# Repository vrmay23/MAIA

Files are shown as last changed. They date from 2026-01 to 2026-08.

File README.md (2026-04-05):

# MAIA
ADAS for blind dogs!

## Third-Party Dependencies

This project uses the VL53L5CX Ultra Lite Driver (ULD) from
STMicroelectronics, licensed under BSD-3-Clause.

The ULD is NOT included in this repository. It is downloaded
automatically at build time via the ESP-IDF Component Manager
using the manifest at `components/drivers/vl53l5cx/idf_component.yml`.

- Source: https://github.com/STMicroelectronics/stm32-vl53l5cx
- License: BSD-3-Clause, (c) STMicroelectronics

### Integration approach

The ST ULD provides the sensor core logic (`vl53l5cx_api.c`)
and expects the user to implement a platform layer (`platform.h`)
with I2C and delay callbacks.

MAIA provides its own `platform.h` and `vl53l5cx_platform.c`
using the ESP-IDF v6.0 new I2C master API. The ST `porting/`
directory is intentionally excluded from the build — only
`modules/vl53l5cx_api.c` is compiled from the ULD.

This keeps the repository 100% Apache 2.0 while the ST ULD
is consumed as an external dependency at build time.

## Building
idf.py build

The Component Manager downloads the ST ULD automatically.
No manual steps required.

## ⚠️ DISCLAIMER

THIS IS AN EXPERIMENTAL OPEN-SOURCE PROJECT FOR EDUCATIONAL
AND RESEARCH PURPOSES ONLY.

No Warranty of Operation: This ADAS system for blind dogs is
provided on an "AS IS" BASIS, without warranties or conditions
of any kind, either express or implied. ToF sensors are subject
to environmental interference, signal noise, blind spots, and
false negatives/positives.

Assumption of Risk: The use of this hardware and firmware on
animals is at the sole discretion and risk of the user/builder.
The author(s) shall not be held liable for any collisions,
injuries, property damage, or any other incidents resulting
from the use or failure of this device.

Not a Medical or Safety Device: This project is NOT a certified
medical or assistive device. It is not a substitute for human
supervision, professional veterinary advice, or proper
orientation training for visually impaired animals.

Hardware Safety: The builder is responsible for ensuring
electrical safety (battery insulation, thermal management) and
mechanical integrity (secure attachment to the animal) to
prevent risks of shock, fire, or physical harm.



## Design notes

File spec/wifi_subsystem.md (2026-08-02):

# MAIA WiFi Subsystem — Design Specification

    Version:   v2.0 (reflects implemented code)
    Date:      2026-08-02
    Author:    Vinicius May
    Target:    ESP32-S3-WROOM-1U-N16R8, ESP-IDF v6.0.0
    Branch:    feat/driver_radio_wifi
    Status:    Phases 1-4 implemented and hardware-verified. Phases 5
               (partial), 6-9 not implemented — see section 15.

    v2.0  Rewritten to describe what actually shipped, not just what was
          designed. Two structural changes from v1.2:

          1. Driver-purity correction. components/drivers/wifi/ no
             longer contains reconnect policy or boot-decision logic
             (v1.2's "RECONNECT POLICY" and MAIA_WIFI_MODE_AUTO
             sections). Both moved to main/tests/test_wifi.c, which
             plays the role of the app/service layer until one exists.
             The driver now does exactly one thing: radio mechanism,
             translated events, nothing else. See section 4.1.

          2. components/services/wifi_prov_service/ implements only
             the ESP-IDF wifi_provisioning manager path (protocomm over
             SoftAP). The custom captive portal designed in v1.1/v1.2
             section 8 (browser path, captive DNS, shared httpd) was
             NOT built — the service directory is also renamed from
             the originally planned wifi_provisioning to
             wifi_prov_service, because that name collides with
             ESP-IDF's own built-in component of the same name.

          Basic LED feedback exists (main/tests/test_wifi.c,
          led_feedback_task()), but as test-code UI glue, not a real
          board service — OLED and buttons are still untouched.

    v1.2  Captive portal designed to coexist with the manager on one
          HTTP server. (Portal never implemented — see v2.0 note.)
    v1.1  Provisioning moved to the IDF wifi_provisioning manager over
          SoftAP.
    v1.0  Initial draft: custom captive portal + WPS.

---

## 1. Purpose and Scope

MAIA needs network connectivity for one reason: **periodically syncing logged
sensor data to a server** (`MAIA_WIFI_SYNC_INTERVAL_MIN`, default 10 min). It
is not a connected product in the always-online sense — it is a
battery-powered harness on a dog that phones home when near a known network.

This document specifies what is actually built:

- the WiFi driver (`components/drivers/wifi/`) — radio mechanism only,
- the provisioning service (`components/services/wifi_prov_service/`) — gets
  the device from "no credentials" to "connected" via the ESP-IDF
  provisioning manager,
- the test harness (`main/tests/test_wifi.c`) — which currently also carries
  the reconnect policy, boot orchestration, and LED feedback that a real
  app/service layer will eventually own,
- the Kconfig surface tying it together.

**Out of scope, not yet started:** the data sync client, OTA, BLE, the
camera, the custom captive portal, OLED/button integration, WPS, MaiaProvApp's
custom endpoints. See section 15 for what each of those needs.

---

## 2. The Core Problem

MAIA must join the tutor's home WiFi. That network's SSID and password are
unknown at build time and differ per user. The device has:

- an SSD1306 128x32 OLED — 4 lines of 25 characters at 5x8 font (not wired to
  WiFi state yet — see section 12),
- one wired button (`BTN_01`, GPIO9) plus one unused (`BTN_02`, GPIO43),
- no keyboard, no touchscreen, no serial access for the end user in the field
  (serial is how *we* debug it on the bench; a tutor will never see it).

### 2.1 On-device text entry is rejected outright

A WPA2 password is up to 63 characters from a 95-character alphabet. With two
buttons the only workable scheme is "next character / confirm" — up to 95
presses per character. **This is not implemented in any form**, and is not
planned. All credential entry happens on the tutor's phone.

### 2.2 The reframing

The device does not need an input UI. **MAIA raises an Access Point, and the
tutor's phone supplies the screen and the keyboard.**

### 2.3 The fact that constrains every option

**A phone cannot read the password of the WiFi network it is currently joined
to.** Android masked `WifiConfiguration.preSharedKey` from the start and closed
the API entirely in Android 10; iOS never exposed it. Consequently **no
transport eliminates typing** — the tutor types the home WiFi password once,
on their own phone, regardless of which client app does the pairing.

### 2.4 Alternatives evaluated

| Approach | Verdict |
|---|---|
| **SoftAP + IDF `wifi_provisioning` manager** | **Implemented.** Proven protocol, crypto and PoP built in. Client today: Espressif's free "ESP SoftAP Prov" app |
| Custom captive portal (HTML + captive DNS) | **Designed (v1.1/v1.2), not implemented.** Its advantage — zero install — didn't get built this pass; the manager path covers the actual need today |
| BLE transport | Not started. One-line scheme swap in the manager config when needed; deferred until MaiaProvApp exists |
| WPS push-button (PBC) | Not started. Optional shortcut, never a dependency, when it lands |
| SmartConfig / ESP-Touch, Web Bluetooth, camera+QR, OLED QR, on-device text entry | Rejected — see v1.x history for the reasoning per option; unchanged in v2.0 |

---

## 3. Solution Overview (as built)

```
Boot (MAIA_TEST_WIFI_MODE_CONNECT, MAIA_WIFI_MODE_PROVISIONING)
 └─> wifi_prov_service_run()
      └─> maia_wifi_is_provisioned()?
           ├─ yes ─> connect directly with stored creds (bounded retry,
           │         no AP raised) — verified on hardware: WPA3-SAE home
           │         network, IP obtained in ~4s
           └─ no  ─> SoftAP "PROV_MAIA_A4F3" + wifi_provisioning manager
                      OLED/LED do not show the PoP yet — it prints to the
                      serial log only (see section 12)
```

| Client | Path | Must install | Status |
|---|---|---|---|
| ESP SoftAP Prov (Espressif) | Standard protocomm endpoints | Their free app | **Implemented, hardware-verified** |
| Phone browser | Captive portal | nothing | Designed (v1.2 §8.4), not built |
| MaiaProvApp (future) | Protocomm + custom endpoints | Our own app | Designed (§9), not built |

The three-client idea from v1.2 — one AP, one shared HTTP server — is
unaffected as a *design*; it simply hasn't been built yet, because only the
protocomm path was in scope for this pass.

---

## 4. Component Architecture

```
components/drivers/wifi/                  ← radio mechanism only
├── include/maia_wifi.h                     public API + SCOPE doc (§4.1)
├── src/maia_wifi.c                         L1 init/deinit, state, is_provisioned()
├── src/maia_wifi_sta.c                     L2 station: start/connect/stop, raw events
├── src/maia_wifi_ap.c                      L3 diagnostic AP
├── src/maia_wifi_scan.c                    L4 scan
├── src/maia_wifi_priv.h                    internal cross-file interface
├── Kconfig                                 empty — see repo convention note below
└── CMakeLists.txt                          vestigial, matches sibling drivers (§4.2)

components/services/wifi_prov_service/    ← provisioning policy
├── include/wifi_prov_service.h             single entry point: wifi_prov_service_run()
├── src/wifi_prov_service.c                 manager lifecycle, PoP, event handling
├── Kconfig                                 empty stub
└── CMakeLists.txt                          real component (§4.3)

main/tests/test_wifi.c                    ← today's stand-in for app/service policy
                                             reconnect policy, boot orchestration,
                                             LED feedback (§4.4)
```

Compared to the file list v1.2 planned (`wifi_prov_portal.c`, `wifi_prov_dns.c`,
`wifi_prov_custom_ep.c`, `wifi_prov_ui.c`, `www/portal.html`), none of those
exist. Only the manager-lifecycle file was built.

### 4.1 The driver-purity correction

Early in this branch, `components/drivers/wifi/` briefly contained a
"reconnect policy" (retry counting, exponential backoff, a give-up decision)
and a `maia_wifi_auto_start()` boot-decision function. On review, both were
recognized as **product policy wearing a driver's clothes** — a NuttX-style
driver exposes primitives and reports raw events; it does not decide how many
times to retry or what the device should do when unconfigured. Both were
removed from the driver:

- The retry/backoff/give-up state machine moved to
  `connect_with_retry_policy()` in `test_wifi.c`, built entirely on the
  driver's public API (`maia_wifi_sta_connect()`, the raw
  `MAIA_WIFI_EVENT_STA_DISCONNECTED` reason code).
- `maia_wifi_auto_start()` was deleted outright; the boot decision
  (`is_provisioned() → connect, else Kconfig seed → connect, else raise the
  diagnostic AP`) is now inlined in `test_wifi_connect()`'s
  `MAIA_WIFI_MODE_AUTO` branch.

This forced two API changes: `maia_wifi_sta_start()` now only brings the
interface up (mode, config, power-save) and no longer calls
`esp_wifi_connect()` itself; a new `maia_wifi_sta_connect()` is the separate,
repeatable primitive a retry loop calls. The state enum lost
`STA_OFFLINE`/`ERROR` (policy conclusions) and the event enum lost
`STA_AUTH_FAILED`/`NO_AP_FOUND` (policy interpretations) — `STA_DISCONNECTED`
now just carries the raw `WIFI_REASON_*` code and lets the caller decide what
it means.

**`maia_wifi_is_provisioned()` stayed in the driver.** It is a read-only query
against `esp_wifi`'s own persisted config — it doesn't decide anything, only
reports a fact — which is different in kind from the boot orchestration that
moved out.

### 4.2 Why `components/drivers/wifi/CMakeLists.txt` is unused

ESP-IDF's component discovery is non-recursive: it only looks at immediate
children of `components/`. Since `components/drivers` itself has a
`CMakeLists.txt` (the real aggregator, hand-listing every driver's sources),
IDF never looks inside `components/drivers/wifi/` for a nested component —
its `CMakeLists.txt` is display-only, matching the same (also-unused) pattern
already present in `mpu6050/`, `ssd1306/`, `lsm6dsox/`. The actual build
wiring is in `components/drivers/CMakeLists.txt`'s `DRV_SRCS` list, gated on
`CONFIG_MAIA_WIFI_ENABLE`.

### 4.3 Why `wifi_prov_service` needed a name change and `EXTRA_COMPONENT_DIRS`

Two build-system issues surfaced while wiring this component in, both fixed
and worth recording so they aren't rediscovered the hard way:

1. **Name collision.** The service was originally going to live at
   `components/services/wifi_provisioning/` — but ESP-IDF ships its own
   built-in component named exactly `wifi_provisioning`
   (`$IDF_PATH/components/wifi_provisioning`, the manager itself). Two
   same-named components in the build graph is ambiguous. Renamed the
   directory (and the header/source files) to `wifi_prov_service`.

2. **`components/services/` is one level too deep to auto-discover.** IDF's
   default component search is `components/` plus anything in
   `EXTRA_COMPONENT_DIRS`, and for each of those it only looks at *immediate*
   subdirectories. `components/services/wifi_prov_service/` is two levels
   under `components/`, so without help it is invisible — confirmed by
   checking `project_description.json`'s `all_component_info`: the five
   pre-existing `services/*` stubs (`obstacle_detection`, `haptic_feedback`,
   `power_manager`, `data_logger`, `status_monitor`) were *never* being
   discovered at all before this change, despite having real
   `idf_component_register()` calls in their `CMakeLists.txt` — dormant
   scaffolding, not dead code. Fixed by adding
   `set(EXTRA_COMPONENT_DIRS "${CMAKE_CURRENT_LIST_DIR}/components/services")`
   to the root `CMakeLists.txt`, which incidentally makes those five
   pre-existing stubs discoverable too (still not wired into `main`'s
   `REQUIRES`, so they remain inert).

3. **A `REQUIRES` gotcha, distinct from the two above.** Once discoverable,
   `wifi_prov_service` still needed to not be compiled when
   `MAIA_WIFI_ENABLE=n` (its code uses Kconfig symbols that live inside
   `depends on MAIA_WIFI_ENABLE` menus and vanish from `sdkconfig.h`
   entirely when it's off). The obvious fix —
   `if(CONFIG_MAIA_WIFI_ENABLE) list(APPEND ... wifi_prov_service) endif()`
   around the `REQUIRES` argument — **does not work**: ESP-IDF resolves each
   component's `REQUIRES`/`PRIV_REQUIRES` in an early pass, before Kconfig
   values from the actual `sdkconfig` are reliably available, so the
   conditional silently evaluates against a stale/default context rather
   than the real configuration (confirmed by hitting it directly: the
   component vanished from `main`'s resolved `reqs` even with
   `MAIA_WIFI_ENABLE=y` set on disk). `SRCS` conditionals do not have this
   problem — they're evaluated later, with the real `sdkconfig` in hand,
   which is why `test_wifi.c`'s inclusion is still safely gated that way.
   The fix: `wifi_prov_service` is `REQUIRES`'d **unconditionally**, and
   `wifi_prov_service.c`'s entire body (past the includes) is wrapped in
   `#if CONFIG_MAIA_WIFI_ENABLE ... #endif`, so the component always builds
   but compiles to an empty, harmless translation unit when WiFi is off.

### 4.4 Why policy still lives in test code

`components/app/src/app.c`'s `app_init()` is still a TODO stub — nothing in
the real application calls into WiFi at all yet. Until that changes,
`main/tests/test_wifi.c` (`MAIA_TEST_WIFI_MODE_CONNECT`) is the only caller,
so it necessarily carries what an app/service layer will eventually own:
`connect_with_retry_policy()`, the `MAIA_WIFI_MODE` boot-decision branches, and
`led_feedback_task()`. None of this is exercised by production code today —
moving it there is future work, not a rename.

---

## 5. Kconfig Design (as implemented)

Replaces the original `menu "WiFi Configuration"` in
`components/maia_board/Kconfig`. Per this repo's convention (confirmed by
inspecting every existing driver), **all Kconfig content lives in
`components/maia_board/Kconfig`** — the per-component `Kconfig` files
(`components/drivers/wifi/Kconfig`, `components/services/wifi_prov_service/Kconfig`)
are empty stubs matching the rest of the tree, not the per-component split the
v1.x drafts of this document assumed.

### 5.1 Mode selection

```kconfig
choice MAIA_WIFI_MODE
    prompt "WiFi operating mode"
    depends on MAIA_WIFI_ENABLE
    default MAIA_WIFI_MODE_AUTO
    help
        Selects what the device should do at boot. Not read by the
        driver — this is consulted by whatever code orchestrates the
        driver's primitives (currently MAIA_TEST_WIFI_MODE_CONNECT in
        test_wifi.c).

    config MAIA_WIFI_MODE_AUTO
        bool "Auto (stored credentials -> STA, else diagnostic AP)"

    config MAIA_WIFI_MODE_STA
        bool "Station only (credentials from Kconfig)"

    config MAIA_WIFI_MODE_AP
        bool "Access Point only (diagnostic)"

    config MAIA_WIFI_MODE_PROVISIONING
        bool "Interactive provisioning (SoftAP + phone app)"
        help
            If already provisioned, connect directly. Otherwise raise
            a SoftAP and run the ESP-IDF wifi_provisioning manager
            (protocomm, security 1) so a phone can supply credentials
            at runtime. Client today: "ESP SoftAP Prov" (Espressif).
endchoice
```

**Important correction from an early version of this Kconfig:** the
"Station" and "Access Point (diagnostic)" submenus originally had
`depends on !MAIA_WIFI_MODE_AP` / `!MAIA_WIFI_MODE_STA` respectively — hiding
each other's config when one mode was selected, as a menuconfig UX nicety.
**This broke the build** the moment any mode other than the "obviously
relevant" one was selected: `components/drivers/CMakeLists.txt` compiles
`maia_wifi_ap.c` and the Station code paths *unconditionally* whenever
`MAIA_WIFI_ENABLE=y` (any mode might call `maia_wifi_ap_start()` at runtime —
e.g. Auto's fallback), and `wifi_prov_service.c` unconditionally reads
`MAIA_WIFI_STA_MAX_RETRY` for its already-provisioned connect path — so
hiding those Kconfig symbols under a mode condition made them vanish from
`sdkconfig.h` while still-compiled code referenced them. Both `depends on`
clauses were changed to depend only on `MAIA_WIFI_ENABLE`.

### 5.2 Station and diagnostic AP

Unchanged in shape from v1.2's design (`MAIA_WIFI_STA_SSID/PASSWORD`,
`MAIA_WIFI_STA_MAX_RETRY`, `MAIA_WIFI_STA_RETRY_BACKOFF_MS`,
`MAIA_WIFI_STA_POWER_SAVE`, `MAIA_WIFI_SYNC_INTERVAL_MIN`;
`MAIA_WIFI_AP_SSID_PREFIX/_APPEND_MAC/_PASSWORD/_CHANNEL/_MAX_CONN`) — see
section 5.1's correction for the `depends on` fix. `MAIA_WIFI_STA_MAX_RETRY`'s
help text now documents **two** consumers instead of one:
`test_wifi.c`'s reconnect-policy demo, and `wifi_prov_service`'s
`wifi_conn_attempts` (passed straight through to the manager).

### 5.3 Interactive Provisioning (implemented; replaces v1.2's broader design)

```kconfig
menu "Interactive Provisioning"
    depends on MAIA_WIFI_ENABLE

    config MAIA_WIFI_PROV_SSID_PREFIX
        string "Provisioning AP SSID prefix"
        default "PROV_MAIA"
        help
            The stock "ESP SoftAP Prov" app filters its scan results
            by prefix, defaulting to "PROV_". Keep it while that app
            is the client.

    config MAIA_WIFI_PROV_SSID_APPEND_MAC
        bool "Append MAC suffix to the provisioning AP SSID"
        default y

    choice MAIA_WIFI_PROV_AP_SECURITY
        prompt "Provisioning AP link security"
        default MAIA_WIFI_PROV_AP_WPA2_MAC

        config MAIA_WIFI_PROV_AP_WPA2_MAC
            bool "WPA2, password derived from device MAC"
        config MAIA_WIFI_PROV_AP_WPA2_STATIC
            bool "WPA2, static password from Kconfig"
        config MAIA_WIFI_PROV_AP_OPEN
            bool "Open network (protocomm encryption only)"
    endchoice

    config MAIA_WIFI_PROV_AP_PASSWORD
        string "Static provisioning AP password (min 8 chars)"
        default "maiamute2026"
        depends on MAIA_WIFI_PROV_AP_WPA2_STATIC

    choice MAIA_WIFI_PROV_SECURITY
        prompt "Provisioning session security"
        default MAIA_WIFI_PROV_SEC1

        config MAIA_WIFI_PROV_SEC1
            bool "Security 1 (X25519 + AES-CTR, PoP)"
            select ESP_PROTOCOMM_SUPPORT_SECURITY_VERSION_1
        config MAIA_WIFI_PROV_SEC0
            bool "Security 0 (none)"
            select ESP_PROTOCOMM_SUPPORT_SECURITY_VERSION_0
    endchoice

    config MAIA_WIFI_PROV_POP_DIGITS
        int "Proof-of-possession code length (digits)"
        default 6
        range 4 8
        depends on MAIA_WIFI_PROV_SEC1

    config MAIA_WIFI_PROV_POP_STATIC
        string "Static PoP code (empty = random per session)"
        default ""
        depends on MAIA_WIFI_PROV_SEC1
        help
            Set to script provisioning with tools/esp_prov/esp_prov.py
            without reading a fresh code off the serial log every run.
            Leave empty for real use.

    config MAIA_WIFI_PROV_TIMEOUT_MIN
        int "Provisioning timeout (minutes, 0 = never)"
        default 10
        range 0 60
endmenu
```

**Differences from the v1.2 design:**

- **No `MAIA_WIFI_PROV_SECURITY_SEC2` (SRP6a).** The current `sdkconfig`
  ships with `ESP_PROTOCOMM_SUPPORT_SECURITY_VERSION_2=y` by default and
  `_0`/`_1` both disabled — meaning `WIFI_PROV_SECURITY_0`/`_1` don't even
  exist as enum values until something `select`s them in. Each of our two
  security choices does exactly that (`select
  ESP_PROTOCOMM_SUPPORT_SECURITY_VERSION_{0,1}`), so the build works
  regardless of prior `sdkconfig` state. SEC2 needs build-time salt/verifier
  generation from a username/password pair that isn't implemented — same
  reasoning v1.2 gave for deferring it, unchanged.
- **`MAIA_WIFI_PROV_POP_STATIC` is new** — not in any v1.x draft. Added for
  bench/scripting convenience (`esp_prov.py` automation without reading a
  fresh random code off the serial log every session).
- **No `MAIA_WIFI_PROV_IFACE_PROTOCOMM` / `_IFACE_PORTAL` / `_CUSTOM_EP` /
  `MAIA_WIFI_PROV_CLIENT`.** These v1.2 symbols existed to let the (never
  built) portal and the manager coexist, and to gate the (never built)
  custom endpoints for MaiaProvApp. None of that code exists, so — per this
  project's working rule of never shipping a Kconfig option with no
  implementation behind it — none of those symbols exist either. When the
  portal or the custom endpoints get built, their Kconfig lands with them.

### 5.4 Status indication

```kconfig
menu "Status indication"
    depends on MAIA_WIFI_ENABLE

    config MAIA_LED_BLINK_FREQ_AP_HZ
        int "LED blink frequency in AP mode (Hz)"
        default 5
        range 1 100

    config MAIA_LED_BLINK_FREQ_STA_HZ
        int "LED blink frequency while connecting (Hz)"
        default 1
        range 1 100
endmenu
```

These two symbols predate this branch (originally both defaulted to 10 Hz,
which conveys no information since a single indistinguishable rate can't tell
two states apart — fixed to 5/1 Hz here). They are now actually consumed, by
`test_wifi.c`'s `led_feedback_task()` (section 8.4) — previously they were
declared but nothing read them.

### 5.5 Test Kconfig

`MAIA_TEST_WIFI_MODE` has **three** options, not five:

```kconfig
choice MAIA_TEST_WIFI_MODE
    prompt "WiFi test mode"
    depends on MAIA_TEST_WIFI
    default MAIA_TEST_WIFI_MODE_SUITE

    config MAIA_TEST_WIFI_MODE_SUITE
        bool "Basic test suite"
    config MAIA_TEST_WIFI_MODE_SCAN
        bool "Network scan"
    config MAIA_TEST_WIFI_MODE_CONNECT
        bool "Exercise connectivity (per WiFi operating mode)"
        help
            Runs whatever MAIA_WIFI_MODE selects — Auto / Station / AP
            / Provisioning — entirely from code outside the driver.
endchoice

config MAIA_TEST_WIFI_LED_FEEDBACK
    bool "Blink status LED to reflect WiFi state"
    default y
    depends on MAIA_TEST_WIFI_MODE_CONNECT
    help
        Runs led_feedback_task() (section 8.5) alongside the
        connectivity test. Disable to isolate an LED-related symptom
        from the blink task itself, or if the status LED isn't wired
        the way MAIA_LED_STATUS_GPIO expects on a given board revision.
```

**`CONFIG_MAIA_TEST_WIFI` depends on `MAIA_WIFI_ENABLE`, same as every other
device test in this codebase depends on its device being enabled** (compare
`MAIA_TEST_TEMPERATURE_SENSOR` → `MAIA_DS18B20_ENABLE`, `MAIA_TEST_IMU` →
`MAIA_IMU_MPU6050`). This is not a special case introduced by this feature —
it's the established pattern. It surfaced as confusing in practice once:
with `MAIA_WIFI_ENABLE` toggled off (no comment line for it appears in
`sdkconfig` at all when off — Kconfig emits nothing, not even
`# CONFIG_MAIA_TEST_WIFI is not set`, for a symbol whose `depends on` isn't
satisfied), the entire WiFi test vanishes from `menuconfig` with no visible
trace of why. The test was never missing; the device it depends on was off.

An earlier iteration had five options (`SUITE`/`SCAN`/`STA`/`AP`/`AUTO`),
duplicating the concept `MAIA_WIFI_MODE` already existed to express.
Collapsed into `CONNECT`, whose behavior branches on the (kept, unchanged)
`MAIA_WIFI_MODE` choice — one boot-mode concept, not two.

---

## 6. State Machine (as implemented)

The driver's own state machine is now deliberately small — see section 4.1:

```mermaid
stateDiagram-v2
    [*] --> IDLE
    IDLE --> STA_CONNECTING: maia_wifi_sta_connect()
    STA_CONNECTING --> STA_CONNECTED: IP_EVENT_STA_GOT_IP
    STA_CONNECTING --> IDLE: WIFI_EVENT_STA_DISCONNECTED
    STA_CONNECTED --> IDLE: WIFI_EVENT_STA_DISCONNECTED
    IDLE --> AP_RUNNING: maia_wifi_ap_start()
    AP_RUNNING --> IDLE: maia_wifi_ap_stop()
```

No "give up", "offline", or "error" state exists in the driver — a disconnect
always lands back in `IDLE` with the raw reason code handed to the caller.
Everything downstream of that (section 4.4 / 8) is the caller's problem:

```mermaid
stateDiagram-v2
    [*] --> Idle
    Idle --> Connecting: sta_start() + sta_connect()
    Connecting --> Connected: STA_GOT_IP
    Connecting --> Connecting: STA_DISCONNECTED (auth/transient, retries left)\nbackoff, sta_connect() again
    Connecting --> GaveUp: STA_DISCONNECTED (auth, retries exhausted)
    Connecting --> GaveUp: STA_DISCONNECTED (out of range) — no retry at all
    Connecting --> GaveUp: STA_DISCONNECTED (transient, retries exhausted)
    Connected --> [*]
    GaveUp --> [*]
```

This second diagram is `connect_with_retry_policy()` in `test_wifi.c` — it
does not exist as driver states, only as caller-side logic reacting to the
driver's plain events.

---

## 7. Driver API — `maia_wifi.h` (as implemented)

```c
typedef enum
{
  MAIA_WIFI_STATE_IDLE = 0,
  MAIA_WIFI_STATE_STA_CONNECTING,
  MAIA_WIFI_STATE_STA_CONNECTED,
  MAIA_WIFI_STATE_AP_RUNNING,
} maia_wifi_state_t;

typedef enum
{
  MAIA_WIFI_EVENT_STA_CONNECTED = 0,  /* L2 associated, no IP yet        */
  MAIA_WIFI_EVENT_STA_DISCONNECTED,   /* data -> stack-local uint8_t
                                       * raw WIFI_REASON_* code, valid
                                       * only for the callback's
                                       * duration                        */
  MAIA_WIFI_EVENT_STA_GOT_IP,
  MAIA_WIFI_EVENT_AP_STARTED,
  MAIA_WIFI_EVENT_AP_CLIENT_JOINED,
  MAIA_WIFI_EVENT_AP_CLIENT_LEFT,
  MAIA_WIFI_EVENT_SCAN_DONE,
} maia_wifi_event_t;

/* L1 - Core */
esp_err_t          maia_wifi_init(maia_wifi_callback_t cb);
esp_err_t          maia_wifi_deinit(void);
maia_wifi_state_t  maia_wifi_get_state(void);
esp_err_t          maia_wifi_get_mac_suffix(char *out, size_t len);
bool               maia_wifi_is_provisioned(void);

/* L2 - Station (bring-up and association are separate primitives —
 *      this is what makes a caller-side retry loop possible without
 *      redoing setup each attempt) */
esp_err_t maia_wifi_sta_start(const maia_wifi_creds_t *creds);  /* NULL = stored */
esp_err_t maia_wifi_sta_connect(void);
esp_err_t maia_wifi_sta_stop(void);
esp_err_t maia_wifi_sta_get_ip(esp_netif_ip_info_t *ip);
esp_err_t maia_wifi_sta_get_rssi(int8_t *rssi);

/* L3 - Access Point (diagnostic only) */
esp_err_t maia_wifi_ap_start(void);
esp_err_t maia_wifi_ap_stop(void);

/* L4 - Scan */
esp_err_t maia_wifi_scan(maia_wifi_ap_info_t *results, size_t max,
                         size_t *found);
```

Removed relative to earlier drafts: `maia_wifi_auto_start()` (section 4.1),
`MAIA_WIFI_STATE_STA_OFFLINE`/`_ERROR`, `MAIA_WIFI_EVENT_STA_AUTH_FAILED`/
`_NO_AP_FOUND`. No WPS (L5) — not started.

---

## 8. Provisioning Service — `wifi_prov_service` (as implemented)

### 8.1 Entry point

```c
esp_err_t wifi_prov_service_run(void);   /* blocking */
```

That is the entire public API. It:

1. Calls `maia_wifi_init(NULL)` — idempotent (no-ops if the caller already
   initialized the driver, e.g. `test_wifi_run()` does, with its own
   callback; `wifi_prov_service_run()` doesn't need a driver-level callback
   of its own since it polls state / uses the manager's dedicated callback
   instead — see 8.3).
2. Branches on `maia_wifi_is_provisioned()`:
   - **true** → `connect_stored_credentials()`: `maia_wifi_sta_start(NULL)`,
     then up to `MAIA_WIFI_STA_MAX_RETRY` rounds of `maia_wifi_sta_connect()`
     with a bounded per-attempt timeout, polling `maia_wifi_get_state()`.
     Deliberately simpler than `test_wifi.c`'s reconnect-policy demo (no
     reason-code classification, no exponential backoff) — this is the
     service's own, plainer "just try N times" policy for the boring case
     where credentials already work.
   - **false** → `run_interactive_provisioning()` (8.2).

### 8.2 Interactive provisioning

```c
wifi_prov_mgr_config_t cfg = {
    .scheme               = wifi_prov_scheme_softap,
    .scheme_event_handler = WIFI_PROV_EVENT_HANDLER_NONE,
    .app_event_handler    = { .event_cb = prov_event_cb, .user_data = &ctx },
    .wifi_prov_conn_cfg   = { .wifi_conn_attempts = CONFIG_MAIA_WIFI_STA_MAX_RETRY },
};
wifi_prov_mgr_init(cfg);
/* build_service_name() -> "PROV_MAIA_A4F3" (prefix + MAC suffix, reusing
 * maia_wifi_get_mac_suffix()) */
/* build_ap_password() -> MAC-derived / static / NULL (open), per Kconfig */
/* build_pop() -> MAIA_WIFI_PROV_POP_STATIC if set, else N random digits
 * from esp_random() */
wifi_prov_mgr_start_provisioning(WIFI_PROV_SECURITY_1, pop, ssid, service_key);
/* block on an EventGroup for CRED_SUCCESS or CRED_FAIL, with a timeout
 * derived from MAIA_WIFI_PROV_TIMEOUT_MIN (or portMAX_DELAY if 0) */
```

`prov_event_cb()` (the manager's `app_event_handler`, not a
`maia_wifi_callback_t` — a separate, dedicated callback slot with no
interaction with the driver's own callback) maps
`WIFI_PROV_START/CRED_RECV/CRED_FAIL/CRED_SUCCESS/END` to log lines and
`EventGroup` bits. **It logs the received SSID, never the password** —
confirmed by direct code review when the question came up during testing.
On `CRED_SUCCESS` the manager auto-stops itself (emits `WIFI_PROV_END` on its
own); on `CRED_FAIL` or timeout, `wifi_prov_mgr_stop_provisioning()` is called
explicitly. Either way, `wifi_prov_mgr_deinit()` follows once `WIFI_PROV_END`
is observed (or a bounded wait for it elapses).

On success, **the station is already connected** — the manager did the
`esp_wifi_connect()` internally as part of verifying the submitted
credentials. The caller does not need to call `maia_wifi_sta_start()`/
`_connect()` afterward; `maia_wifi_get_state()` already reflects
`STA_CONNECTED` because the driver's event handlers observe `WIFI_EVENT`/
`IP_EVENT` unconditionally, regardless of who initiated the connection
attempt (see the "no conflict" note in `wifi_prov_service.h`).

### 8.3 No conflict with the driver, verified

This was a design requirement, not just a hope, and it held up under actual
hardware testing:

- The driver's own STA/AP event handlers keep running the entire time the
  manager is active — they only translate events into driver state, never
  call `esp_wifi_connect()`/`disconnect()`/`set_mode()` themselves (only
  `maia_wifi_sta_start()`/`_connect()`/`_stop()` and `maia_wifi_ap_start()`/
  `_stop()` do that), and this service never calls those while the manager
  owns the radio.
- `maia_wifi_init()`'s `g_initialized` guard makes the service's own call to
  it a safe no-op when the caller (`test_wifi_run()`) already initialized the
  driver with its own callback.
- Hardware confirmation: a real device, already provisioned onto a WPA3-SAE
  home network, connected cleanly through `connect_stored_credentials()` —
  associated, negotiated WPA3-SAE, got an IP, all while the driver's ordinary
  event handlers ran throughout with no interference.

### 8.4 What is not implemented

- **Custom captive portal** (v1.2 §8.1/8.4/8.6: shared `httpd`, browser
  handlers, captive DNS, `portal.html`). Zero of that code exists. The
  `wifi_prov_scheme_softap_set_httpd_handle()` mechanism v1.2 designed around
  is unused because there is no second httpd to share it with.
- **OLED/LED/button UI** for provisioning (v1.2 §12). The PoP code, AP name,
  and password print to the **serial log only** — there is no on-device
  display of any of it. This matters operationally: a tutor in the field has
  no way to read the PoP code today. Basic LED *is* implemented, but as
  generic WiFi-state feedback in test code (section 8.5 below), not
  provisioning-specific UI.
- **Custom protocomm endpoints** for MaiaProvApp (section 9). Reserved in
  design, no code.
- **WPS.** Not started.

### 8.5 LED feedback (new in this pass, lives in test code)

`main/tests/test_wifi.c`'s `led_feedback_task()` polls
`maia_wifi_get_state()` every 50 ms and drives the board's status LED:

| State | LED |
|---|---|
| `AP_RUNNING` | blink at `MAIA_LED_BLINK_FREQ_AP_HZ` |
| `STA_CONNECTING` | blink at `MAIA_LED_BLINK_FREQ_STA_HZ` |
| `STA_CONNECTED` | solid on |
| `IDLE` | off |

Started at the top of `test_wifi_connect()` whenever
`CONFIG_MAIA_TEST_WIFI_LED_FEEDBACK` is set (default y, section 5.5), so it
reflects whichever `MAIA_WIFI_MODE` branch is active — including the
Provisioning one, where it is the *only* on-device feedback of state right
now (no OLED text). Both the task and its call site are compiled out
entirely when the option is off — not just skipped at runtime.
This is UI glue, explicitly not driver code, for the same reasoning as
section 4.1 — and explicitly not yet a real board service, since it lives in
test code with no app/service layer to move into yet.

---

## 9. Preparing for MaiaProvApp

Unchanged in intent from v1.2: the manager's wire protocol doesn't change
when a custom client replaces the stock app, and a transport swap
(`wifi_prov_scheme_softap` → `_ble`) is a one-line change if ever needed.

**Correction from v1.2:** there is no `MAIA_WIFI_PROV_CUSTOM_EP` Kconfig
symbol today (section 5.3) — it will be added together with the actual
endpoint implementations, not before. The reserved endpoint names and
payload shapes from v1.2 §9.1 (`maia-info`, `maia-record`, `maia-server`)
remain the intended design; none are implemented.

---

## 10. Credential Storage

Unchanged from v1.1/v1.2 and confirmed by the implementation: no MAIA-owned
store. `maia_wifi_is_provisioned()` and the manager's own
`wifi_prov_mgr_is_provisioned()` both read `esp_wifi_get_config(WIFI_IF_STA,
...)` — literally the same check (confirmed by reading the ESP-IDF source
directly: `manager.c`'s implementation is the identical `strlen(ssid) > 0`
test). No parallel copy exists to disagree with it.

---

## 11. Security Model (as implemented)

### 11.1 What's actually true today

Because the custom portal was never built, **the PoP is always
cryptographically bound** — there is no weaker, application-level PoP check
existing in parallel (v1.2 §11.3 spent significant space on an asymmetry
between a crypto-bound protocomm path and a rate-limited portal path; that
asymmetry does not exist in the shipped system, because only the protocomm
path exists). Under Security 1, the PoP string is mixed into the X25519
session-key derivation; a wrong code produces a key that cannot decrypt
anything the device sends — not an application-level rejection, and nothing
to rate-limit because there's no comparison to brute-force.

### 11.2 Threat model, updated

| Attack | Defence |
|---|---|
| Associate to the provisioning AP | Per-device WPA2 password (MAC-derived by default) |
| Complete a protocomm session without the PoP | Cryptographically impossible under Security 1 — wrong PoP yields a session key that can't decrypt the exchange |
| Brute-force the PoP online | Each guess costs a full handshake against a device only listening for `MAIA_WIFI_PROV_TIMEOUT_MIN` minutes |
| Sniff the submitted home-WiFi password | protocomm encrypts end to end, independent of the AP's own WPA2 |
| Force the device into setup mode | Only reachable when unprovisioned, or (once implemented) by explicit button press |

### 11.3 AP link security

`MAIA_WIFI_PROV_AP_WPA2_MAC` (default) derives the AP password from the base
MAC — implemented via `build_ap_password()`: `snprintf("MAIA%02X%02X%02X%02X",
mac[2..5])`, always ≥8 chars so it's always valid WPA2. Static and open
options exist for bench work, matching the original design.

### 11.4 No TLS — still correct, for a narrower reason now

v1.2 argued TLS would break captive-portal auto-detection. Since there is no
portal, that specific argument no longer applies — but the underlying
conclusion is unchanged: there's no third party on the path, and protocomm
already encrypts the payload end to end regardless of the WiFi link's own
security. Adding TLS on top would add certificate/clock problems for zero
security gain.

### 11.5 Where the real risk lives

Unchanged from v1.2 §11.6: the data sync client, not provisioning, once that
exists.

---

## 12. User Experience (current state — mostly not built)

### 12.1 What exists

Only the LED pattern in section 8.5. No OLED screens, no button-triggered
entry into provisioning, no PoP/AP-name/password displayed anywhere the tutor
could see — all of that only prints to the serial log (`ESP_LOGW`), which is
a bench/developer channel, not something a tutor in the field has access to.

### 12.2 What v1.2 designed and remains unbuilt

The two-screen OLED rotation (AP credentials / PoP code), the failure
screens with recovery instructions, the `BTN_01`/`BTN_02` mapping table, and
the multi-button driver prerequisite it depends on — all as originally
specified in v1.2 §12, none implemented. This is the actual gap between
"MAIA can be provisioned by an engineer with a laptop and a serial monitor"
(true today) and "MAIA can be provisioned by a tutor with just a phone" (not
yet true, since the tutor has no way to read the PoP code without serial
access).

---

## 13. Platform Constraints and Known Gotchas

Carried over from v1.2 (WROOM-1U needs an external antenna; ESP32-S3 is
2.4 GHz only; AP+STA share one radio/channel; endpoint registration
ordering — n/a now, no custom endpoints exist yet), plus what this pass
found in practice:

1. **WPA3-SAE works, confirmed on real hardware.** A home router running
   WPA3-SAE-only was initially suspected as a blocker; the device associated,
   negotiated `security: WPA3-SAE`, and obtained an IP without any code
   changes. ESP32-S3's WiFi stack supports SAE natively — this was never a
   real constraint, just an untested assumption.
2. **The manager's own fail-reason classification is narrower than expected,
   and can misreport.** `wifi_provisioning`'s `manager.c` only recognizes
   five `WIFI_REASON_*` codes as `WIFI_PROV_STA_AUTH_ERROR`
   (`AUTH_FAIL`, `HANDSHAKE_TIMEOUT`, `4WAY_HANDSHAKE_TIMEOUT`,
   `MIC_FAILURE`) or `WIFI_PROV_STA_AP_NOT_FOUND` (`NO_AP_FOUND`). Anything
   else — including the very common `WIFI_REASON_BEACON_TIMEOUT` (weak or
   unstable signal) — falls through a `default:` case that, with
   `wifi_conn_attempts != 0` (our configuration), leaves the fail reason at
   whatever it last was, which starts zero-initialized to
   `WIFI_PROV_STA_AUTH_ERROR`. **A weak-signal disconnect can be reported to
   the app as "wrong password" even when the password was correct.** This is
   an ESP-IDF library behavior, not something this project's code controls;
   the actual raw code is still visible in the log
   (`manager.c`: `ESP_LOGE(TAG, "Disconnect reason : %d", ...)`) before the
   misclassification happens, and is the reliable way to diagnose a
   "provisioning failed" report that doesn't match reality.
3. **`esp_random()` requires `#include <esp_random.h>`**, and MAC reads need
   `#include <esp_mac.h>` — both moved out of `esp_system.h`'s automatic
   includes in a recent ESP-IDF reorganization; the build gives a direct hint
   when this bites (`hint: esp_mac.h header file is not included by
   esp_system.h anymore`).
4. **`freertos/event_groups.h` is plural** (`event_group.h` doesn't exist) —
   caught immediately by the build, mentioned here only because it's an easy
   typo to repeat.
5. See section 4.3 for the three build-system gotchas (name collision,
   `EXTRA_COMPONENT_DIRS` depth, `REQUIRES`-vs-`SRCS` Kconfig-conditional
   reliability) — these cost more debugging time than any WiFi-specific
   issue in this pass.

---

## 14. Test Plan (as implemented)

`MAIA_TEST_WIFI` under `MAIA_TEST_SELECT`, with `MAIA_TEST_WIFI_MODE`
choosing one of three (section 5.5):

| Sub-test | Coverage |
|---|---|
| `SUITE` | init/deinit, MAC suffix formatting, `is_provisioned()` against `esp_wifi`'s stored config, state transitions with no radio activity |
| `SCAN` | Scan and print visible networks (SSID, RSSI, channel, auth mode) — also the fastest antenna sanity check |
| `CONNECT` | Runs whichever `MAIA_WIFI_MODE` selects (Auto/Station/AP/Provisioning), including the reconnect-policy demo and LED feedback. **Hardware-verified**: AP mode (phone joined, join/leave logged), Provisioning mode (already-provisioned direct connect to a WPA3-SAE network, IP obtained, no crash after fixing the NULL-queue bug below) |

**Bug found and fixed during hardware testing:** `connect_event_cb()` (the
callback registered for the whole `CONNECT` sub-test, regardless of which
`MAIA_WIFI_MODE` branch runs) unconditionally forwarded `GOT_IP`/
`DISCONNECTED` events into a queue (`s_sta_evt_q`) that is only created inside
`connect_with_retry_policy()` — used by the Auto/Station branches. The
Provisioning branch connects via `wifi_prov_service_run()` instead, never
creating that queue, yet the same globally-registered callback still fired on
its events. Result: a real device, the moment it successfully obtained an IP
through Provisioning mode, hit `xQueueGenericSend` on a NULL queue handle and
asserted/rebooted — a crash exactly *at* the moment of success. Fixed with a
NULL check at the top of the callback. Caught by a user running the actual
hardware, not by any build-time check — this class of bug (a shared callback
assuming state that only some of its callers set up) is exactly what
hardware-in-the-loop testing catches and static analysis doesn't.

Not yet exercised on hardware: `AUTO` and `STA` branches with real credentials
(only `PROVISIONING` and diagnostic `AP` have been). `esp_prov.py`-scripted
testing (mentioned in v1.2) has not been tried.

---

## 15. Implementation Phases — status

| Phase | v1.2 plan | Status |
|---|---|---|
| **1** | Kconfig + driver L1-L2 + STA test | **Done**, then corrected (section 4.1) |
| **2** | Auto boot logic + reconnect policy | **Done, relocated** to `test_wifi.c` (section 4.1) — not in the driver as originally planned |
| **3** | L3-L4 diagnostic AP + scan | **Done**, hardware-verified |
| **4** | Provisioning service: httpd owner, manager as tenant, PoP, events | **Done, narrower than planned** — manager only, no shared httpd (nothing to share it with), no custom portal |
| **5** | UI glue: OLED, LED, button entry | **Partial.** LED done (test code, generic WiFi-state feedback, not provisioning-specific). OLED, button entry: not started |
| **6** | Browser portal | **Not started** |
| **7** | WPS | **Not started** |
| **8** | Multi-button + factory reset | **Not started** |
| **9** | Custom endpoints for MaiaProvApp | **Not started** |

**The practical gap today:** an engineer with a laptop and a serial monitor
can provision a MAIA unit right now, end to end, on real hardware. A tutor in
the field cannot — they have no way to read the PoP code or the AP
credentials without serial access. Closing that gap is phase 5 (OLED +
button entry), not a new phase.

---

## 16. Open Questions

1. ~~Per-device AP password~~ — **Resolved, implemented**: MAC-derived by
   default (section 11.3).
2. ~~Custom portal or IDF manager?~~ — **Resolved differently than v1.2
   planned**: manager only, this pass. Portal remains a future option, not
   coexisting with anything today since it doesn't exist.
3. **Reboot after provisioning, or live transition to STA?** Still open.
   Current behavior: neither explicitly — the manager's own internal
   `esp_wifi_connect()` during credential verification *is* the transition;
   nothing reboots the device afterward. Whether that's the right long-term
   behavior (vs. explicitly rebooting for a clean state) is unresolved.
4. **Should `maia-record` supersede or mirror the Kconfig animal/tutor
   fields?** Unchanged from v1.2 — still open, still blocked on phase 9.
5. **Sync client transport** — still out of scope, still undecided.
6. **BLE as a second transport** — still deferred to when MaiaProvApp exists.
7. **New: who reads the PoP code in the field?** Not a v1.2 question, because
   v1.2 assumed the OLED would show it by the time this mattered. It does
   not yet. This is the practical blocker on "provisioning by a tutor" vs.
   "provisioning by an engineer," and should be resolved by actually building
   phase 5, not by further design discussion — the design (section 12,
   carried from v1.2) is already adequate.

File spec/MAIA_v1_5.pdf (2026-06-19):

Copyright 2026 Vinicius May - Apache License 2.0 Page 1 of -

# MAIA

## Motion Assistance for Impaired Animals Wearable ADAS System for Blind Dogs

Parameter | Value
Prototype Platform | XIAO ESP32S3 Plus
Production Target | ESP32-S3-WROOM-1U-N16R8
Framework | ESP-IDF v6.0 + FreeRTOS
Battery | 26650 Li-Ion (5000mAh) - Removable
Target Runtime | 24+ hours (camera off)
Main Unit Size | 70 x 30 x 30 mm
Motor Sleeve | Adjustable, fits any collar
Version | 1.5
Date | April 2026

Copyright 2026 Vinicius May - Apache License 2.0 Page 2 of -

# Table of Contents

1. Changelog from v1.4
2. Project Overview
3. System Architecture
4. Hardware Design
5. Motor Driver Circuit
6. Pinout Configuration
7. Camera Subsystem
8. IMU: LSM6DSOX
9. Power Management
10. USB Subsystem
11. Mechanical Design
12. Motor Sleeve System
13. Haptic Feedback System
14. Display Interface
15. Firmware Architecture
16. VL53L5CX Driver API (MAIA)
17. Bill of Materials

Copyright 2026 Vinicius May - Apache License 2.0 Page 3 of -

# 1. Changelog from v1.4

This revision consolidates hardware changes made during design review and production planning. The main areas affected are MCU target, IMU selection, and the addition of an object-recognition camera subsystem.

## 1.1 MCU Target

Production target is now the bare module ESP32-S3-WROOM-1U-N16R8 (16MB flash, 8MB PSRAM, U.FL antenna). The XIAO ESP32S3 Plus remains the prototype board. GPIO assignments are identical on both platforms, so firmware does not change on migration.

## 1.2 IMU Replacement

The MPU6050 (obsoleted by TDK InvenSense) has been replaced by the ST LSM6DSOX. The new IMU adds a Machine Learning Core (MLC) and 16 Finite State Machines, enabling on-chip activity classification (walking, running, stationary, etc.) without CPU load on the ESP32. Power consumption drops from ~3.9 mA (MPU6050) to 0.55 mA (LSM6DSOX, combo high-perf).

## 1.3 Pinout Changes

Signal | Old GPIO | New GPIO | Reason
VL53L5CX #1 INT | 40 | 42 | GPIO40 reassigned to SCCB_SDA (camera)
Button extra | - | 43 | Console via USB CDC frees GPIO43/44
LED flash | - | 44 | Illumination for camera capture
CAM_PWDN | - | 45 | Software power control for camera
Camera DVP | - | 10,11,12,13,14,15,16,17,18,38,47,48 OV3660 parallel interface
Camera SCCB | - | 39 (SCL) / 40 (SDA) | Separate I2C bus (avoids 0x3C collision with SSD1306)

## 1.4 Camera Subsystem Added

OV3660 3MP FPC camera module added for on-demand object recognition (feeding bowl, dog house, landmarks). Camera powers on only when ToF detects stable nearby object. 24-pin 0.5mm FPC connector (Bossie BX-FPC05-1.5H24PX, LCSC C18078354).

## 1.5 Power Rail Cleanup

TVS diode on VLDO (downstream of TPS2116) removed - redundant with existing upstream TVS on VUSB. Redundant 1uF capacitor on 3v3_esp rail removed. Decoupling standardized to 4.7uF + 100nF per rail.

Copyright 2026 Vinicius May - Apache License 2.0 Page 4 of -

# 2. Project Overview

MAIA (Motion Assistance for Impaired Animals) is a wearable assistance device designed for blind dogs. The system uses Time-of-Flight (ToF) sensors to detect obstacles in three directions (left, center, right) and provides haptic feedback through vibration motors on the dog's collar. An on-demand camera subsystem identifies household landmarks (feeding station, bed, doorways) to deliver contextual haptic patterns.
The system consists of two main components: the Main Unit (electronics, battery, sensors, display, camera) and the Motor Sleeve (fabric wrap with embedded vibration motors fitting any collar).

## 2.1 Key Features

Feature | Description
3-Zone ToF Detection | Left, Center, Right up to 4m
Object Recognition | OV3660 camera, on-demand activation
Haptic Feedback | 1x DRV2605L (center) + 2x MOSFET ERM
Auto Sleep/Wake | Motion-triggered via LSM6DSOX MLC
Activity Classification | On-chip ML (walking/stationary/etc)
Temperature Monitor | Ambient monitoring with alerts
OLED Display | 128x32 blue pixels for status
WiFi Sync | Cloud upload every 10 min
24h+ Battery | Removable 26650 for nightly charging
Universal Mount | Sleeve fits any collar via velcro

Copyright 2026 Vinicius May - Apache License 2.0 Page 5 of -

# 3. System Architecture

## 3.1 Block Diagram

Block | Interface | Function
ESP32-S3-WROOM-1U-N16R8 | - | Main controller, WiFi, BLE
VL53L5CX #1 | I2C (0x54) | Left/Center ToF sensor
VL53L5CX #2 | I2C (0x52) | Right/Center ToF sensor
LSM6DSOX | I2C (0x6A) | Motion/activity, MLC-based sleep/wake
SSD1306 | I2C (0x3C) | OLED display 128x32
DS18B20 | 1-Wire | Temperature sensor
DRV2605L | I2C (0x5A) | Haptic driver center motor
OV3660 | DVP + SCCB (0x3C) | 3MP camera via FPC
Motor Left | PWM + MOSFET | ERM via 2N7000 - GPIO7
Motor Right | PWM + MOSFET | ERM via 2N7000 - GPIO8
LED Flash | PWM + MOSFET | Camera illumination - GPIO44
Button Main | GPIO9 | User interface input
Button Extra | GPIO43 | Secondary input
26650 Battery | BAT+/BAT- | 5000mAh removable

## 3.2 I2C Bus Addresses

MAIA uses two separate I2C buses to avoid the 0x3C address collision between SSD1306 and OV3660:
Bus | Device | Address | Notes
Main (GPIO5/6) | SSD1306 | 0x3C | OLED Display
Main | VL53L5CX #2 | 0x52 | ToF Right (default boot)
Main | VL53L5CX #1 | 0x54 | ToF Left (reassigned at init)
Main | DRV2605L | 0x5A | Haptic driver
Main | LSM6DSOX | 0x6A | IMU
SCCB (GPIO39/40) | OV3660 | 0x3C | Isolated, camera-only

Copyright 2026 Vinicius May - Apache License 2.0 Page 6 of -

# 4. Hardware Design

## 4.1 Haptic Motor Configuration

Motor | Position | Driver | Interface
Center | Front (chin) | DRV2605L | I2C 0x5A
Left | Left side (ear) | 2N7000 MOSFET | PWM GPIO7
Right | Right side (ear) | 2N7000 MOSFET | PWM GPIO8

## 4.2 Sensor Configuration

Sensor | Model | Function
ToF #1 | VL53L5CX | Left/Center obstacle, 8x8 zones
ToF #2 | VL53L5CX | Right/Center obstacle, 8x8 zones
IMU | LSM6DSOX | 6-axis + MLC activity recognition
Temperature | DS18B20 | Ambient temp, emergency alerts
Camera | OV3660 | 3MP DVP, on-demand object recognition
Display | SSD1306 | 128x32 OLED, blue pixels

Copyright 2026 Vinicius May - Apache License 2.0 Page 7 of -

# 5. Motor Driver Circuit

## 5.1 Component Description

Component | Value | Function
R1 (series) | 100R | Limits gate current. Protects GPIO. Max 33mA.
R2 (pull-down) | 10k | Ensures motor OFF during ESP32 boot (Hi-Z).
MOSFET | 2N7000 | N-Ch logic-level. Switches motor GND. Vth ~2V.
Flyback Diode | SL54F | Anti-parallel with motor. Protects spike.
Total for 2 MOSFET-driven motors: 2x 2N7000, 2x 100R, 2x 10k, 2x SL54F.
The same circuit topology is reused for the camera LED flash driver on GPIO44.

Copyright 2026 Vinicius May - Apache License 2.0 Page 8 of -

# 6. Pinout Configuration

Pinout valid for both XIAO ESP32S3 Plus (prototype) and ESP32-S3-WROOM-1U-N16R8 (production). Console via USB CDC (GPIO19/20) - UART0 pins (GPIO43/44) are available for general-purpose I/O.

## 6.1 Core Peripherals

GPIO | Function | XIAO Plus | Pull-up
1 | VL53L5CX #1 LPn | D0 | Ext 47k
2 | VL53L5CX #2 LPn | D1 | Ext 47k
3 | DS18B20 DATA | D2 | Ext 4.7k
4 | LSM6DSOX INT1 | D3 | Internal
5 | I2C SDA (main) | D4 | Ext 2.2k
6 | I2C SCL (main) | D5 | Ext 2.2k
7 | Motor Left PWM | D8 | -
8 | Motor Right PWM | D9 | -
9 | Button main | D10 | Internal
41 | VL53L5CX #2 INT | D14 | Internal
42 | VL53L5CX #1 INT | D15 | Internal
43 | Button extra | D6 | Internal
44 | LED flash PWM | D7 | -
45 | CAM_PWDN | - | Ext 10k PD

## 6.2 Camera Interface (DVP + SCCB)

GPIO | Camera Signal | Direction
10 | XCLK | Out (LEDC, 20MHz)
11 | Y8 | In
12 | Y7 | In
13 | PCLK | In
14 | Y6 | In
15 | Y2 | In
16 | Y5 | In
17 | Y3 | In
18 | Y4 | In
38 | VSYNC | In
39 | SCCB_SCL | Out (open-drain)
40 | SCCB_SDA | Bidir (open-drain)
47 | HREF | In
48 | Y9 | In

## 6.3 Reserved / Do Not Use

GPIO | Reason
0 | Boot strap (internal pull-up)
19, 20 | USB D-/D+ (native USB CDC)
35, 36, 37 | Octal PSRAM (N16R8 internal)
46 | Strapping pin (ROM msg enable)

Copyright 2026 Vinicius May - Apache License 2.0 Page 9 of -

# 7. Camera Subsystem

The OV3660 3MP camera is used for on-demand object recognition. It is powered down by default (PWDN=HIGH) to preserve battery. ToF triggers camera activation when a stable object is detected at medium range.

## 7.1 Connector

FPC 24-pin, 0.5mm pitch, bottom contact, right angle SMD, flip-lock actuator. Compatible with standard
ESP32-CAM OV3660/OV2640/OV5640 modules.
Parameter | Value
Manufacturer | Bossie
Part | BX-FPC05-1.5H24PX
LCSC | C18078354
Pitch | 0.5mm
Contacts | 24 + 2 shield pads
Current Rating | 500mA
FPC Thickness | 0.3mm

## 7.2 FPC Pinout

FPC Pin | Signal | ESP32 GPIO / Net
1 | VCC (3V3) | 3v3_esp
2 | GND | GND
3 | SCCB_SCL | GPIO39
4 | SCCB_SDA | GPIO40
5 | VSYNC | GPIO38
6 | HREF | GPIO47
7 | PCLK | GPIO13
8 | XCLK | GPIO10
9 | Y9 | GPIO48
10 | Y8 | GPIO11
11 | Y7 | GPIO12
12 | Y6 | GPIO14
13 | Y5 | GPIO16
14 | Y4 | GPIO18
15 | Y3 | GPIO17
16 | Y2 | GPIO15
17 | GND | GND
18 | RESET | Pull-up 10k to 3V3
19 | PWDN | GPIO45
20-24 | GND | GND
25, 26 | Shield (mechanical) | GND

Copyright 2026 Vinicius May - Apache License 2.0 Page 10 of -

## 7.3 External Components

Location | Component | Value | Purpose
Pin 1 (VCC) | C14 | 4.7uF MLCC | Bulk decoupling
Pin 1 (VCC) | C15 | 100nF MLCC | HF decoupling
Pin 3 (SCL) | R16 | 3.3k to 3V3 | SCCB pull-up
Pin 4 (SDA) | R17 | 3.3k to 3V3 | SCCB pull-up
Pin 18 (RESET) | R15 | 10k to 3V3 | Release
Pin 19 (PWDN) | R14 | 10k to GND | Default power-down

## 7.4 Power Budget

OV3660 active: ~150 mA @ 3.3V. Powered from 3v3_esp rail (AP7365-33 LDO, 600mA max). Peak rail demand with camera + ESP32 WiFi TX + ToF = ~500mA, within LDO limits. Camera duty cycle is low in normal operation (triggered only by ToF).

## 7.5 Rail Voltages

The OV3660 module integrates internal regulators for AVDD (2.8V analog), DOVDD (1.8V digital I/O), and DVDD (1.5V core). A single 3.3V rail on FPC pin 1 is all that is required externally.

Copyright 2026 Vinicius May - Apache License 2.0 Page 11 of -

# 8. IMU: LSM6DSOX

The LSM6DSOX replaces the obsolete MPU6050 from v1.4. It is a 6-axis IMU from STMicroelectronics with significant advantages for wearable always-on applications.

## 8.1 Specifications

Parameter | Value
Package | LGA-14L, 2.5 x 3.0 x 0.83 mm
Accelerometer range | +/- 2/4/8/16 g
Gyroscope range | +/- 125/250/500/1000/2000 dps
ODR range | 1.6 Hz to 6.7 kHz
Supply VDD | 1.71 V to 3.6 V
Current, combo HP | 0.55 mA typ
Current, sleep | ~3 uA
Interfaces | I2C, SPI, MIPI I3C
FIFO | 9 KB
I2C Address | 0x6A (SA0=0) / 0x6B (SA0=1)
Operating temp | -40 to +85 C

## 8.2 On-Chip Smart Features

The LSM6DSOX enables significant ESP32 CPU offload:
Feature | Benefit for MAIA
Machine Learning Core (MLC) | Classify dog activity (walk/run/idle/sleep) on-chip
16 Finite State Machines | Detect custom motion patterns (shaking, scratching)
Pedometer (HW) | Step counter without CPU
Wake-on-motion | ESP32 deep sleep until dog moves
Free-fall detection | Emergency event (collar dropped)
6D orientation | Head position tracking
Tap / double-tap | Owner interaction (tap device for status)

## 8.3 Development Flow for MLC

1. Collect labeled IMU data (walk, run, idle, sleep, etc.) using the LSM6DSOX eval board. 2. Train decision tree in ST Edge AI Suite (free tool). 3. Export configuration as .ucf register dump. 4. Firmware loads .ucf at boot. 5. Chip outputs activity class via register read. ESP32 CPU load for classification: effectively zero.

Copyright 2026 Vinicius May - Apache License 2.0 Page 12 of -

# 9. Power Management

## 9.1 Architecture

Power input from either USB-C (VBUS) or 26650 Li-Ion battery (VBAT). The TPS2116 power mux selects the active source automatically, with priority on VBUS when available.
Block | Part | Function
Power Mux | TPS2116DRL | VBUS/VBAT auto-select
Charger | BQ24040DSQR | Li-Ion charge, 26650 compatible
LDO #1 | AP7365-33WG-7 | 3v3_esp rail (600mA)
LDO #2 | AP7365-33WG-7 | 3v3_haptic rail (isolated)
TVS | SMAJ5.0CA (or SMF5.0CA) | VUSB surge protection
USB ESD | USBLC6-2SC6 | D+/D- ESD clamp
Battery Gauge | XB5352A | VBAT voltage monitor

## 9.2 Current Budget

Component | Active (mA) | Sleep (uA)
ESP32-S3 idle | 20 | -
ESP32-S3 WiFi TX peak | 240 | -
ESP32-S3 deep sleep | - | 14
VL53L5CX x 2 (ranging) | 80 | 6
LSM6DSOX (combo HP) | 0.55 | 3
SSD1306 active | 20 | 10
DS18B20 | 1 | 1
DRV2605L idle | 2 | 2
OV3660 active | 150 | 0
OV3660 power-down | 0 | 200
Peak with camera + WiFi | ~500 | -
Typical active (no cam, no TX) | ~50 | -
Deep sleep total | - | ~30
At ~50 mA typical active, the 5000mAh battery yields over 100 hours of continuous use. Aggressive power management with LSM6DSOX wake-on-motion pushes real runtime beyond the 24h target.

Copyright 2026 Vinicius May - Apache License 2.0 Page 13 of -

# 10. USB Subsystem

The ESP32-S3 native USB (GPIO19/20) is used for both console (CDC) and flashing. No external USB-to-UART bridge is required.
Element | Part / Value | Purpose
Connector | USB-C 16-pin 2MD | Host / charge
CC pull-downs | 5.1k x 2 | USB-C Rd (sink)
VBUS bulk cap | 4.7uF + 1uF + 100nF | Input decoupling
Ferrite bead | 600R @ 100MHz | VBUS noise filter
TVS (VBUS) | SMAJ5.0CA (or SMF5.0CA) | Surge / ESD clamp
ESD array (D+/D-) | USBLC6-2SC6 | Line ESD protection
Series termination | 22R x 2 (D+ and D-) | Source impedance match
Diff impedance | 90 ohm diff (PCB) | USB 2.0 Full-Speed
The 22 ohm series resistors are placed near the ESP32 (source termination). The USBLC6-2SC6 is placed near the USB-C connector (ESD source). Signal path: USB-C to USBLC6 to 22 ohm to ESP32.

Copyright 2026 Vinicius May - Apache License 2.0 Page 14 of -

# 11. Mechanical Design

## 11.1 Main Unit Dimensions

Dimension | Value | Notes
Length | 70mm | Along collar
Width | 30mm | Perpendicular
Height | 30mm | Vertical
Weight | ~120g | With battery
Material | ABS/PETG | IP54 rated

## 11.2 Battery Removal

1. Press the red latch button. 2. Slide battery compartment outward. 3. Remove 26650 cell for charging.

Copyright 2026 Vinicius May - Apache License 2.0 Page 15 of -

# 12. Motor Sleeve System

## 12.1 JST Cable Pinout

Pin | Signal | Color (suggested)
1 | Motor Left (+) | Yellow
2 | Motor Center (+) | Orange
3 | Motor Right (+) | Red
4 | GND (common) | Black
5 | GND (common) | Black

Copyright 2026 Vinicius May - Apache License 2.0 Page 16 of -

# 13. Haptic Feedback System

## 13.1 Vibration Patterns

Effect | Pattern | Use Case
Soft Bump | 50%, 100ms | Object 2-4m
Medium Buzz | 70%, 150ms | Object 1-2m
Strong Alert | 100%, 200ms | Object 0.5-1m
Rapid Pulse | 100%, 50ms x3 | Object <0.5m
Continuous | 80%, sustained | Imminent collision
Landmark: food bowl | Pattern A (camera) | Recognized bowl
Landmark: dog house | Pattern B (camera) | Recognized house

## 13.2 Ignore Mode

Prevents desensitization during feeding/drinking. Triggers: distance stable <20cm for >3s, velocity ~0 (LSM6DSOX idle classification). Exit: distance >50cm, movement detected, or 5 min timeout.

Copyright 2026 Vinicius May - Apache License 2.0 Page 17 of -

# 14. Display Interface

## 14.1 Main Button Multi-Function

Press | Screen Content
1st | Battery icon + percentage + voltage
2nd | Temperature: current + high/low
3rd | Pet Name
4th | Owner Name + phone (scroll)
5th | Address (scroll)
6th | WiFi: last sync + SSID
7th | Activity: last MLC class + duration
8th | System uptime + version
9th+ | Display OFF

## 14.2 Extra Button

GPIO43. Reserved for future use (panic trigger, manual WiFi sync, voice announcement).

Copyright 2026 Vinicius May - Apache License 2.0 Page 18 of -

# 15. Firmware Architecture

## 15.1 Software Layers

Layer | Modules
Application | main, tasks, state machine
Services | obstacle_detection, haptic_feedback, object_recognition, activity_tracker, power_manager, data_logger, status_monitor
Drivers | vl53l5cx, lsm6dsox, drv2605l, ssd1306, button, ds18b20, ov3660_camera
maia_board (BSP) | pinout, i2c_init, gpio_init, pwm_init, onewire_init, cam_init
ESP-IDF / FreeRTOS | Hardware abstraction layer

## 15.2 FreeRTOS Tasks

Task | Priority | Stack | Function
task_sensing | 10 | 8KB | ToF + LSM6DSOX reading
task_haptic | 15 | 2KB | Motor control
task_camera | 8 | 16KB | Object recognition (on-demand)
task_display | 3 | 4KB | OLED + button
task_monitor | 1 | 4KB | Temp + WiFi sync + activity log

Copyright 2026 Vinicius May - Apache License 2.0 Page 19 of -

# 16. VL53L5CX Driver API (MAIA)

The VL53L5CX MAIA driver exposes a clean, Kconfig-driven API for dual ToF sensor management. All public functions use the maia_tof_* prefix. Defined in components/drivers/vl53l5cx/include/vl53l5cx.h - Copyright 2026 Vinicius May, Apache 2.0.

## 16.1 Constants

Constant | Value | Description
MAIA_TOF_SENSOR_LEFT | 0 | Left sensor ID
MAIA_TOF_SENSOR_RIGHT | 1 | Right sensor ID
MAIA_TOF_SENSOR_MAX | 2 | Total sensors
MAIA_TOF_POWER_ACTIVE | 0 | Full operation
MAIA_TOF_POWER_LOW_POWER | 1 | Sleep (retains FW)
MAIA_TOF_MAX_ZONES | 64 | 8x8 resolution

## 16.2 Data Type: maia_tof_data_t

Ranging result for one sensor. Up to 64 zones (8x8). Zones filtered by Kconfig (status 5 or 6) return distance_mm = -1.

## 16.3 Public Functions

Function | Description
maia_tof_init() | Initialize both sensors. LPn-based address reassignment (#1: 0x52 to 0x54; #2 stays 0x52). Uploads firmware and applies Kconfig settings.
maia_tof_deinit() | Stop ranging, remove I2C device handles, disable sensors via LPn.
maia_tof_start_ranging() | Start ranging on all initialized sensors. Mode set by Kconfig at init.
maia_tof_stop_ranging() | Stop ranging on all initialized sensors.
maia_tof_data_ready(id, *ready) | Poll specified sensor for new data.
maia_tof_get_data(id, *data) | Read latest ranging frame. Applies status filters per Kconfig.
maia_tof_set_power_mode(id, mode) | Set power mode. LOW_POWER retains firmware in RAM (no re-upload on wake).

Copyright 2026 Vinicius May - Apache License 2.0 Page 20 of -

# 17. Bill of Materials

## 17.1 Main Unit Electronics

Item | Part Number | Qty | Notes
MCU Module | ESP32-S3-WROOM-1U-N16R8 | 1 | Espressif, 16MB flash / 8MB PSRAM
Prototype Board | XIAO ESP32S3 Plus | 1 | Seeed Studio (dev only)
ToF Sensor | VL53L5CX | 2 | ST, LCSC C3178303
IMU | LSM6DSOX | 1 | ST, 6-axis + MLC
Haptic Driver | DRV2605L | 1 | TI, center motor
OLED Display | SSD1306 128x32 | 1 | Blue, I2C 0x3C
Temp Sensor | DS18B20+ | 1 | TO-92
Camera Module | OV3660 FPC 24-pin | 1 | 3MP, on-demand
FPC Connector | Bossie BX-FPC05-1.5H24PX | 1 | LCSC C18078354
MOSFET | 2N7000 | 3 | Motor L, Motor R, LED flash
Flyback Diode | SL54F | 2 | Motor protection
Battery | 26650 Li-Ion | 1 | 5000mAh
Button | Tactile 6x6mm | 2 | Main + Extra
JST Connector | JST-PH 5-pin | 1 | Motor cable

## 17.2 Power Section

Item | Part Number | Qty
Power Mux | TPS2116DRL | 1
Charger | BQ24040DSQR | 1
LDO 3.3V | AP7365-33WG-7 | 2
Battery Monitor | XB5352A | 1
TVS VBUS | SMAJ5.0CA (or SMF5.0CA) | 1
USB ESD | USBLC6-2SC6 | 1
Ferrite Bead | 600R @ 100MHz, 0603 | 1
USB Connector | USB-C 16-pin 2MD | 1

## 17.3 Resistors

Value | Qty | Purpose
22R 1% | 2 | USB D+/D- series term
100R | 3 | MOSFET gate series
2.2k | 2 | I2C pull-up main
3.3k | 2 | SCCB pull-up camera
4.7k | 1 | 1-Wire pull-up DS18B20
5.1k | 2 | USB-C CC pull-down
10k | 5 | MOSFET PD, RESET, PWDN
47k | 2 | VL53L5CX LPn pull-up

## 17.4 Capacitors

Value | Qty | Purpose
100nF MLCC | ~10 | HF decoupling all rails
1uF MLCC | 2 | VBUS / battery monitor

Copyright 2026 Vinicius May - Apache License 2.0 Page 21 of -

Value | Qty | Purpose
4.7uF MLCC | ~5 | Bulk decoupling (cam, ESP32, LDO)
10uF MLCC | 2 | Power mux / charger

## 17.5 Motor Sleeve

Item | Description | Qty
Vibration Motor | ERM 10mm, 3V | 3
Fabric Sleeve | Neoprene 250x40mm | 1
Velcro | Hook + Loop strips | 2
Flat Cable | 5-wire, 150mm | 1
JST Plug | JST-PH 5-pin female | 1

Estimated Cost: ~$75-90 USD per unit (excluding enclosure and PCB fabrication). Camera adds ~$8-10 versus v1.4.

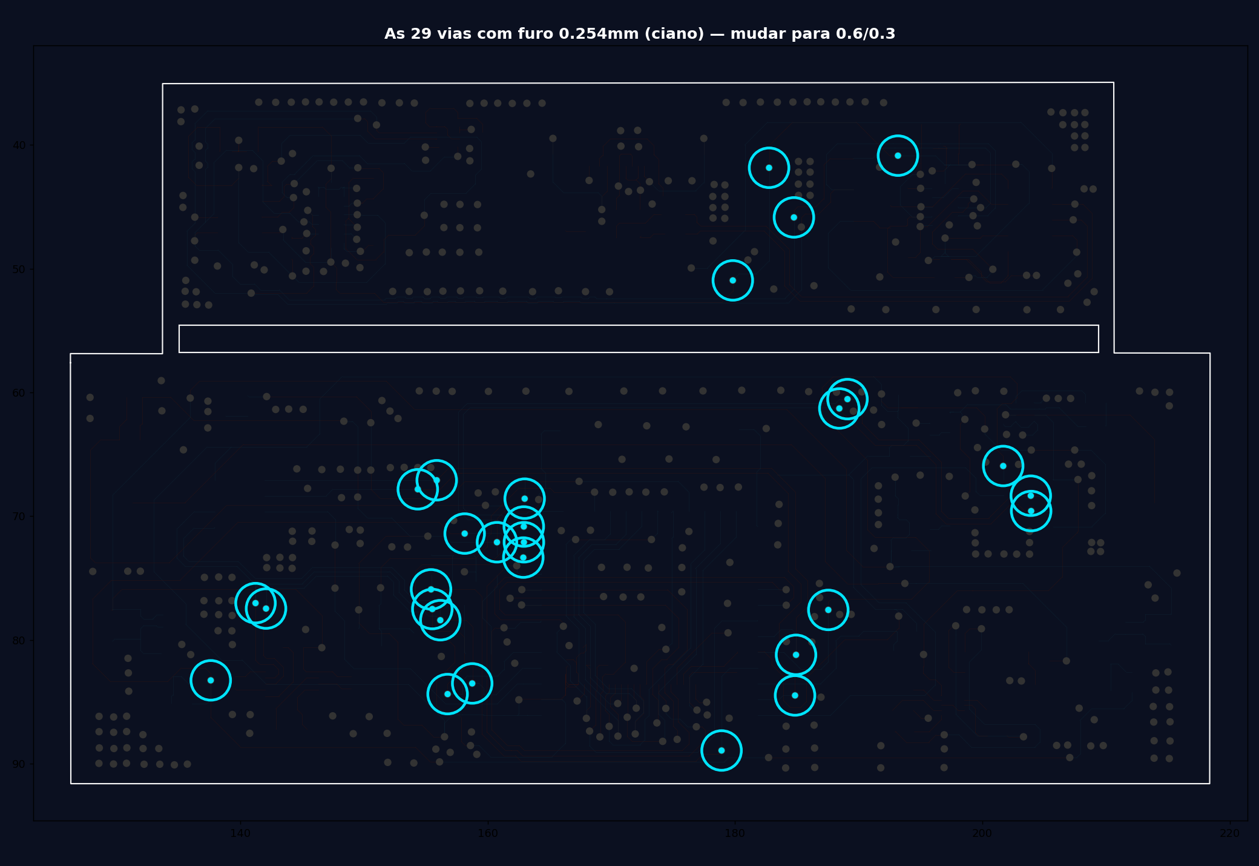
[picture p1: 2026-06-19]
pcb/maia/vias_0254_map.png

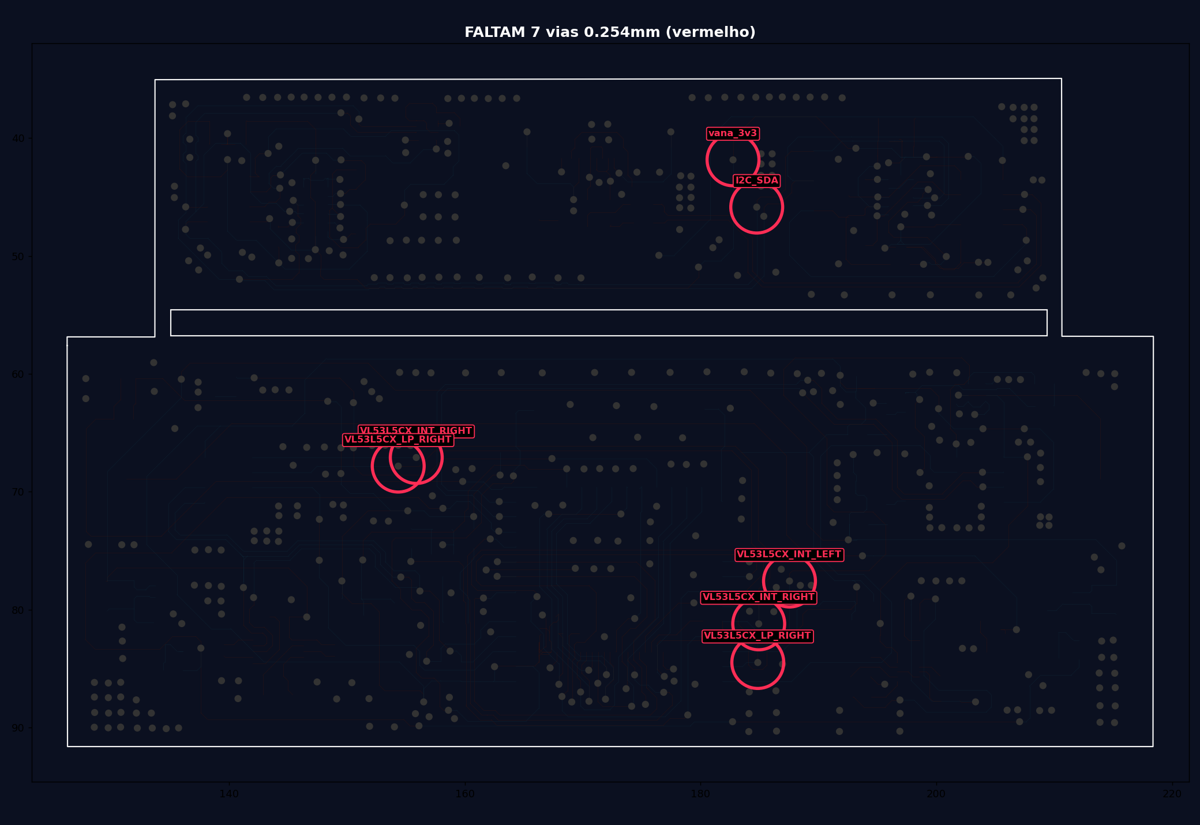
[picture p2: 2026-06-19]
pcb/maia/vias_restantes.png

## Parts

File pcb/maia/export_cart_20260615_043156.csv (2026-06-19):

Index | LCSC# | MPN | Manufacturer | Package | Customer # | Description | RoHS | Quantity | MOQ | Multiple | Unit Price($) | Extended Price($) | Product Link
1 | C2988620 | BH-18650-B1BA002 | MYOUNG | - |  | Battery Holder Cylindrical 18650 Cell SMD | yes | 3 | 1 | 1 | 1.3066 | 3.92 | https://www.lcsc.com/product-detail/C2988620.html
2 | C3975131 | PM127-2-05-S-4.3 | HCTL | SMD,P=1.27mm |  | Female Header 10 Position 1.27mm Pitch Dual Row Surface Mount -40℃~+105℃ | yes | 7 | 7 | 7 | 0.1853 | 1.30 | https://www.lcsc.com/product-detail/C3975131.html
3 | C3975188 | PZ127-2-05-S | HCTL | SMD,P=1.27mm |  | Pin Header 10 Position 1.27mm Pitch Dual Row Surface Mount -40℃~+105℃ | yes | 10 | 5 | 5 | 0.1457 | 1.46 | https://www.lcsc.com/product-detail/C3975188.html
4 | C2765186 | TYPE-C 16PIN 2MD(073) | SHOU HAN | SMD |  | USB-C (USB TYPE-C) Receptacle Connector 16 Position Surface Mount, Right Angle | yes | 20 | 20 | 20 | 0.0705 | 1.41 | https://www.lcsc.com/product-detail/C2765186.html
5 | C3235557 | TPS2116DRLR | TI | SOT-583 |  | 2 Channel 2.5A SOT-583 | yes | 5 | 1 | 1 | 0.4576 | 2.29 | https://www.lcsc.com/product-detail/C3235557.html
6 | C2827654 | USBLC6-2SC6 | TECH PUBLIC | SOT-23-6 |  | 12VC Clamp 6A Ipp ESD DIODE SOT-23-6 | yes | 10 | 10 | 10 | 0.0410 | 0.41 | https://www.lcsc.com/product-detail/C2827654.html
7 | C81080 | BQ24040DSQR | TI | WSON-10-EP(2x2) |  | 3.5V~28V Lithium Battery 1 1A WSON-10-EP(2x2) Battery Chargers ICs RoHS | yes | 5 | 5 | 5 | 0.3822 | 1.91 | https://www.lcsc.com/product-detail/C81080.html
8 | C150742 | AP7365-33WG-7 | DIODES | SOT-25 |  | 3.3V Positive Fixed SOT-25 Voltage Regulators - Linear, Low Drop Out (LDO) Regulators RoHS | yes | 10 | 5 | 5 | 0.1894 | 1.89 | https://www.lcsc.com/product-detail/C150742.html
9 | C154943 | XB5352A | XySemi | SOT-23-5 |  | Battery Protection IC Lithium-ion/Polymer SOT-23-5 | yes | 10 | 10 | 10 | 0.0735 | 0.74 | https://www.lcsc.com/product-detail/C154943.html
10 | C5451632 | DS18B20 | HXY MOSFET | TO-92 |  | -55℃~+125℃ Single bus ±0.4℃ TO-92 Analog and Digital Output RoHS | yes | 3 | 1 | 1 | 0.5035 | 1.51 | https://www.lcsc.com/product-detail/C5451632.html
11 | C527464 | DRV2605LDGSR | TI | VSSOP-10-0.5mm |  | I2C VSSOP-10-0.5mm Motor Drivers, Controllers RoHS | yes | 3 | 1 | 1 | 1.2381 | 3.71 | https://www.lcsc.com/product-detail/C527464.html
12 | C481766 | LSM6DSOXTR | ST | LGA-14(2.5x3) |  | LGA-14(2.5x3) IMUs (Inertial Measurement Units) RoHS | yes | 3 | 1 | 1 | 3.4384 | 10.32 | https://www.lcsc.com/product-detail/C481766.html
13 | C3013946 | ESP32-S3-WROOM-1U-N16R8 | ESPRESSIF | SMD,19.2x18mm |  | 2.4GHz ESP32-S3R8 -103.5dBm SMD,19.2x18mm RF Transceiver Modules and Modems RoHS | yes | 3 | 1 | 1 | 5.5711 | 16.71 | https://www.lcsc.com/product-detail/C3013946.html
14 | C3178303 | VL53L5CXV0GC/1 | ST | SMD,6.4x3mm |  | 4m I2C SMD,6.4x3mm Distance Measuring RoHS | yes | 4 | 1 | 1 | 7.4367 | 29.75 | https://www.lcsc.com/product-detail/C3178303.html
15 | C18078354 | BX-FPC05-1.5H24PX | Bossie | SMD,P=0.5mm,Surface Mount,Right Angle |  | FFC/FPC Connector 24 Position 0.5mm Pitch Bottom Contact Surface Mount, Right Angle -25℃~+85℃ | yes | 10 | 5 | 5 | 0.0933 | 0.93 | https://www.lcsc.com/product-detail/C18078354.html
16 | C5248081 | HS91L02W2C01 | HS | - |  | 0.91 128x32 SSD1306 chip I2C LCD, OLED, Graphic RoHS | yes | 3 | 1 | 1 | 2.2404 | 6.72 | https://www.lcsc.com/product-detail/C5248081.html
17 | C49234124 | HX 3x4x2-2P-1.6N TACTILE SWITCH | hanxia | SMD,4x3mm |  | Tactile Switch SPST 160gf 2mm SMD (SMT) Tab 4mm x 3mm Surface Mount | yes | 100 | 50 | 50 | 0.0179 | 1.79 | https://www.lcsc.com/product-detail/C49234124.html
18 | C2874211 | TS-KG01T-ACT50F | Hanbo Electronic | SMD,6x3.5mm |  | Tactile Switch SPST 250gf 5mm Gull Wing 6mm x 3.5mm Surface Mount | yes | 60 | 20 | 20 | 0.0278 | 1.67 | https://www.lcsc.com/product-detail/C2874211.html
19 | C20917 | AO3400A | AOS | SOT-23 |  | N-Channel 30V Surface Mount SOT-23-3L | yes | 10 | 5 | 5 | 0.0846 | 0.85 | https://www.lcsc.com/product-detail/C20917.html
20 | C116601 | SMAJ5.0CA | MDD(Microdiode Semiconductor) | DO-214AC(SMA) |  | 9.2VC Clamp 43.5A@10/1000us Ipp TVS DIODE DO-214AC(SMA) | yes | 20 | 20 | 20 | 0.0410 | 0.82 | https://www.lcsc.com/product-detail/C116601.html
21 | C916992 | B5819WS | JSMSEMI | SOD-323 |  | Diode Independent 40V 1A Surface Mount SOD-323 | yes | 50 | 50 | 50 | 0.0127 | 0.64 | https://www.lcsc.com/product-detail/C916992.html
22 | C389522 | MHT192WDT-ICE | MEIHUA | 0603 |  | Ice Blue LED Indication - Discrete 3.1V 0603 | yes | 20 | 20 | 20 | 0.0451 | 0.90 | https://www.lcsc.com/product-detail/C389522.html
23 | C51933299 | GL0603UP01 | Guiguang light | 0603 |  | 5mA 3.2V 120° Pink 1.6mm x 0.8mm square LED 0603 LED Indication - Discrete RoHS | yes | 50 | 50 | 50 | 0.0087 | 0.44 | https://www.lcsc.com/product-detail/C51933299.html
24 | C19273150 | YLED0603W | YONGYUTAI | 0603 |  | White LED Indication - Discrete 2.6V~3V 0603 | yes | 50 | 50 | 50 | 0.0107 | 0.54 | https://www.lcsc.com/product-detail/C19273150.html
25 | C2986048 | 19-21/GHC-YR1S2/4T | EVERLIGHT | 0603 |  | 25mA 3.3V 518nm 100° Green 95mW 0603 LED Indication - Discrete RoHS | yes | 20 | 2 | 2 | 0.0215 | 0.43 | https://www.lcsc.com/product-detail/C2986048.html
26 | C2843893 | XL-3030WWC-1W-3V | XINGLIGHT | SMD3030-2P |  | White LED Indication - Discrete 3.2V SMD3030 | yes | 10 | 10 | 10 | 0.0441 | 0.44 | https://www.lcsc.com/product-detail/C2843893.html
27 | C131394 | CC0402KRX7R9BB104 | YAGEO | 0402 |  | 100nF ±10% 50V Ceramic Capacitor X7R 0402 | yes | 100 | 100 | 100 | 0.0054 | 0.54 | https://www.lcsc.com/product-detail/C131394.html
28 | C6119795 | CGA0402X5R475M250GT | HRE | 0402 |  | 4.7uF ±20% 25V Ceramic Capacitor X5R 0402 | yes | 100 | 20 | 20 | 0.0195 | 1.95 | https://www.lcsc.com/product-detail/C6119795.html
29 | C1518208 | GRM155R61H105KE05D | muRata | 0402 |  | 1uF ±10% 50V Ceramic Capacitor X5R 0402 | yes | 40 | 20 | 20 | 0.0447 | 1.79 | https://www.lcsc.com/product-detail/C1518208.html
30 | C408132 | GRM155R61A106ME11D | muRata | 0402 |  | 10uF ±20% 10V Ceramic Capacitor X5R 0402 | yes | 50 | 50 | 50 | 0.0290 | 1.45 | https://www.lcsc.com/product-detail/C408132.html
31 | C357023 | HCB3216KF-601T30 | TAI-TECH | 1206 |  | 600Ω@100MHz 1 Line Ferrite Bead 1206 3A 40mΩ | yes | 40 | 20 | 20 | 0.0494 | 1.98 | https://www.lcsc.com/product-detail/C357023.html
32 | C99782 | RC0603FR-074K7L | YAGEO | 0603 |  | 100mW 4.7kΩ 75V Thick Film Resistor ±100ppm/℃ ±1% 0603 Chip Resistor - Surface Mount RoHS | yes | 100 | 100 | 100 | 0.0018 | 0.18 | https://www.lcsc.com/product-detail/C99782.html
33 | C2653986 | ESR03EZPF1001 | ROHM | 0603 |  | 250mW 1kΩ 150V Thick Film Resistor ±100ppm/℃ ±1% 0603 Chip Resistor - Surface Mount RoHS | yes | 100 | 50 | 50 | 0.0142 | 1.42 | https://www.lcsc.com/product-detail/C2653986.html
34 | C427297 | ERJP03F1000V | PANASONIC | 0603 |  | 100Ω ±1% 200mW 0603 Thick Film Resistor AEC-Q200 | yes | 60 | 20 | 20 | 0.0288 | 1.73 | https://www.lcsc.com/product-detail/C427297.html
35 | C873681 | SR0603FR-7T22RL | YAGEO | 0603 |  | 22Ω 250mW 150V Thick Film Resistor ±1% ±200ppm/℃ 0603 Chip Resistor - Surface Mount RoHS | yes | 100 | 50 | 50 | 0.0132 | 1.32 | https://www.lcsc.com/product-detail/C873681.html
36 | C2774420 | HP03W5J0512T5E | UNI-ROYAL | 0603 |  | 5.1kΩ ±5% 200mW 0603 Thick Film Resistor AEC-Q200 | yes | 100 | 100 | 100 | 0.0016 | 0.16 | https://www.lcsc.com/product-detail/C2774420.html
37 | C2074257 | ESR03EZPF4700 | ROHM | 0603 |  | 250mW 470Ω 150V Thick Film Resistor ±100ppm/℃ ±1% 0603 Chip Resistor - Surface Mount RoHS | yes | 100 | 50 | 50 | 0.0165 | 1.65 | https://www.lcsc.com/product-detail/C2074257.html
38 | C543357 | ERJPA3F1501V | PANASONIC | 0603 |  | 1.5kΩ ±1% 250mW 0603 Thick Film Resistor AEC-Q200 | yes | 100 | 20 | 20 | 0.0270 | 2.70 | https://www.lcsc.com/product-detail/C543357.html
39 | C4351468 | ERJ-UP3F3301V | PANASONIC | 0603 |  | 3.3kΩ 250mW Thick Film Resistor ±100ppm/℃ ±1% 0603 Chip Resistor - Surface Mount RoHS | yes | 60 | 20 | 20 | 0.0389 | 2.33 | https://www.lcsc.com/product-detail/C4351468.html
40 | C873683 | SR0603FR-7T2K2L | YAGEO | 0603 |  | 250mW 2.2kΩ Thick Film Resistor ±1% ±200ppm/℃ 0603 Chip Resistor - Surface Mount RoHS | yes | 100 | 50 | 50 | 0.0060 | 0.60 | https://www.lcsc.com/product-detail/C873683.html
41 | C856528 | AT0603DRE072KL | YAGEO | 0603 |  | 2kΩ ±0.5% 100mW 0603 Thin Film Resistor | yes | 40 | 20 | 20 | 0.0251 | 1.00 | https://www.lcsc.com/product-detail/C856528.html
42 | C307918 | ESR03EZPF4702 | ROHM | 0603 |  | 47kΩ 250mW 150V Thick Film Resistor ±100ppm/℃ ±1% 0603 Chip Resistor - Surface Mount RoHS | yes | 100 | 50 | 50 | 0.0137 | 1.37 | https://www.lcsc.com/product-detail/C307918.html
43 | C95204 | RT0603BRD0710KL | YAGEO | 0603 |  | 100mW 10kΩ 75V Thin Film Resistor ±25ppm/℃ ±0.1% 0603 Chip Resistor - Surface Mount RoHS | yes | 60 | 20 | 20 | 0.0232 | 1.39 | https://www.lcsc.com/product-detail/C95204.html

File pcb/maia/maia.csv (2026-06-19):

Reference | Qty | Value | DNP | Exclude from BOM | Exclude from Board | Footprint | Datasheet | #
BT2 | 1 | BH-18650-B1BA002 |  |  |  | LCSC/Battery:BATTERY-SMD_18650-1S-L77.1-W20.7-1 | https://www.lcsc.com/datasheet/C2988620.pdf | 1
C1,C4,C5,C6,C7,C8,C9,C10 | 8 | 1uF |  |  |  | PCM_SparkFun-Capacitor:C_0402_1005Metric | https://product.tdk.com/system/files/dam/doc/product/capacitor/ceramic/mlcc/catalog/mlcc_commercial_general_en.pdf | 2
C2,C12,C15,C22,C23,C25,C26,C27,C28,C29,C34,C35,C36 | 13 | 100nF |  |  |  | PCM_SparkFun-Capacitor:C_0402_1005Metric | https://product.tdk.com/system/files/dam/doc/product/capacitor/ceramic/mlcc/catalog/mlcc_commercial_general_en.pdf | 3
C3,C13,C14,C20,C21,C24,C31,C32,C33 | 9 | 4.7uF |  |  |  | PCM_SparkFun-Capacitor:C_0402_1005Metric | https://product.tdk.com/system/files/dam/doc/product/capacitor/ceramic/mlcc/catalog/mlcc_commercial_general_en.pdf | 4
C11,C16,C17,C18,C19,C30 | 6 | 10uF |  |  |  | PCM_SparkFun-Capacitor:C_0402_1005Metric | https://product.tdk.com/system/files/dam/doc/product/capacitor/ceramic/mlcc/catalog/mlcc_commercial_general_en.pdf | 5
CN1,CN3 | 2 | PM127-2-05-S-4.3 |  |  |  | LCSC/connector:HDR-SMD_10P-P1.27-V-F-R2-C5-LS4.8 | https://www.lcsc.com/datasheet/C3975131.pdf | 6
CN2,CN4 | 2 | PZ127-2-05-S |  |  |  | LCSC/connector:HDR-SMD_10P-P1.27-V-M-R2-C5-LS5.3 | https://www.lcsc.com/datasheet/C3975188.pdf | 7
D1 | 1 | SMAJ5.0CA |  |  |  | Diode_SMD:D_SMA | https://www.littelfuse.com/media?itemid=75e32973-b177-4ee3-a0ff-cedaf1abdb93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 | 8
D2,D3,D4,D5,D6,D9 | 6 | Red |  |  |  | PCM_SparkFun-LED:LED_0603_1608Metric_Red | https://www.kingbrightusa.com/images/catalog/SPEC/APT1608SURCK.pdf | 9
D7,D8 | 2 | B5819WS_C6067464 |  |  |  | LCSC/diode_schottky:SOD-323F_L1.7-W1.3-LS2.5-R-RD-1 | https://www.lcsc.com/datasheet/C6067464.pdf | 10
L1,L2,L3 | 3 | HCB3216KF-601T30 |  |  |  | LCSC/inductor:L1206 | https://lcsc.com/product-detail/Others_TAITEC-HCB3216KF-601T30_C357023.html | 11
LED1 | 1 | XL-3030WWC-1W-3V |  |  |  | LCSC/led:LED-SMD_L3.0-W3.0_WHITE | https://www.lcsc.com/datasheet/C2843893.pdf | 12
M1,M2,M3 | 3 | LCM0827A3038F |  |  |  | LCSC/hapitc:VIBRATIONMOTOR-TH_LCM0827A3038F | https://www.lcsc.com/datasheet/C2759981.pdf | 13
OLED1 | 1 | HS91L02W2C01 |  |  |  | LCSC/lcd:OLED-TH_L38.0-W12.0_HS91L02W2C01 | https://www.lcsc.com/datasheet/C5248081.pdf | 14
Q1,Q2,Q3 | 3 | AO3400A |  |  |  | Package_TO_SOT_SMD:SOT-23 | http://www.aosmd.com/pdfs/datasheet/AO3400A.pdf | 15
R1,R2 | 2 | 5.1k |  |  |  | PCM_SparkFun-Resistor:R_0603_1608Metric | https://www.vishay.com/docs/20035/dcrcwe3.pdf | 16
R3,R4,R5,R6,R7,R9,R43 | 7 | 1k |  |  |  | PCM_SparkFun-Resistor:R_0603_1608Metric | https://www.vishay.com/docs/20035/dcrcwe3.pdf | 17
R8,R41 | 2 | 470r |  |  |  | PCM_SparkFun-Resistor:R_0603_1608Metric | https://www.vishay.com/docs/20035/dcrcwe3.pdf | 18
R10,R14,R15,R21,R23,R25 | 6 | 10k |  |  |  | PCM_SparkFun-Resistor:R_0603_1608Metric | https://www.vishay.com/docs/20035/dcrcwe3.pdf | 19
R11,R13 | 2 | 1k5 |  |  |  | PCM_SparkFun-Resistor:R_0603_1608Metric | https://www.vishay.com/docs/20035/dcrcwe3.pdf | 20
R12 | 1 | 2k |  |  |  | PCM_SparkFun-Resistor:R_0603_1608Metric | https://www.vishay.com/docs/20035/dcrcwe3.pdf | 21
R16,R17 | 2 | 3k3 |  |  |  | PCM_SparkFun-Resistor:R_0603_1608Metric | https://www.vishay.com/docs/20035/dcrcwe3.pdf | 22
R18,R19,R42 | 3 | 22r |  |  |  | PCM_SparkFun-Resistor:R_0603_1608Metric | https://www.vishay.com/docs/20035/dcrcwe3.pdf | 23
R20,R22,R24 | 3 | 100r |  |  |  | PCM_SparkFun-Resistor:R_0603_1608Metric | https://www.vishay.com/docs/20035/dcrcwe3.pdf | 24
R26,R27 | 2 | 2k2 |  |  |  | PCM_SparkFun-Resistor:R_0603_1608Metric | https://www.vishay.com/docs/20035/dcrcwe3.pdf | 25
R28,R29,R31,R32,R33,R34,R35,R36 | 8 | 47k |  |  |  | PCM_SparkFun-Resistor:R_0603_1608Metric | https://www.vishay.com/docs/20035/dcrcwe3.pdf | 26
R30,R37,R38,R39,R40 | 5 | 4k7 |  |  |  | PCM_SparkFun-Resistor:R_0603_1608Metric | https://www.vishay.com/docs/20035/dcrcwe3.pdf | 27
SW1,SW2 | 2 | HX 3X4X2-2P-1.6N TACTILE SWITCH |  |  |  | LCSC/button:KEY-SMD_L4.0-W3.0-LS4.9-1 | https://www.lcsc.com/datasheet/C49234124.pdf | 28
SW4,SW5 | 2 | TS-KG01T-ACT50F |  |  |  | LCSC/button:SW-SMD_L6.0-W3.5-LS8.0-EH | https://www.lcsc.com/datasheet/C2874211.pdf | 29
U1 | 1 | TPS2116DRL |  |  |  | Package_TO_SOT_SMD:SOT-583-8 | https://www.ti.com/lit/ds/symlink/tps2116.pdf | 30
U2 | 1 | USBLC6-2SC6 |  |  |  | Package_TO_SOT_SMD:SOT-23-6 | https://www.st.com/resource/en/datasheet/usblc6-2.pdf | 31
U3 | 1 | BQ24040DSQR |  |  |  | LCSC/BMS:WSON-10_L2.0-W2.0-P0.40-BL-EP | https://lcsc.com/product-detail/PMIC-Battery-Management_TI_BQ24040DSQR_BQ24040DSQR_C81080.html | 32
U4,U5 | 2 | AP7365-33WG-7 |  |  |  | LCSC/LDO:SOT-25_L3.0-W1.6-P0.95-LS2.8-BR | https://lcsc.com/product-detail/Low-Dropout-Regulators-LDO_DIODES_AP7365-33WG-7_AP7365-33WG-7_C150742.html | 33
U6 | 1 | XB5352A |  |  |  | LCSC/bms:SOT-23-5_L3.0-W1.7-P0.95-LS2.8-BR | https://lcsc.com/product-detail/Battery-Protection-ICs_XB5352A_C154943.html | 34
U10 | 1 | DS18B20 |  |  |  | Package_TO_SOT_THT:TO-92_Inline | http://datasheets.maximintegrated.com/en/ds/DS18B20.pdf | 35
U11 | 1 | DRV2605LDGS |  |  |  | Package_SO:TSSOP-10_3x3mm_P0.5mm | http://www.ti.com/lit/ds/symlink/drv2605l.pdf | 36
U12 | 1 | LSM6DSOXTR |  |  |  | LCSC/mpu:LGA-14L_L3.0-W2.5-P0.50-TL | https://www.lcsc.com/datasheet/C481766.pdf | 37
U13 | 1 | ESP32-S3-WROOM-1U-N16R8 |  |  |  | LCSC/esp32:WIRELM-SMD_ESP32-S3-WROOM-1U | https://www.lcsc.com/datasheet/C3013946.pdf | 38
U14,U15 | 2 | VL53L5CXV0GC/1 |  |  |  | LCSC/lidar:LGA-16_L6.4-W3.0_VL53L5CXV0GC-1 | https://www.lcsc.com/datasheet/C3178303.pdf | 39
U16 | 1 | BX-FPC05-1.5H24PX |  |  |  | LCSC/connector:FPC-SMD_24P-P0.50_BX-FPC05-1.5H24PX | https://www.lcsc.com/datasheet/C18078354.pdf | 40
USB1 | 1 | TYPE-C 16PIN 2MD |  |  |  | LCSC/usbc:USB-C-SMD_TYPE-C-6PIN-2MD-073 | https://www.lcsc.com/datasheet/C2765186.pdf | 41

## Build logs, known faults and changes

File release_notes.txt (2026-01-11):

================================================================================
MAIA PROJECT - RELEASE NOTES
================================================================================

Date: 2026-01-11
Author: Vinicius May
Component: DS18B20 Temperature Sensor Driver + OneWire Protocol + LED Fix
Version: v0.2.0
Branch: 2026_01_11__driver_ds18b20_onewire

SUMMARY:
Implemented complete OneWire protocol and DS18B20 temperature sensor driver
with configurable resolution, temperature units, and both blocking/async
read modes. Fixed LED driver initialization bug affecting all test modes.

TECHNICAL DETAILS:
OneWire Protocol Implementation:
- Bit-banging GPIO with precise timing (esp_rom_delay_us)
- Reset pulse with presence detection (480µs low + 70µs sample)
- Write bit: 60µs (0) or 6µs (1) low pulse
- Read bit: 6µs low + 9µs wait + sample
- Byte operations (LSB first, 8 bits per byte)
- Dallas/Maxim CRC8 checksum (polynomial 0x8C)

DS18B20 Driver Features:
- Configurable resolution: 9-bit (0.5°C, 94ms) to 12-bit (0.0625°C, 750ms)
- Temperature unit conversion: Celsius, Fahrenheit, Kelvin
- Blocking mode: ds18b20_read_temperature() - single call, returns result
- Async mode: ds18b20_trigger_conversion() + wait + ds18b20_read_scratchpad()
- Direct scratchpad access for debugging (9 bytes with CRC validation)
- Skip ROM mode (single sensor) with Match ROM prepared for future expansion
- Automatic resolution configuration written to EEPROM on init

CONFIGURATION:
Kconfig menu "DS18B20 Temperature Sensor":
- MAIA_DS18B20_ENABLE (bool, enable/disable driver)
- MAIA_DS18B20_GPIO (int, default GPIO10)
- MAIA_DS18B20_UNIT (choice: Celsius/Fahrenheit/Kelvin)
- MAIA_DS18B20_RESOLUTION (choice: 9/10/11/12-bit)
- MAIA_DS18B20_ROM_MODE (choice: Skip ROM/Match ROM)

ARCHITECTURE:
- OneWire Protocol: components/maia_board/src/maia_onewire.c (BSP layer)
- DS18B20 Driver: components/drivers/ds18b20/ (hardware-agnostic)
- Test Suite: main/tests/test_ds18b20.c (blocking + async validation)
- BSP Integration: maia_board.h exposes OneWire API

FILES MODIFIED:
- components/maia_board/include/maia_board.h (added OneWire API + LED init)
- components/maia_board/src/maia_board.c (added maia_led_init() call)
- components/maia_board/src/maia_onewire.c (complete rewrite, ~200 lines)
- components/maia_board/src/maia_led.c (added maia_led_init() function)
- components/maia_board/Kconfig (added DS18B20 menu)
- components/drivers/CMakeLists.txt (added ds18b20.c)
- main/CMakeLists.txt (added test_ds18b20.c)
- main/main.c (added maia_board_init() to all test modes)
- main/Kconfig.projbuild (added MAIA_TEST_TEMPERATURE_SENSOR)

FILES CREATED:
- components/drivers/ds18b20/include/ds18b20.h (public API, 5 functions)
- components/drivers/ds18b20/src/ds18b20.c (~320 lines, driver logic)
- main/tests/test_ds18b20.c (~200 lines, blocking + async tests)

BUG FIXES:
LED Driver Initialization:
- Issue: LED never initialized, toggle() calls had no effect
- Root cause: maia_led_init() existed but never called
- Fix: Added maia_led_init() call in maia_board_init()
- Impact: LED now works in all test modes (button, ds18b20, blink)

Test Mode Initialization:
- Issue: I2C/GPIO/PWM not initialized in test mode
- Root cause: main.c test mode skipped maia_board_init()
- Fix: Added maia_board_init() before all test_xxx_run() calls
- Impact: Tests now have full BSP initialization

DEPENDENCIES:
- ESP-IDF driver component (GPIO)
- ESP-IDF esp_rom (esp_rom_delay_us for precise timing)
- maia_board component (OneWire protocol)
- FreeRTOS (vTaskDelay for conversion wait)

VALIDATION:
✓ OneWire protocol tested with DS18B20 sensor
✓ Blocking mode: continuous 30s temperature monitoring (2s intervals)
✓ Async mode: non-blocking conversion with LED feedback during wait
✓ CRC validation: all scratchpad reads verified (100% success rate)
✓ Resolution accuracy: 12-bit precision visible (0.0625°C steps)
✓ Real-world test: ice cooling from 22.88°C to 7.31°C tracked correctly
✓ Temperature units: Celsius validated (Fahrenheit/Kelvin configured)
✓ LED now blinks during async test (3x 200ms pulses per cycle)

TESTING NOTES:
Hardware setup:
- DS18B20 sensor on GPIO10 (D2)
- External 4.7kΩ pull-up resistor to 3.3V on data line
- VCC: 3.3V, GND: GND
- LED: GPIO21 (onboard yellow LED on XIAO ESP32S3 Plus)

Test scenarios validated:
- Blocking read: 30 seconds @ 2s intervals (15 readings)
- Async read: 30 seconds with LED feedback (750ms conversion wait)
- Scratchpad dump: 9 bytes displayed with CRC (hex format)
- Temperature range: 7°C to 23°C (ice to room temperature)
- Conversion times: 750ms @ 12-bit (matches datasheet spec)

PERFORMANCE:
- Blocking read: 750ms total (conversion + read)
- Async read: 750ms conversion (non-blocking), 10ms scratchpad read
- CRC calculation: <1ms for 8 bytes
- OneWire bit timing: ±2µs accuracy (within DS18B20 tolerance)

KNOWN LIMITATIONS:
- Skip ROM mode only (single sensor on bus)
- Match ROM mode prepared but ds18b20_search_roms() not implemented
- No alarm functionality (TH/TL registers unused)
- No parasitic power mode (requires VDD connection)
- OneWire timing not validated for ESP32 @ 240MHz (tested @ 160MHz)
- LED active-low logic not auto-detected (assumes active-high)

FUTURE ENHANCEMENTS:
- Implement ds18b20_search_roms() for multi-sensor support
- Add alarm threshold configuration (TH/TL registers)
- Parasitic power mode support (strong pull-up during conversion)
- Temperature moving average filter (noise reduction)
- NVS storage for temperature log (circular buffer)
- Integration with status_monitor service

COMMIT MESSAGE:
feat(drivers): implement DS18B20 OneWire temperature sensor driver

- Add complete OneWire protocol implementation in maia_onewire.c
  * Reset pulse detection with presence check
  * Bit-level read/write operations (LSB first)
  * Byte-level read/write operations
  * Dallas/Maxim CRC8 checksum calculation
  * Precise timing using esp_rom_delay_us()

- Implement DS18B20 driver with async and blocking modes
  * Configurable resolution (9/10/11/12-bit) via Kconfig
  * Configurable temperature unit (Celsius/Fahrenheit/Kelvin)
  * Skip ROM mode for single sensor (Match ROM prepared for future)
  * Non-blocking trigger_conversion() for concurrent operations
  * Direct scratchpad access for debugging
  * CRC validation on all reads

- Add comprehensive Kconfig configuration
  * Enable/disable DS18B20 driver
  * Temperature unit selection (°C/°F/K)
  * Resolution selection (9-12 bit)
  * ROM mode selection (Skip/Match)

- Create test suite for DS18B20
  * Blocking read test (30s continuous monitoring)
  * Async read test (non-blocking with LED feedback)
  * Scratchpad dump and CRC verification
  * Real-world validation with ice cooling (22°C → 7°C)

- Fix LED driver initialization
  * Add maia_led_init() function with GPIO configuration
  * Integrate LED init into maia_board_init()
  * Fix test mode to call maia_board_init() before tests
  * Remove duplicate board init from test_button.c

- Update build system
  * Add ds18b20.c to drivers/CMakeLists.txt
  * Add test_ds18b20.c to main/CMakeLists.txt
  * Update tests.h with new test function

All drivers follow NuttX coding style, Apache 2.0 license, and 78-column 
limit. Hardware validated on XIAO ESP32S3 Plus with external 4.7kΩ pull-up.

Closes: MAIA-002
Tested-by: Vinicius May
Hardware: XIAO ESP32S3 Plus + DS18B20 sensor

================================================================================

Date: 2026-01-11
Author: Vinicius May
Component: Button Driver
Version: v0.1.0
branch: branch: 2026_01_10__driver_button

SUMMARY:
Implemented a robust button driver with state machine, debouncing, and 
comprehensive event detection including single/double clicks, long press, and 
extra long press events for WiFi mode triggers.

TECHNICAL DETAILS:
- State machine with 5 states (IDLE, DEBOUNCING_PRESS, PRESSED, 
  DEBOUNCING_RELEASE, WAIT_DOUBLE_CLICK)
- Hardware debouncing (configurable, default 50ms)
- Three cascading ESP timers for event detection
- ISR-based GPIO interrupt handling with ANY_EDGE detection
- Active-low button configuration (GPIO9) with external pull-up

EVENT DETECTION:
- PRESSED/RELEASED: Immediate physical state changes
- SINGLE_CLICK: Short press (< 2s) with no second click within 500ms
- DOUBLE_CLICK: Two presses within configurable window (default 500ms)
- LONG_PRESS: Hold for 2s (configurable)
- EXTRA_LONG_PRESS_1: Hold for 7s (configurable, intended for WiFi Client mode)
- EXTRA_LONG_PRESS_2: Hold for 12s (configurable, intended for WiFi AP mode)

CONFIGURATION:
All timing parameters configurable via Kconfig:
- MAIA_BUTTON_DEBOUNCE_MS (10-500ms, default 50ms)
- MAIA_BUTTON_DOUBLE_CLICK_WINDOW_MS (100-1000ms, default 500ms)
- MAIA_BUTTON_LONG_PRESS_MS (500-10000ms, default 2000ms)
- MAIA_BUTTON_EXTRA_LONG_PRESS_1_MS (3000-60000ms, default 7000ms)
- MAIA_BUTTON_EXTRA_LONG_PRESS_2_MS (5000-60000ms, default 12000ms)

ARCHITECTURE:
- Driver: components/drivers/button/ (generic, hardware-agnostic)
- BSP: components/maia_board/src/maia_gpio.c (GPIO ISR service installation)
- Test: main/tests/test_button.c (comprehensive validation)
- Integration: Callback-based event notification system

FILES MODIFIED:
- components/maia_board/Kconfig (added Button Configuration menu)
- components/maia_board/src/maia_gpio.c (added gpio_install_isr_service)
- components/drivers/CMakeLists.txt (wrapper component for drivers)
- main/CMakeLists.txt (conditional test compilation)
- main/main.c (test mode selection)

FILES CREATED:
- components/drivers/button/include/button.h (public API)
- components/drivers/button/src/button.c (~450 lines, state machine)
- main/tests/test_button.c (driver validation)
- main/tests/test_blink.c (LED hardware test)
- main/tests/tests.h (test suite interface)

DEPENDENCIES:
- ESP-IDF driver component (GPIO, esp_timer)
- maia_board component (hardware abstraction)
- FreeRTOS (task delay in tests)

VALIDATION:
✓ All 7 events tested and working correctly
✓ Debouncing eliminates electrical noise
✓ Cascading timer efficiently handles multiple thresholds
✓ LED feedback on PRESSED/RELEASED events
✓ No false triggers or missed events
✓ Configurable via menuconfig without recompilation

FUTURE ENHANCEMENTS:
- WiFi manager service to consume EXTRA_LONG_PRESS events
- Visual feedback patterns for different events (LED blink patterns)
- NVS storage for dynamic timing configuration
- Multi-button support (if hardware expansion needed)

TESTING NOTES:
Hardware setup: GPIO9 (D10) connected to momentary push button with pull-up
Test scenarios validated:
- Single press/release
- Double click (< 500ms between presses)  
- Long press (2s hold)
- Extra long press 1 (7s hold)
- Extra long press 2 (12s hold)
- Button bouncing filtered correctly

KNOWN LIMITATIONS:
- Single button only (GPIO9 hardcoded in BSP)
- External pull-up required (10kΩ recommended)
- ISR service must be installed before button_init()
- Callback cannot be NULL (checked at init)

COMMIT MESSAGE:
feat(button): implement complete button driver with state machine

- Add button driver with debouncing and event detection
- Support 7 event types: PRESSED, RELEASED, SINGLE_CLICK, DOUBLE_CLICK,
  LONG_PRESS, EXTRA_LONG_PRESS_1, EXTRA_LONG_PRESS_2
- Implement cascading ESP timers for efficient threshold detection
- Add Kconfig menu for all timing parameters
- Create test framework with LED feedback
- Install GPIO ISR service in maia_gpio.c
- Use wrapper component architecture for drivers

Closes: MAIA-001
Tested-by: Vinicius May
Hardware: XIAO ESP32S3 Plus

================================================================================

==============================================================================
branch: 2026_01_10__Menuconfig_refinements
changes:

================================================================================
MAIA PROJECT - DETAILED CHANGES
================================================================================

1. Menuconfig Structure - MAIA Board Configuration
================================================================================

MAIA Board Configuration
│
├── [x] Enable blink test (disable MAIA App)
│
├── General Configuration ───────────────────────────────────────────
│   │
│   ├── [x] Log general configuration at startup
│   │
│   ├── Timeouts ───>
│   │   ├── Sync data to server timeout (minutes): [10]
│   │   ├── Display turn off timeout (seconds): [30]
│   │   └── Display screen change timeout (seconds): [5]
│   │
│   └── Miscellaneous ───>
│       │
│       ├── Software Version ───>
│       │   ├── Major version: [1]
│       │   ├── Minor version: [0]
│       │   └── Patch version: [0]
│       │
│       ├── Animal Information ───>
│       │   ├── Species: [Dog]
│       │   ├── Breed: [Unknown]
│       │   ├── Name: [MAIA]
│       │   ├── Age (years): [0]
│       │   ├── Weight (kg): [0]
│       │   ├── Blood type: [Unknown]
│       │   ├── Comorbidity: [None]
│       │   └── Allergy: [None]
│       │
│       └── Tutor Information ───>
│           ├── First name: []
│           ├── Surname: []
│           ├── Phone: []
│           ├── Email: []
│           ├── Social media: []
│           ├── Country: []
│           ├── State: []
│           ├── City: []
│           └── Street: []
│
├── Radio Configuration ─────────────────────────────────────────────
│   │
│   ├── Bluetooth Configuration ───>
│   │   └── (TODO: Add BLE configs when needed)
│   │
│   └── WiFi Configuration ───>
│       │
│       ├── Self (Access Point Mode) ───>
│       │   ├── AP SSID: [MAIA-Setup]
│       │   └── AP Password: [maiamute2026]
│       │
│       ├── Server (Station Mode) ───>
│       │   ├── Server WiFi SSID: []
│       │   ├── Server WiFi Password: []
│       │   └── Data sync interval (minutes): [10]
│       │
│       └── Button Triggers ───>
│           ├── Button hold time to enter AP mode (ms): [30000]
│           ├── LED blink frequency in AP mode (Hz): [10]
│           ├── Button hold time to enter Station mode (ms): [10000]
│           └── LED blink frequency in Station mode (Hz): [10]
│
├── GPIO Configuration ──────────────────────────────────────────────
│   │
│   ├── Haptic Motors (ERM) ───>
│   │   │
│   │   ├── Haptic Motor Right ───>
│   │   │   └── PWM frequency (Hz): [1000]
│   │   │
│   │   └── Haptic Motor Left ───>
│   │       └── PWM frequency (Hz): [1000]
│   │
│   ├── Button Configuration ───>
│   │   ├── Debounce time (ms): [50]
│   │   └── Long press threshold (ms): [2000]
│   │
│   └── LEDs Configuration ───>
│       ├── Status LED GPIO
│       │   ├── ( ) GPIO21 (Onboard RGB LED)
│       │   └── (x) GPIO39 (MTCK - External)
│       │
│       └── (21 or 39 based on selection above)
│
└── Bus Configuration ───────────────────────────────────────────────
    │
    ├── I2C bus frequency (Hz): [400000]
    │
    ├── I2C Devices ───>
    │   │
    │   ├── Motor Driver (DRV2605L) ───>
    │   │   ├── [x] Enable DRV2605L driver
    │   │   └── I2C address: [0x5A]
    │   │
    │   ├── Display (SSD1306) ───>
    │   │   ├── [x] Enable SSD1306 OLED
    │   │   ├── I2C address: [0x3C]
    │   │   └── Display contrast (%): [100]
    │   │
    │   ├── IMU (MPU6050) ───>
    │   │   ├── [x] Enable MPU6050 IMU
    │   │   └── I2C address: [0x68]
    │   │
    │   └── LiDAR (VL53L5CX) ───>
    │       ├── [x] Enable VL53L5CX ToF sensors
    │       ├── Left sensor I2C address: [0x54]
    │       ├── Right sensor I2C address: [0x52]
    │       ├── [x] Filter target status 5 (Threshold fail)
    │       └── [x] Filter target status 6 (Signal fail)
    │
    └── OneWire Devices ───>
        │
        └── Temperature Sensor (DS18B20) ───>
            └── [x] Enable DS18B20 sensor

================================================================================
2. Files Created
================================================================================

2.1. components/maia_board/Kconfig
───────────────────────────────────
Brand new complete file with all menuconfig structure above.

Main symbols created:
- CONFIG_MAIA_LOG_GENERAL_CONFIG
- CONFIG_MAIA_TIMEOUT_SYNC_DATA_MIN
- CONFIG_MAIA_TIMEOUT_DISPLAY_OFF_SEC
- CONFIG_MAIA_TIMEOUT_DISPLAY_SCREEN_SEC
- CONFIG_MAIA_SW_VERSION_MAJOR/MINOR/PATCH
- CONFIG_MAIA_ANIMAL_* (8 symbols)
- CONFIG_MAIA_TUTOR_* (9 symbols)
- CONFIG_MAIA_WIFI_AP_SSID/PASSWORD
- CONFIG_MAIA_WIFI_STA_SSID/PASSWORD
- CONFIG_MAIA_WIFI_SYNC_INTERVAL_MIN
- CONFIG_MAIA_BUTTON_AP_MODE_HOLD_MS
- CONFIG_MAIA_LED_BLINK_FREQ_AP_HZ
- CONFIG_MAIA_BUTTON_STA_MODE_HOLD_MS
- CONFIG_MAIA_LED_BLINK_FREQ_STA_HZ
- CONFIG_MAIA_PWM_FREQ_MOTOR_LEFT/RIGHT
- CONFIG_MAIA_BUTTON_DEBOUNCE_MS
- CONFIG_MAIA_BUTTON_LONG_PRESS_MS
- CONFIG_MAIA_LED_GPIO_21 or CONFIG_MAIA_LED_GPIO_39
- CONFIG_MAIA_LED_STATUS_PIN
- CONFIG_MAIA_I2C_FREQ_HZ
- CONFIG_MAIA_*_ENABLE (5 devices)
- CONFIG_MAIA_*_I2C_ADDR (6 addresses)
- CONFIG_MAIA_SSD1306_CONTRAST
- CONFIG_MAIA_VL53L5CX_FILTER_STATUS_5/6

2.2. components/maia_board/src/maia_config.c
─────────────────────────────────────────────
New file - 119 lines

Purpose: Log all general configurations at startup

Structure:
- Apache 2.0 header
- Includes: maia_board.h, esp_log.h
- TAG: "[MAIA_CONFIG]"
- Function: maia_config_log()
  └── Protected by #ifdef CONFIG_MAIA_LOG_GENERAL_CONFIG
  └── Logs:
      - Software version (v{major}.{minor}.{patch})
      - Timeouts (3 values)
      - Animal info (8 fields)
      - Tutor info (9 fields)

Dependencies:
- Called in maia_board.c
- Prototype in maia_board.h

2.3. components/maia_board/src/maia_led.c
──────────────────────────────────────────
New file - 75 lines

Purpose: Status LED control (set/toggle)

Structure:
- Apache 2.0 header
- Includes: maia_board.h, driver/gpio.h
- Functions:
  1. maia_led_set(bool state)
     └── Turn LED on/off via gpio_set_level()
  
  2. maia_led_toggle(void)
     └── Toggle LED state via gpio_get_level() + gpio_set_level()

IMPORTANT: LED GPIO initialization was moved to maia_gpio.c

================================================================================
3. Files Modified
================================================================================

3.1. main/Kconfig.projbuild
────────────────────────────
Change: Added line to include maia_board Kconfig

BEFORE:
```kconfig
menu "MAIA_BOARD"
    config MAIA_TEST_BLINK
        bool "Enable blink test (disable Maia App)"
        default n
endmenu
```

AFTER:
```kconfig
menu "MAIA_BOARD"
    config MAIA_TEST_BLINK
        bool "Enable blink test (disable Maia App)"
        default n
endmenu

rsource "../components/maia_board/Kconfig"
```

3.2. components/maia_board/include/maia_board.h
────────────────────────────────────────────────
Detailed changes:

A) Defines section - New Kconfig symbols:

I2C Bus:
```c
// BEFORE:
#define MAIA_I2C_FREQ_HZ            400000

// AFTER:
#define MAIA_I2C_FREQ_HZ            CONFIG_MAIA_I2C_FREQ_HZ
```

PWM Motors:
```c
// BEFORE:
#define MAIA_PWM_FREQ_HZ            1000
#define MAIA_PWM_TIMER              LEDC_TIMER_0

// AFTER:
#define MAIA_PWM_FREQ_MOTOR_LEFT    CONFIG_MAIA_PWM_FREQ_MOTOR_LEFT
#define MAIA_PWM_FREQ_MOTOR_RIGHT   CONFIG_MAIA_PWM_FREQ_MOTOR_RIGHT
#define MAIA_PWM_TIMER_LEFT         LEDC_TIMER_0
#define MAIA_PWM_TIMER_RIGHT        LEDC_TIMER_1
```

Status LED (NEW):
```c
/* Status LED */
#define MAIA_GPIO_LED_STATUS        CONFIG_MAIA_LED_STATUS_PIN
```

I2C Device Addresses:
```c
// BEFORE (hardcoded):
#define MAIA_I2C_ADDR_SSD1306       0x3C
#define MAIA_I2C_ADDR_TOF1          0x54
#define MAIA_I2C_ADDR_TOF2          0x52
#define MAIA_I2C_ADDR_DRV2605L      0x5A
#define MAIA_I2C_ADDR_MPU6050       0x68

// AFTER (from Kconfig):
#define MAIA_I2C_ADDR_SSD1306       CONFIG_MAIA_SSD1306_I2C_ADDR
#define MAIA_I2C_ADDR_TOF1          CONFIG_MAIA_VL53L5CX_LEFT_I2C_ADDR
#define MAIA_I2C_ADDR_TOF2          CONFIG_MAIA_VL53L5CX_RIGHT_I2C_ADDR
#define MAIA_I2C_ADDR_DRV2605L      CONFIG_MAIA_DRV2605L_I2C_ADDR
#define MAIA_I2C_ADDR_MPU6050       CONFIG_MAIA_MPU6050_I2C_ADDR
```

B) Prototypes added:

After maia_board_init():
```c
#ifdef CONFIG_MAIA_LOG_GENERAL_CONFIG
void maia_config_log(void);
#endif
```

After maia_onewire_init():
```c
esp_err_t maia_led_set(bool state);
esp_err_t maia_led_toggle(void);
```

3.3. components/maia_board/src/maia_board.c
────────────────────────────────────────────
Change: Added call to maia_config_log()

Location: Right after ESP_LOGI(TAG, "============ Initializing MAIA board ============");
```c
esp_err_t maia_board_init(void)
{
  esp_err_t ret;
  
  ESP_LOGI(TAG, "============ Initializing MAIA board ============");
  
  // NEW:
#ifdef CONFIG_MAIA_LOG_GENERAL_CONFIG
  maia_config_log();
#endif

  /* Initialize GPIO pins */
  ret = maia_gpio_init();
  
  // ... rest of the code
}
```

3.4. components/maia_board/src/maia_gpio.c
───────────────────────────────────────────
Changes:

A) VL53L5CX wrapping with ifdef:
```c
// BEFORE:
io_conf.pin_bit_mask = (1ULL << MAIA_GPIO_TOF1_LPN) | ...

// AFTER:
#ifdef CONFIG_MAIA_VL53L5CX_ENABLE
  io_conf.pin_bit_mask = (1ULL << MAIA_GPIO_TOF1_LPN) | ...
  // ... all ToF code
#endif
```

B) MPU6050 wrapping with ifdef:
```c
// BEFORE:
io_conf.pin_bit_mask = (1ULL << MAIA_GPIO_IMU_INT);

// AFTER:
#ifdef CONFIG_MAIA_MPU6050_ENABLE
  io_conf.pin_bit_mask = (1ULL << MAIA_GPIO_IMU_INT);
  // ... all IMU code
#endif
```

C) Status LED initialization (NEW):
Added at the end, before ESP_LOGI(TAG, "GPIO pins initialized successfully");
```c
  /*
   * Status LED
   * * * * * * * * * * * * * * * */
  
  /* Output pin for status indication */
  
  io_conf.pin_bit_mask = (1ULL << MAIA_GPIO_LED_STATUS);
  io_conf.intr_type = GPIO_INTR_DISABLE;
  io_conf.mode = GPIO_MODE_OUTPUT;
  io_conf.pull_down_en = GPIO_PULLDOWN_DISABLE;
  io_conf.pull_up_en = GPIO_PULLUP_DISABLE;
  
  ret = gpio_config(&io_conf);
  if (ret != ESP_OK)
    {
      ESP_LOGE(TAG, "Failed to configure status LED pin");
      return ret;
    }
  
  gpio_set_level(MAIA_GPIO_LED_STATUS, 0);         /* Start with LED off */
```

D) Function description update:
```c
// BEFORE:
 *   - Button  pin  (input, external pull-up)

// AFTER:
 *   - Button  pin  (input, external pull-up)
 *   - Status LED   (output)
```

3.5. components/maia_board/src/maia_i2c.c
──────────────────────────────────────────
Change: NONE

Reason: Already used MAIA_I2C_FREQ_HZ from header, which now points to Kconfig

3.6. components/maia_board/src/maia_onewire.c
──────────────────────────────────────────────
Change: Complete wrapping with ifdef
```c
// BEFORE:
esp_err_t maia_onewire_init(void)
{
  ESP_LOGI(TAG, "Initializing OneWire bus (GPIO%d)", MAIA_GPIO_ONEWIRE);
  // ... code
  return ESP_OK;
}

// AFTER:
#ifdef CONFIG_MAIA_DS18B20_ENABLE
esp_err_t maia_onewire_init(void)
{
  ESP_LOGI(TAG, "Initializing OneWire bus (GPIO%d)", MAIA_GPIO_ONEWIRE);
  // ... code
  return ESP_OK;
}
#endif
```

3.7. components/maia_board/src/maia_pwm.c
──────────────────────────────────────────
Main changes:

A) Removed hardcoded define:
```c
// BEFORE:
#define MAIA_PWM_FREQ_HZ CONFIG_MAIA_PWM_FREQ_HZ

// AFTER:
(removed - now comes directly from header)
```

B) Initialization log:
```c
// BEFORE:
ESP_LOGI(TAG, "Initializing PWM (freq=%dHz, res=%d-bit)",
         MAIA_PWM_FREQ_HZ, MAIA_PWM_RESOLUTION);

// AFTER:
ESP_LOGI(TAG, "Initializing PWM (freq=%dHz, res=%d-bit)",
         MAIA_PWM_FREQ_MOTOR_LEFT, MAIA_PWM_RESOLUTION);
```

C) Two separate LEDC timers:
```c
// BEFORE (1 timer):
ledc_timer_config_t timer_conf = {
    .speed_mode = MAIA_PWM_MODE,
    .duty_resolution = MAIA_PWM_RESOLUTION,
    .timer_num = MAIA_PWM_TIMER,
    .freq_hz = MAIA_PWM_FREQ_HZ,
    .clk_cfg = LEDC_AUTO_CLK,
};
ret = ledc_timer_config(&timer_conf);

// AFTER (2 timers):
/* Configure LEDC timer for Motor Left */
ledc_timer_config_t timer_left = {
    .speed_mode = MAIA_PWM_MODE,
    .duty_resolution = MAIA_PWM_RESOLUTION,
    .timer_num = MAIA_PWM_TIMER_LEFT,
    .freq_hz = MAIA_PWM_FREQ_MOTOR_LEFT,
    .clk_cfg = LEDC_AUTO_CLK,
};
ret = ledc_timer_config(&timer_left);

// ... error handling

/* Configure LEDC timer for Motor Right */
ledc_timer_config_t timer_right = {
    .speed_mode = MAIA_PWM_MODE,
    .duty_resolution = MAIA_PWM_RESOLUTION,
    .timer_num = MAIA_PWM_TIMER_RIGHT,
    .freq_hz = MAIA_PWM_FREQ_MOTOR_RIGHT,
    .clk_cfg = LEDC_AUTO_CLK,
};
ret = ledc_timer_config(&timer_right);
```

D) Channels now reference their respective timers:
```c
// BEFORE:
ledc_channel_config_t ch_left = {
    // ...
    .timer_sel = MAIA_PWM_TIMER,
    // ...
};

// AFTER:
ledc_channel_config_t ch_left = {
    // ...
    .timer_sel = MAIA_PWM_TIMER_LEFT,
    // ...
};

ledc_channel_config_t ch_right = {
    // ...
    .timer_sel = MAIA_PWM_TIMER_RIGHT,
    // ...
};
```

E) Description update:
```c
// BEFORE:
 *   - Timer: 1kHz, 8-bit resolution (0-255 duty)

// AFTER:
 *   - Timer Left:  Motor Left frequency, 8-bit resolution (0-255 duty)
 *   - Timer Right: Motor Right frequency, 8-bit resolution (0-255 duty)
```

3.8. components/maia_board/CMakeLists.txt
──────────────────────────────────────────
Change: Added new source files
```cmake
# BEFORE:
idf_component_register(
    SRCS
        "src/maia_board.c"
        "src/maia_i2c.c"
        "src/maia_gpio.c"
        "src/maia_pwm.c"
        "src/maia_onewire.c"
    INCLUDE_DIRS
        "include"
    REQUIRES
        driver
)

# AFTER:
idf_component_register(
    SRCS
        "src/maia_config.c"       # NEW
        "src/maia_board.c"
        "src/maia_i2c.c"
        "src/maia_gpio.c"
        "src/maia_pwm.c"
        "src/maia_onewire.c"
        "src/maia_led.c"          # NEW
    INCLUDE_DIRS
        "include"
    REQUIRES
        driver
)
```

================================================================================
4. Initialization Flow
================================================================================

Remains unchanged:

app_main()
└── maia_board_init()
├── [maia_config_log()]  ← NEW (if CONFIG_MAIA_LOG_GENERAL_CONFIG=y)
├── maia_gpio_init()     ← Now includes LED status
├── maia_i2c_init()
├── maia_pwm_init()      ← Now with 2 timers
└── maia_onewire_init()  ← Now conditional

================================================================================
5. Line Count Added/Modified
================================================================================

| File | Lines Before | Lines After | Delta |
|---|---|---|---|
| Kconfig | 0 (new) | 287 | +287  |
| maia_config.c | 0 (new) | 119 | +119  |
| maia_led.c | 0 (new) | 75 | +75 |
| maia_board.h | 205 | 228 | +23 |
| maia_board.c | 117 | 121 | +4 |
| maia_gpio.c | 182 | 205 | +23 |
| maia_pwm.c | 136 | 178 | +42 |
| maia_onewire.c | 60 | 62 | +2 |
| CMakeLists.txt | 11 | 13 | +2 |
| Kconfig.projbuild | 9 | 11 | +2 |
| **TOTAL** | **720** | **1299** | **+579** |

================================================================================
6. Kconfig Symbols Created (Total: 46)
================================================================================

General Configuration (24):
──────────────────────────
- CONFIG_MAIA_LOG_GENERAL_CONFIG
- CONFIG_MAIA_TIMEOUT_SYNC_DATA_MIN
- CONFIG_MAIA_TIMEOUT_DISPLAY_OFF_SEC
- CONFIG_MAIA_TIMEOUT_DISPLAY_SCREEN_SEC
- CONFIG_MAIA_SW_VERSION_MAJOR
- CONFIG_MAIA_SW_VERSION_MINOR
- CONFIG_MAIA_SW_VERSION_PATCH
- CONFIG_MAIA_ANIMAL_SPECIES
- CONFIG_MAIA_ANIMAL_BREED
- CONFIG_MAIA_ANIMAL_NAME
- CONFIG_MAIA_ANIMAL_AGE
- CONFIG_MAIA_ANIMAL_WEIGHT
- CONFIG_MAIA_ANIMAL_BLOOD_TYPE
- CONFIG_MAIA_ANIMAL_COMORBIDITY
- CONFIG_MAIA_ANIMAL_ALLERGY
- CONFIG_MAIA_TUTOR_NAME
- CONFIG_MAIA_TUTOR_SURNAME
- CONFIG_MAIA_TUTOR_PHONE
- CONFIG_MAIA_TUTOR_EMAIL
- CONFIG_MAIA_TUTOR_SOCIAL_MEDIA
- CONFIG_MAIA_TUTOR_COUNTRY
- CONFIG_MAIA_TUTOR_STATE
- CONFIG_MAIA_TUTOR_CITY
- CONFIG_MAIA_TUTOR_STREET

Radio Configuration (9):
─────────────────────────
- CONFIG_MAIA_WIFI_AP_SSID
- CONFIG_MAIA_WIFI_AP_PASSWORD
- CONFIG_MAIA_WIFI_STA_SSID
- CONFIG_MAIA_WIFI_STA_PASSWORD
- CONFIG_MAIA_WIFI_SYNC_INTERVAL_MIN
- CONFIG_MAIA_BUTTON_AP_MODE_HOLD_MS
- CONFIG_MAIA_LED_BLINK_FREQ_AP_HZ
- CONFIG_MAIA_BUTTON_STA_MODE_HOLD_MS
- CONFIG_MAIA_LED_BLINK_FREQ_STA_HZ

GPIO Configuration (6):
───────────────────────
- CONFIG_MAIA_PWM_FREQ_MOTOR_RIGHT
- CONFIG_MAIA_PWM_FREQ_MOTOR_LEFT
- CONFIG_MAIA_BUTTON_DEBOUNCE_MS
- CONFIG_MAIA_BUTTON_LONG_PRESS_MS
- CONFIG_MAIA_LED_GPIO_21 / CONFIG_MAIA_LED_GPIO_39
- CONFIG_MAIA_LED_STATUS_PIN

Bus Configuration (14):
───────────────────────
- CONFIG_MAIA_I2C_FREQ_HZ
- CONFIG_MAIA_DRV2605L_ENABLE
- CONFIG_MAIA_DRV2605L_I2C_ADDR
- CONFIG_MAIA_SSD1306_ENABLE
- CONFIG_MAIA_SSD1306_I2C_ADDR
- CONFIG_MAIA_SSD1306_CONTRAST
- CONFIG_MAIA_MPU6050_ENABLE
- CONFIG_MAIA_MPU6050_I2C_ADDR
- CONFIG_MAIA_VL53L5CX_ENABLE
- CONFIG_MAIA_VL53L5CX_LEFT_I2C_ADDR
- CONFIG_MAIA_VL53L5CX_RIGHT_I2C_ADDR
- CONFIG_MAIA_VL53L5CX_FILTER_STATUS_5
- CONFIG_MAIA_VL53L5CX_FILTER_STATUS_6
- CONFIG_MAIA_DS18B20_ENABLE

================================================================================
7. Component Dependencies
================================================================================
maia_board.h
↓
├──> maia_board.c (calls maia_config_log)
├──> maia_config.c (uses Kconfig defines)
├──> maia_gpio.c (initializes LED status)
├──> maia_led.c (controls LED)
├──> maia_i2c.c
├──> maia_pwm.c (uses 2 timers)
└──> maia_onewire.c (conditional)
Kconfig
↓
├──> maia_board.h (defines)
└──> maia_config.c (logs values)

================================================================================
8. Main Concepts Implemented
================================================================================

Complete Configurability via Menuconfig
────────────────────────────────────────
- Hardware (I2C, PWM, GPIOs)
- Peripherals (enable/disable devices)
- Application (timeouts, WiFi modes)
- Information (animal, tutor)

Modularity
──────────
- Each peripheral can be enabled/disabled
- Code wrapped in #ifdef
 
Separation of Responsibilities
───────────────────────────────
- maia_gpio.c: GPIO initialization
- maia_led.c: LED control (not initialization)
- maia_config.c: Configuration logging

Hardware Flexibility
────────────────────
- Status LED: choose between GPIO21 (onboard) or GPIO39 (external)
- PWM: independent frequencies for each motor
- I2C: configurable frequency

WiFi Dual Mode
──────────────
- AP Mode: ESP32 creates network for configuration
- STA Mode: ESP32 connects to WiFi network for data sync
- Configurable triggers via button

================================================================================

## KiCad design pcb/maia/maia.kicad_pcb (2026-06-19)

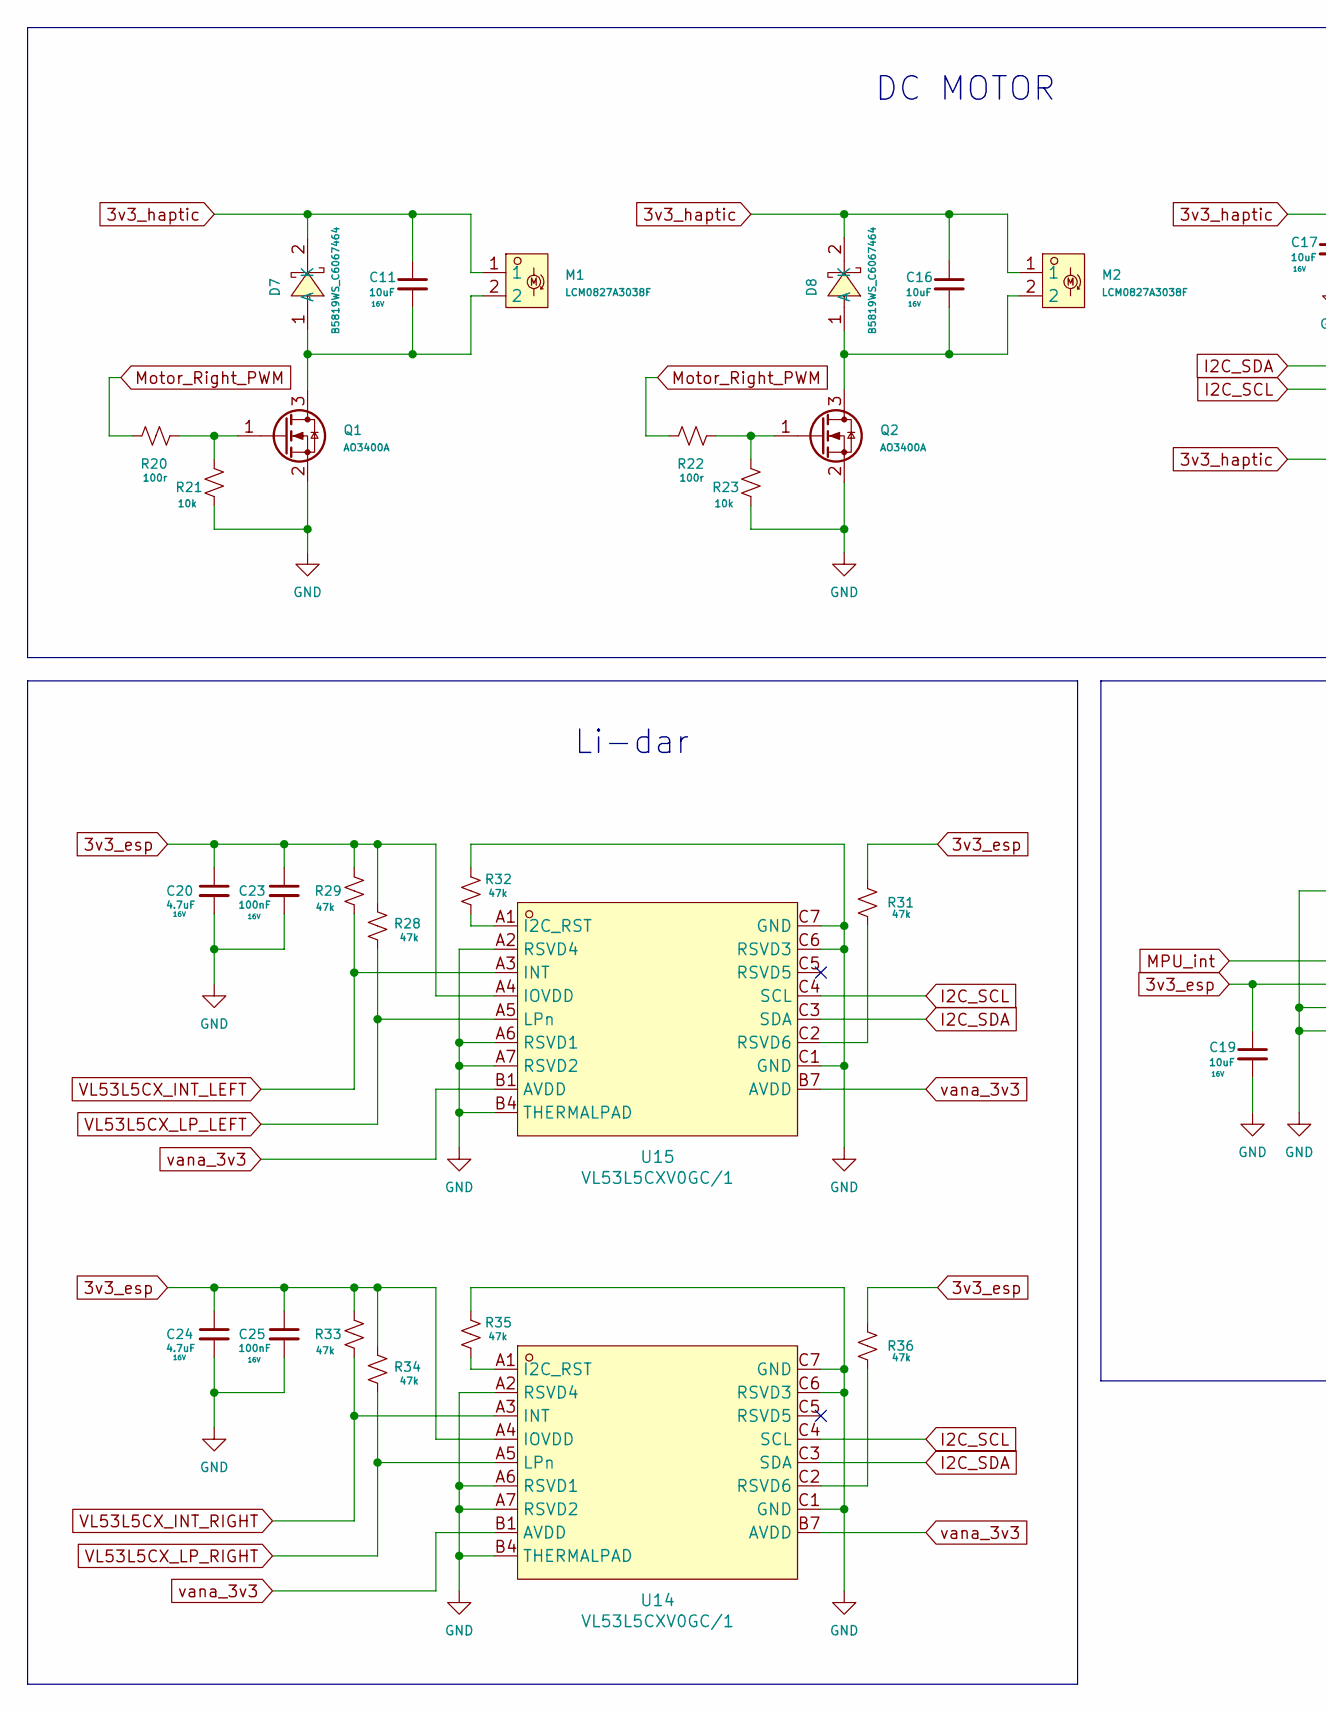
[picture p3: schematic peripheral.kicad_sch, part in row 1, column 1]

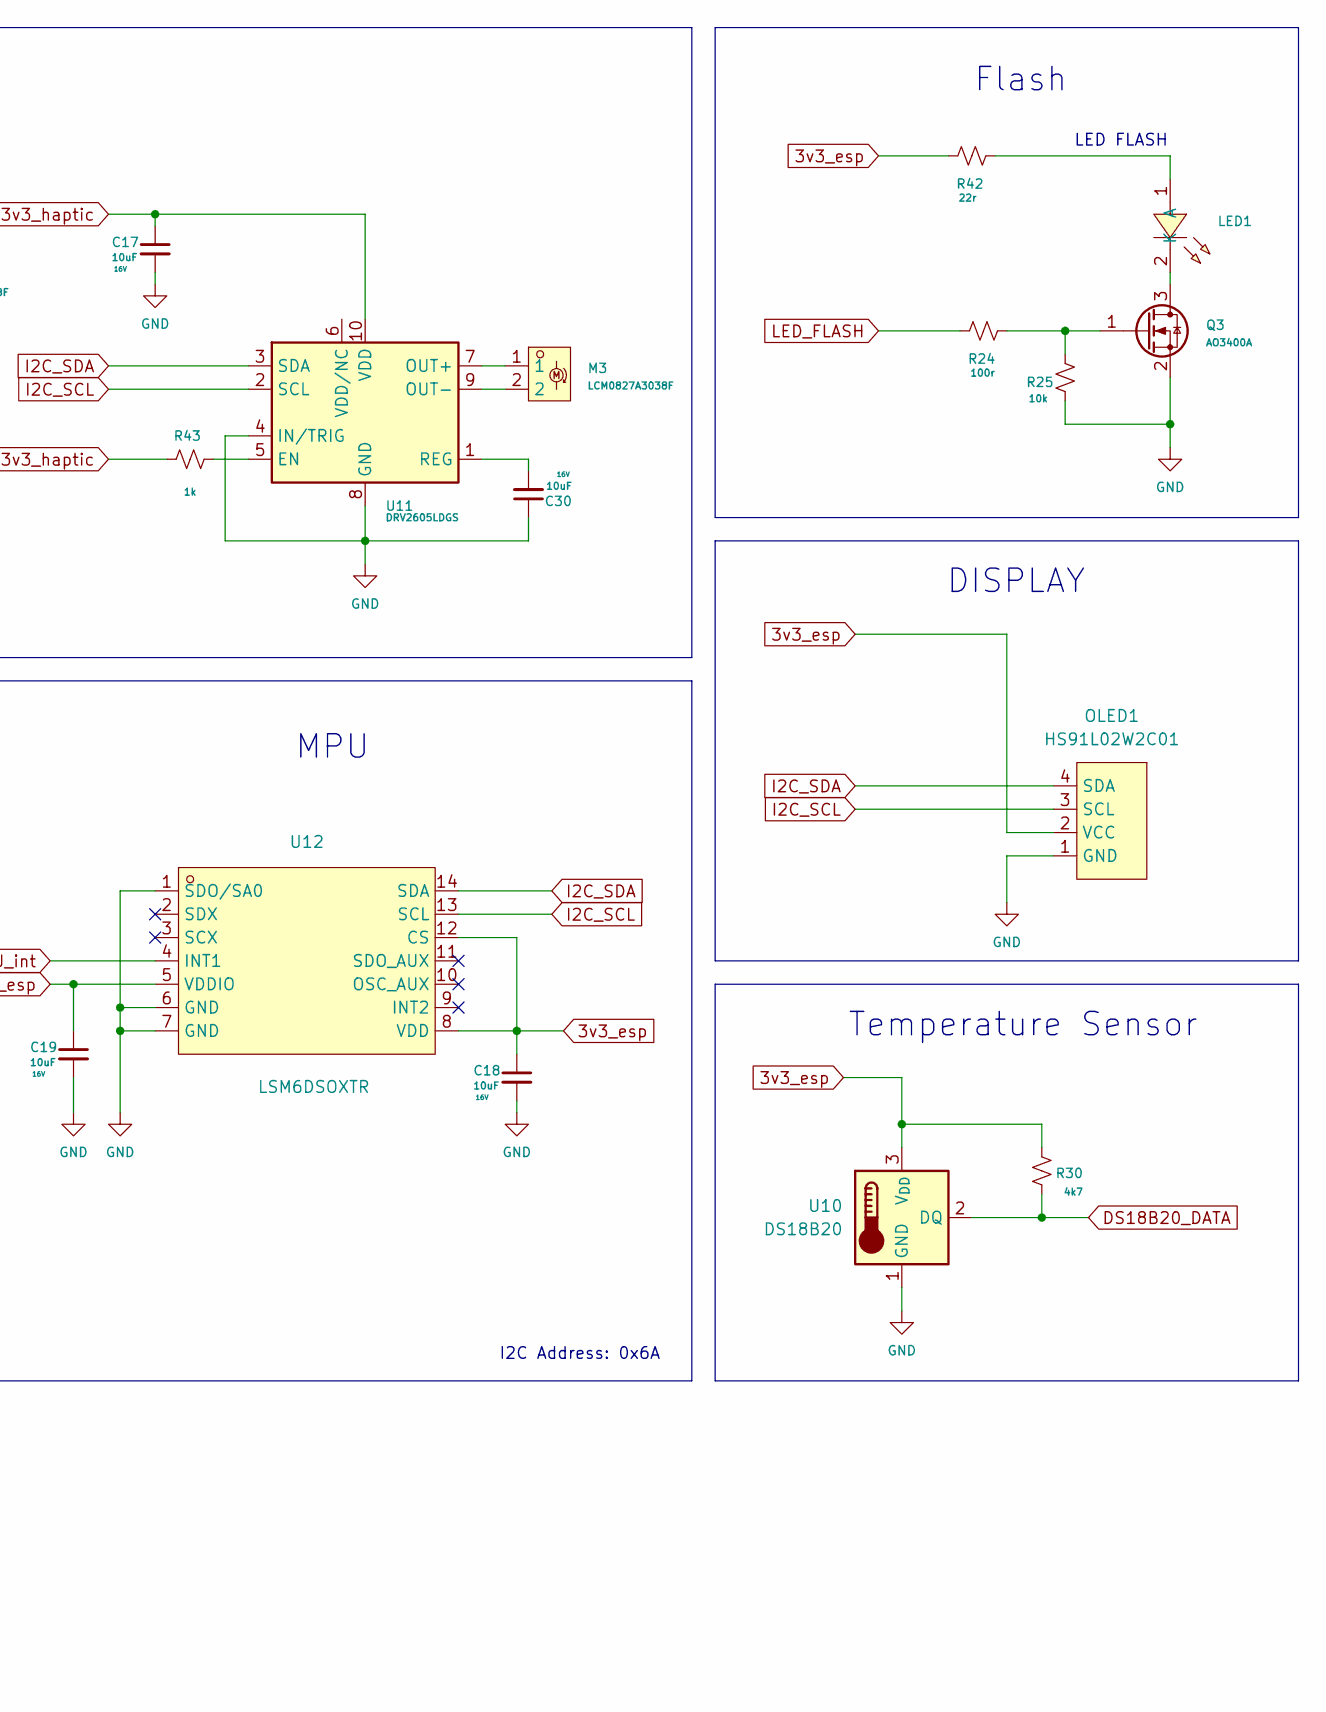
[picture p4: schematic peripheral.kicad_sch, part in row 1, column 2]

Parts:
C11, C16, C17, C18, C19, C30: 10uF; C_0402_1005Metric; Voltage 16V; Tolerance 10%
C20, C24: 4.7uF; C_0402_1005Metric; Voltage 16V; Tolerance 10%
C23, C25: 100nF; C_0402_1005Metric; Voltage 16V; Tolerance 10%
D7, D8: B5819WS_C6067464; SOD-323F_L1.7-W1.3-LS2.5-R-RD-1; MPN B5819WS; LCSC Part C6067464
LED1: XL-3030WWC-1W-3V; LED-SMD_L3.0-W3.0_WHITE; MPN XL-3030WWC-1W-3V; LCSC Part C2843893
M1, M2, M3: LCM0827A3038F; VIBRATIONMOTOR-TH_LCM0827A3038F; MPN LCM0827A3038F; LCSC Part C2759981
OLED1: HS91L02W2C01; OLED-TH_L38.0-W12.0_HS91L02W2C01; MPN HS91L02W2C01; LCSC Part C5248081
Q1, Q2, Q3: AO3400A; SOT-23
R20, R22, R24: 100r; R_0603_1608Metric
R21, R23, R25: 10k; R_0603_1608Metric
R28, R29, R31, R32, R33, R34, R35, R36: 47k; R_0603_1608Metric
R30: 4k7; R_0603_1608Metric
R42: 22r; R_0603_1608Metric
R43: 1k; R_0603_1608Metric
U10: DS18B20; TO-92_Inline
U11: DRV2605LDGS; TSSOP-10_3x3mm_P0.5mm
U12: LSM6DSOXTR; LGA-14L_L3.0-W2.5-P0.50-TL; MPN LSM6DSOXTR; LCSC Part C481766
U14, U15: VL53L5CXV0GC/1; LGA-16_L6.4-W3.0_VL53L5CXV0GC-1; MPN VL53L5CXV0GC/1; LCSC Part C3178303

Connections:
3v3_esp: C18.1, C19.1, C20.1, C23.1, C24.1, C25.1, OLED1.2 (VCC), R28.2, R29.2, R30.2, R31.1, R33.2, R34.2, R36.1, R42.1, U10.3 (V_{DD}), U12.5 (VDDIO), U12.8 (VDD), U12.12 (CS), U14.A4 (IOVDD), U15.A4 (IOVDD); also elsewhere on the board
3v3_haptic: C11.1, C16.1, C17.1, D7.2 (K), D8.2 (K), M1.1, M2.1, R43.2, U11.10 (VDD); also elsewhere on the board
DS18B20_DATA: R30.1, U10.2 (DQ); also elsewhere on the board
GND: C17.2, C18.2, C19.2, C20.2, C23.2, C24.2, C25.2, C30.1, OLED1.1 (GND), Q1.2 (S), Q2.2 (S), Q3.2 (S), R21.2, R23.2, R25.2, R32.2, R35.2, U10.1 (GND), U11.4 (IN/TRIG), U11.8 (GND), U12.1 (SDO/SA0), U12.6 (GND), U12.7 (GND), U14.A2 (RSVD4), U14.A6 (RSVD1), U14.A7 (RSVD2), U14.B4 (THERMALPAD), U14.C1 (GND), U14.C6 (RSVD3), U14.C7 (GND), U15.A2 (RSVD4), U15.A6 (RSVD1), U15.A7 (RSVD2), U15.B4 (THERMALPAD), U15.C1 (GND), U15.C6 (RSVD3), U15.C7 (GND); also elsewhere on the board
I2C_SCL: OLED1.3 (SCL), U11.2 (SCL), U12.13 (SCL), U14.C4 (SCL), U15.C4 (SCL); also elsewhere on the board
I2C_SDA: OLED1.4 (SDA), U11.3 (SDA), U12.14 (SDA), U14.C3 (SDA), U15.C3 (SDA); also elsewhere on the board
LED_FLASH: R24.1; also elsewhere on the board
MPU_int: U12.4 (INT1); also elsewhere on the board
Motor_Right_PWM: R20.1, R22.1; also elsewhere on the board
unnamed: C11.2, D7.1 (A), M1.2, Q1.3 (D)
unnamed: C16.2, D8.1 (A), M2.2, Q2.3 (D)
unnamed: LED1.1 (A), R42.2
unnamed: LED1.2 (K), Q3.3 (D)
unnamed: Q1.1 (G), R20.2, R21.1
unnamed: Q2.1 (G), R22.2, R23.1
unnamed: Q3.1 (G), R24.2, R25.1
unnamed: R43.1, U11.5 (EN)
unnamed: M3.1, U11.7 (OUT+)
unnamed: M3.2, U11.9 (OUT-)
unnamed: C30.2, U11.1 (REG)
unnamed: R35.1, U14.A1 (I2C_RST)
unnamed: R36.2, U14.C2 (RSVD6)
unnamed: R32.1, U15.A1 (I2C_RST)
unnamed: R31.2, U15.C2 (RSVD6)
VL53L5CX_INT_LEFT: R29.1, U15.A3 (INT); also elsewhere on the board
VL53L5CX_INT_RIGHT: R33.1, U14.A3 (INT); also elsewhere on the board
VL53L5CX_LP_LEFT: R28.1, U15.A5 (LPn); also elsewhere on the board
VL53L5CX_LP_RIGHT: R34.1, U14.A5 (LPn); also elsewhere on the board
vana_3v3: U14.B1 (AVDD), U14.B7 (AVDD), U15.B1 (AVDD), U15.B7 (AVDD); also elsewhere on the board

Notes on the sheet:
DC MOTOR
DISPLAY
Temperature Sensor
Li-dar
MPU
LED FLASH
Flash
I2C Address: 0x6A

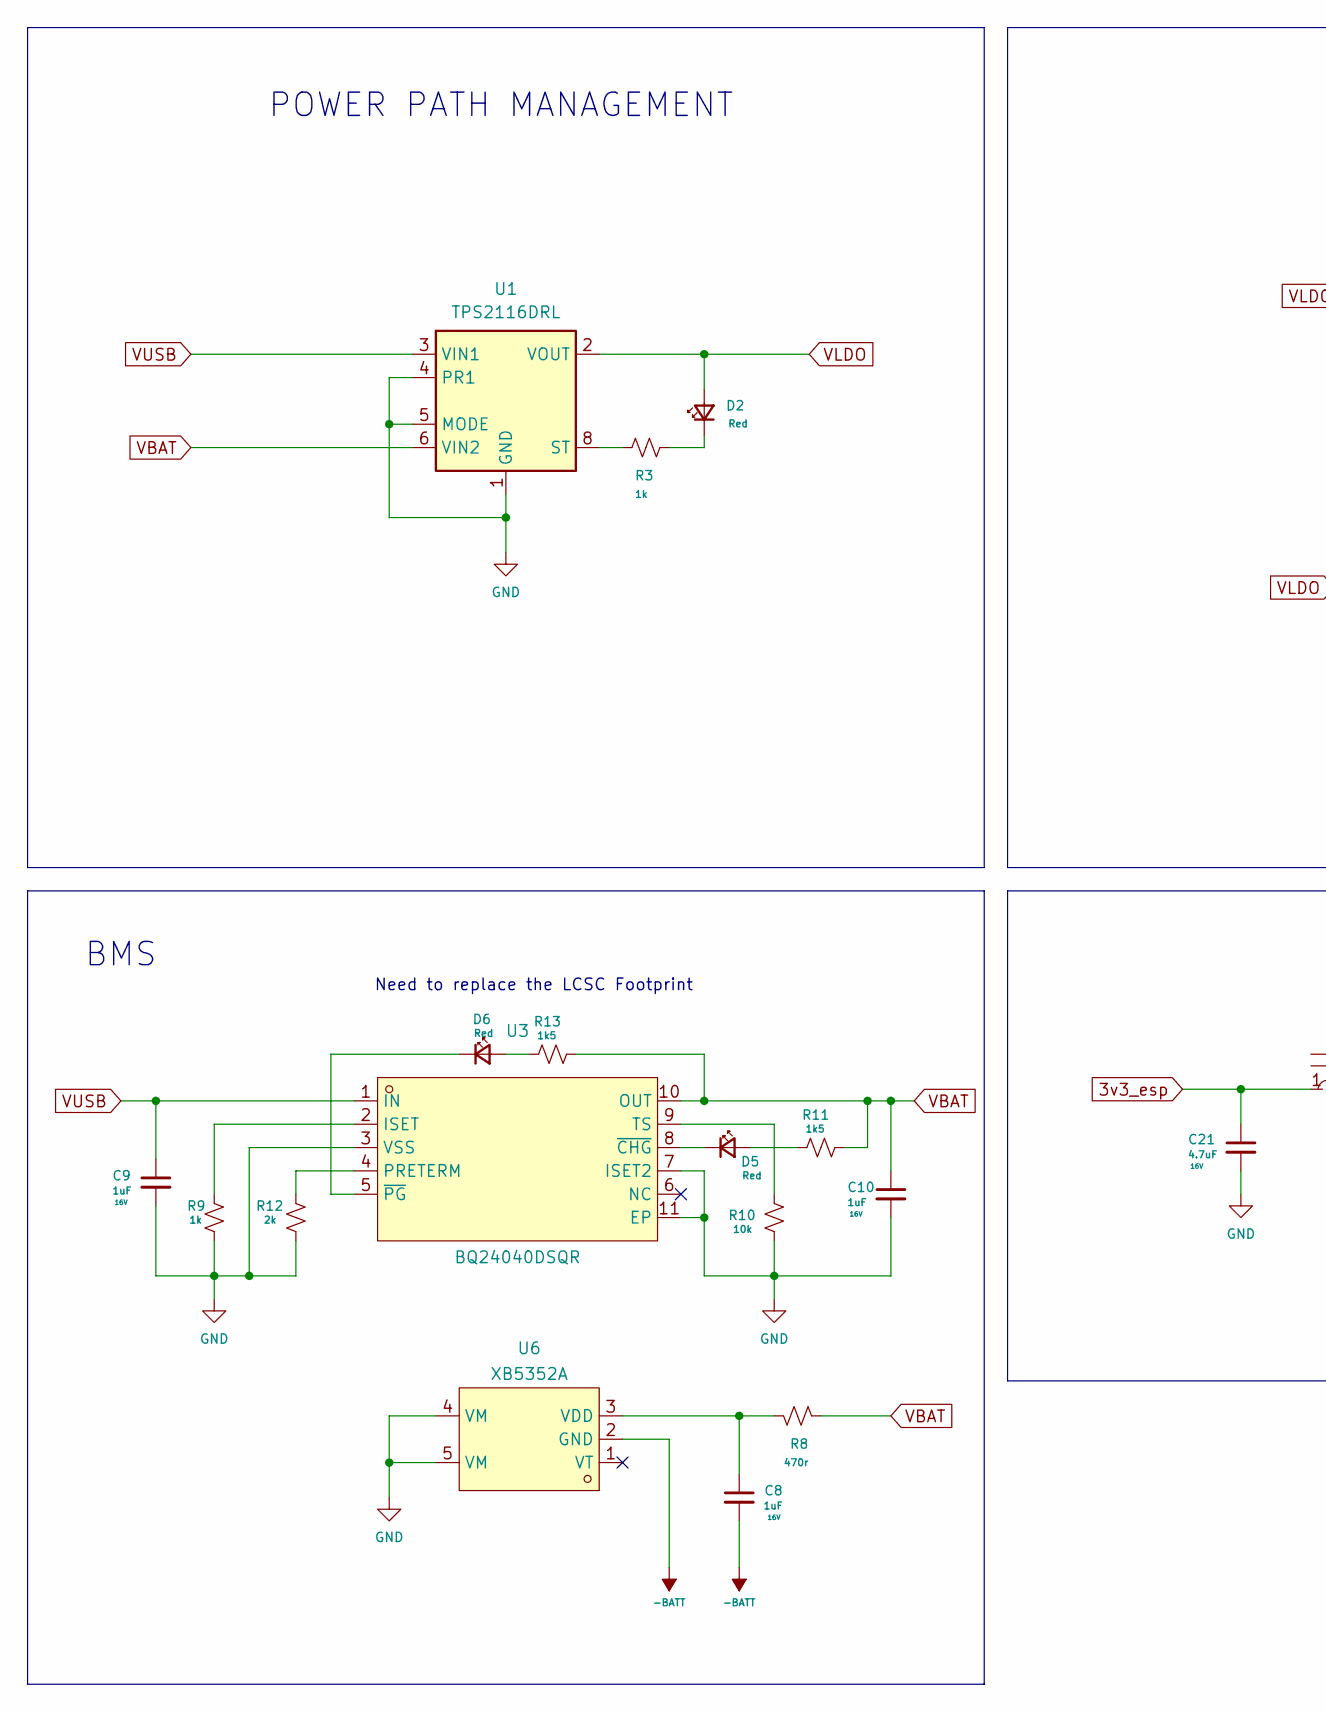
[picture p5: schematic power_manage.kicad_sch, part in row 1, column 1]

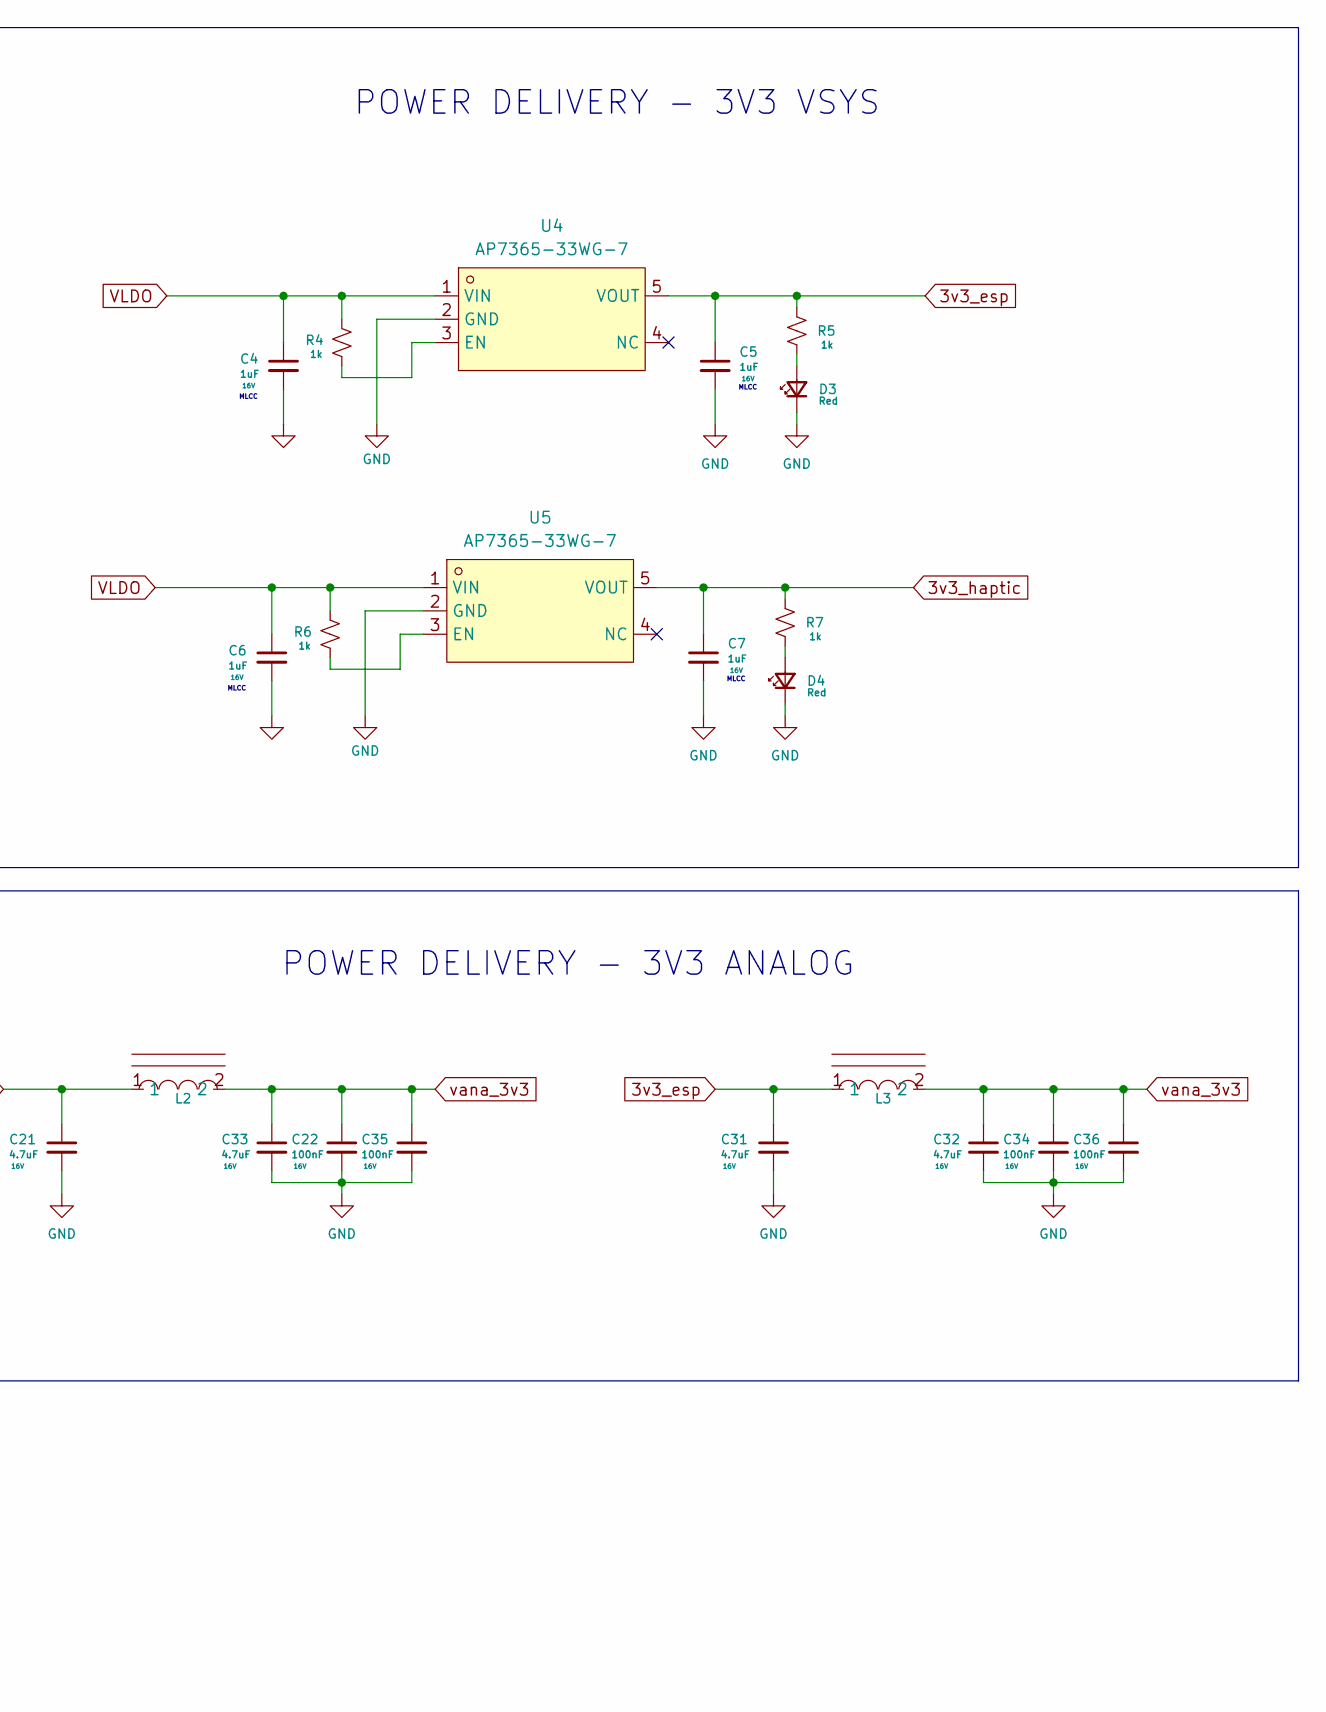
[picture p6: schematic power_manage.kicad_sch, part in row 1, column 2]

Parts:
C4, C5, C6, C7, C8, C9, C10: 1uF; C_0402_1005Metric; Voltage 16V; Tolerance 10%
C21, C31, C32, C33: 4.7uF; C_0402_1005Metric; Voltage 16V; Tolerance 10%
C22, C34, C35, C36: 100nF; C_0402_1005Metric; Voltage 16V; Tolerance 10%
D2, D3, D4, D5, D6: Red; LED_0603_1608Metric_Red
L2, L3: HCB3216KF-601T30; L1206; MPN HCB3216KF-601T30; LCSC Part C357023
R3, R4, R5, R6, R7, R9: 1k; R_0603_1608Metric
R8: 470r; R_0603_1608Metric
R10: 10k; R_0603_1608Metric
R11, R13: 1k5; R_0603_1608Metric
R12: 2k; R_0603_1608Metric
U1: TPS2116DRL; SOT-583-8
U3: BQ24040DSQR; WSON-10_L2.0-W2.0-P0.40-BL-EP; MPN BQ24040DSQR; LCSC Part C81080
U4, U5: AP7365-33WG-7; SOT-25_L3.0-W1.6-P0.95-LS2.8-BR; MPN AP7365-33WG-7; LCSC Part C150742
U6: XB5352A; SOT-23-5_L3.0-W1.7-P0.95-LS2.8-BR; MPN XB5352A; LCSC Part C154943

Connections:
3v3_esp: C5.1, C21.1, C31.1, L2.1, L3.1, R5.2, U4.5 (VOUT); also elsewhere on the board
3v3_haptic: C7.1, R7.2, U5.5 (VOUT); also elsewhere on the board
-BATT: C8.2, U6.2 (GND); also elsewhere on the board
GND: C4.2, C5.2, C6.2, C7.2, C9.2, C10.2, C21.2, C22.2, C31.2, C32.2, C33.2, C34.2, C35.2, C36.2, D3.1 (K), D4.1 (K), R9.2, R10.2, R12.1, U1.1 (GND), U1.4 (PR1), U1.5 (MODE), U3.3 (VSS), U3.7 (ISET2), U3.11 (EP), U4.2 (GND), U5.2 (GND), U6.4 (VM), U6.5 (VM); also elsewhere on the board
unnamed: D2.1 (K), R3.2
unnamed: D3.2 (A), R5.1
unnamed: D4.2 (A), R7.1
unnamed: D5.2 (A), R11.2
unnamed: D5.1 (K), U3.8 (~CHG)
unnamed: D6.2 (A), R13.2
unnamed: D6.1 (K), U3.5 (~PG)
unnamed: R3.1, U1.8 (ST)
unnamed: R9.1, U3.2 (ISET)
unnamed: R12.2, U3.4 (PRETERM)
unnamed: R10.1, U3.9 (TS)
unnamed: R4.2, U4.3 (EN)
unnamed: R6.2, U5.3 (EN)
unnamed: C8.1, R8.2, U6.3 (VDD)
VBAT: C10.1, R8.1, R11.1, R13.1, U1.6 (VIN2), U3.10 (OUT); also elsewhere on the board
VLDO: C4.1, C6.1, D2.2 (A), R4.1, R6.1, U1.2 (VOUT), U1.7 (VOUT), U4.1 (VIN), U5.1 (VIN)
VUSB: C9.1, U1.3 (VIN1), U3.1 (IN); also elsewhere on the board
vana_3v3: C22.1, C32.1, C33.1, C34.1, C35.1, C36.1, L2.2, L3.2; also elsewhere on the board

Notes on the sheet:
MLCC
POWER PATH MANAGEMENT
Need to replace the LCSC Footprint
POWER DELIVERY - 3V3 VSYS
POWER DELIVERY - 3V3 ANALOG
BMS

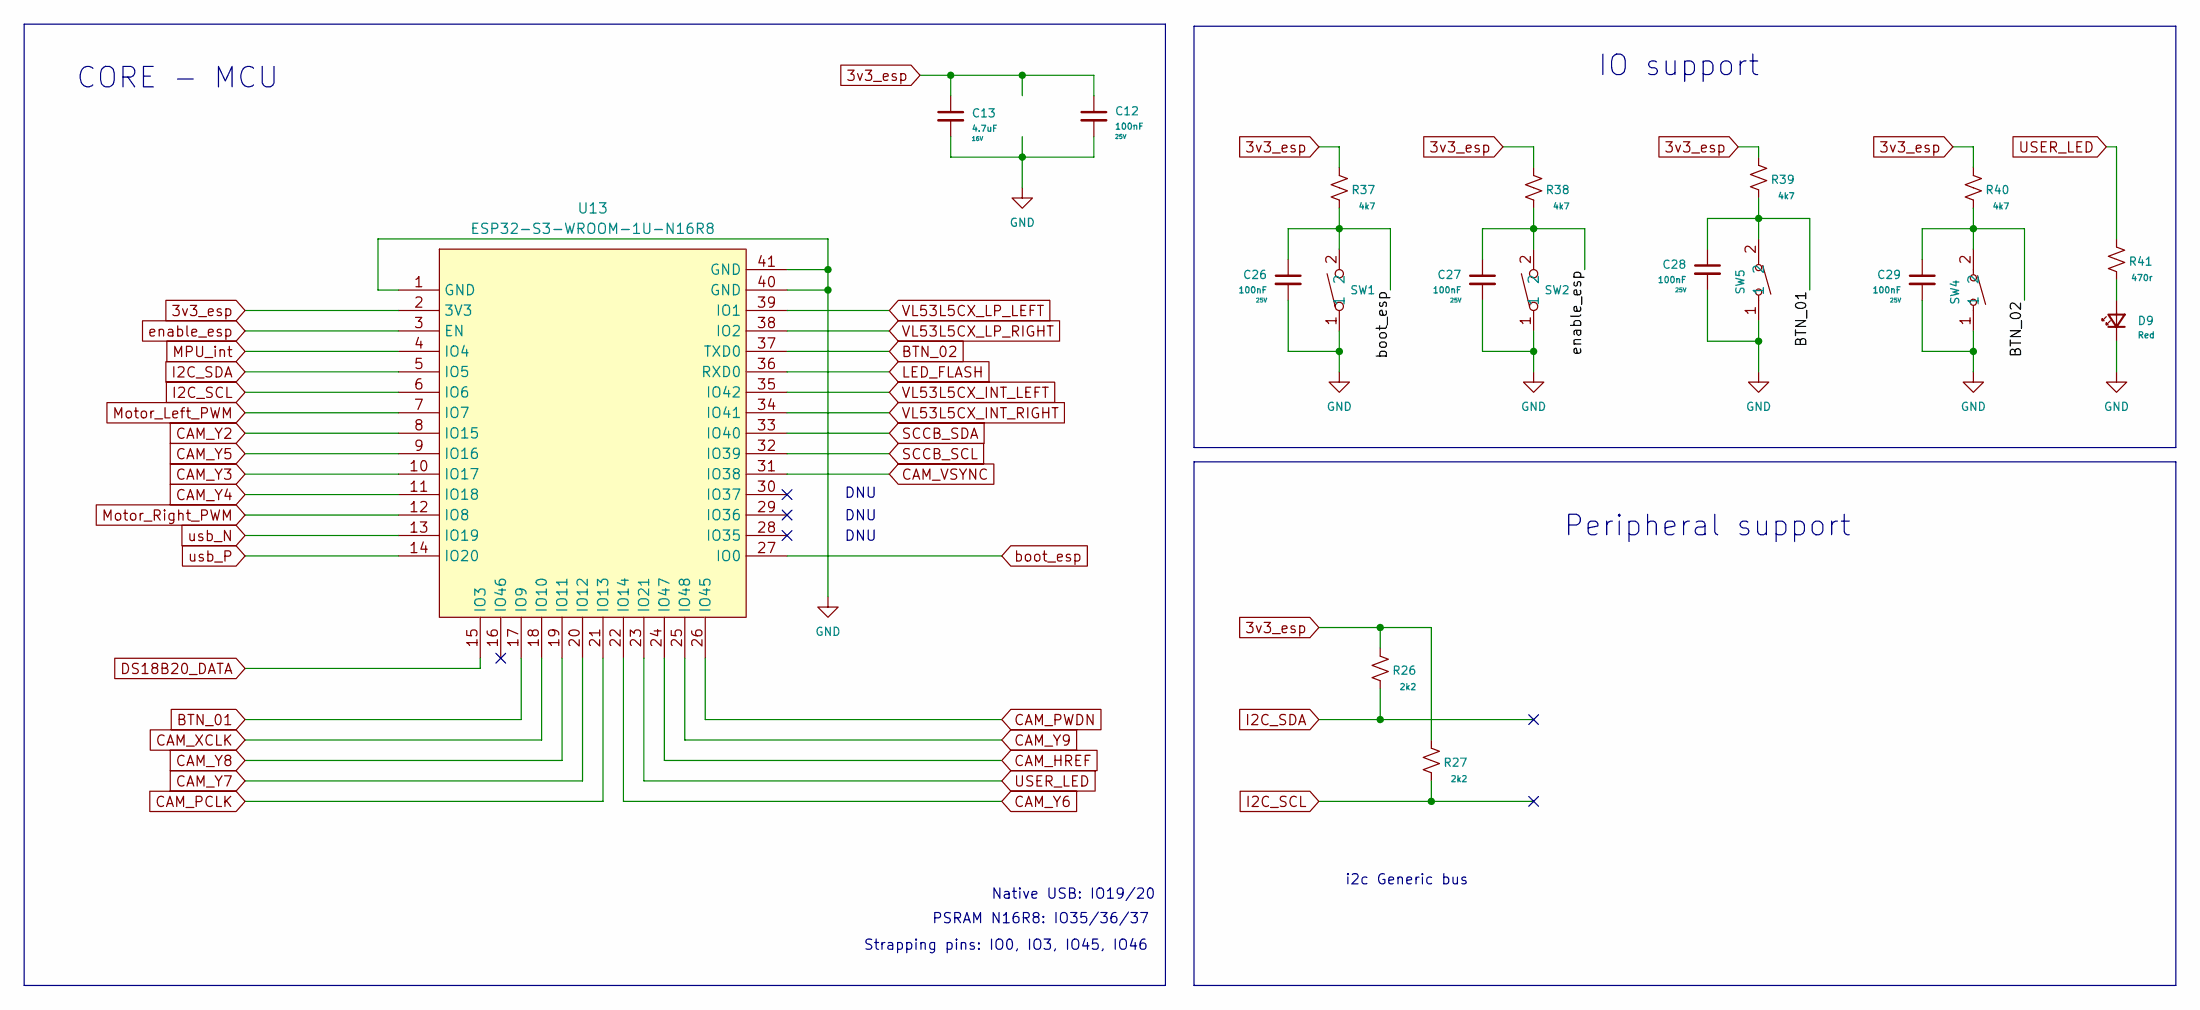
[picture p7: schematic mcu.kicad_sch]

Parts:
C12, C26, C27, C28, C29: 100nF; C_0402_1005Metric; Voltage 25V; Tolerance 10%
C13: 4.7uF; C_0402_1005Metric; Voltage 16V; Tolerance 10%
D9: Red; LED_0603_1608Metric_Red
R26, R27: 2k2; R_0603_1608Metric
R37, R38, R39, R40: 4k7; R_0603_1608Metric
R41: 470r; R_0603_1608Metric
SW1, SW2: HX 3X4X2-2P-1.6N TACTILE SWITCH; KEY-SMD_L4.0-W3.0-LS4.9-1; MPN HX 3x4x2-2P-1.6N TACTILE SWITCH; LCSC Part C49234124
SW4, SW5: TS-KG01T-ACT50F; SW-SMD_L6.0-W3.5-LS8.0-EH; MPN TS-KG01T-ACT50F; LCSC Part C2874211
U13: ESP32-S3-WROOM-1U-N16R8; WIRELM-SMD_ESP32-S3-WROOM-1U; MPN ESP32-S3-WROOM-1U-N16R8; LCSC Part C3013946

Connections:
3v3_esp: C12.1, C13.1, R26.2, R27.2, R37.2, R38.2, R39.2, R40.2, U13.2 (3V3); also elsewhere on the board
BTN_01: C28.1, R39.1, SW5.2, U13.17 (IO9)
BTN_02: C29.1, R40.1, SW4.2, U13.37 (TXD0)
CAM_HREF: U13.24 (IO47); also elsewhere on the board
CAM_PCLK: U13.21 (IO13); also elsewhere on the board
CAM_PWDN: U13.26 (IO45); also elsewhere on the board
CAM_VSYNC: U13.31 (IO38); also elsewhere on the board
CAM_XCLK: U13.18 (IO10); also elsewhere on the board
CAM_Y2: U13.8 (IO15); also elsewhere on the board
CAM_Y3: U13.10 (IO17); also elsewhere on the board
CAM_Y4: U13.11 (IO18); also elsewhere on the board
CAM_Y5: U13.9 (IO16); also elsewhere on the board
CAM_Y6: U13.22 (IO14); also elsewhere on the board
CAM_Y7: U13.20 (IO12); also elsewhere on the board
CAM_Y8: U13.19 (IO11); also elsewhere on the board
CAM_Y9: U13.25 (IO48); also elsewhere on the board
DS18B20_DATA: U13.15 (IO3); also elsewhere on the board
GND: C12.2, C13.2, C26.2, C27.2, C28.2, C29.2, D9.1 (K), SW1.1, SW2.1, SW4.1, SW5.1, U13.1 (GND), U13.40 (GND), U13.41 (GND); also elsewhere on the board
I2C_SCL: R27.1, U13.6 (IO6); also elsewhere on the board
I2C_SDA: R26.1, U13.5 (IO5); also elsewhere on the board
LED_FLASH: U13.36 (RXD0); also elsewhere on the board
MPU_int: U13.4 (IO4); also elsewhere on the board
Motor_Left_PWM: U13.7 (IO7)
Motor_Right_PWM: U13.12 (IO8); also elsewhere on the board
unnamed: D9.2 (A), R41.1
SCCB_SCL: U13.32 (IO39); also elsewhere on the board
SCCB_SDA: U13.33 (IO40); also elsewhere on the board
USER_LED: R41.2, U13.23 (IO21)
VL53L5CX_INT_LEFT: U13.35 (IO42); also elsewhere on the board
VL53L5CX_INT_RIGHT: U13.34 (IO41); also elsewhere on the board
VL53L5CX_LP_LEFT: U13.39 (IO1); also elsewhere on the board
VL53L5CX_LP_RIGHT: U13.38 (IO2); also elsewhere on the board
boot_esp: C26.1, R37.1, SW1.2, U13.27 (IO0)
enable_esp: C27.1, R38.1, SW2.2, U13.3 (EN)
usb_N: U13.13 (IO19); also elsewhere on the board
usb_P: U13.14 (IO20); also elsewhere on the board

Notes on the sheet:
i2c Generic bus
Native USB: IO19/20
DNU
IO support
PSRAM N16R8: IO35/36/37
Strapping pins: IO0, IO3, IO45, IO46
CORE - MCU
Peripheral support

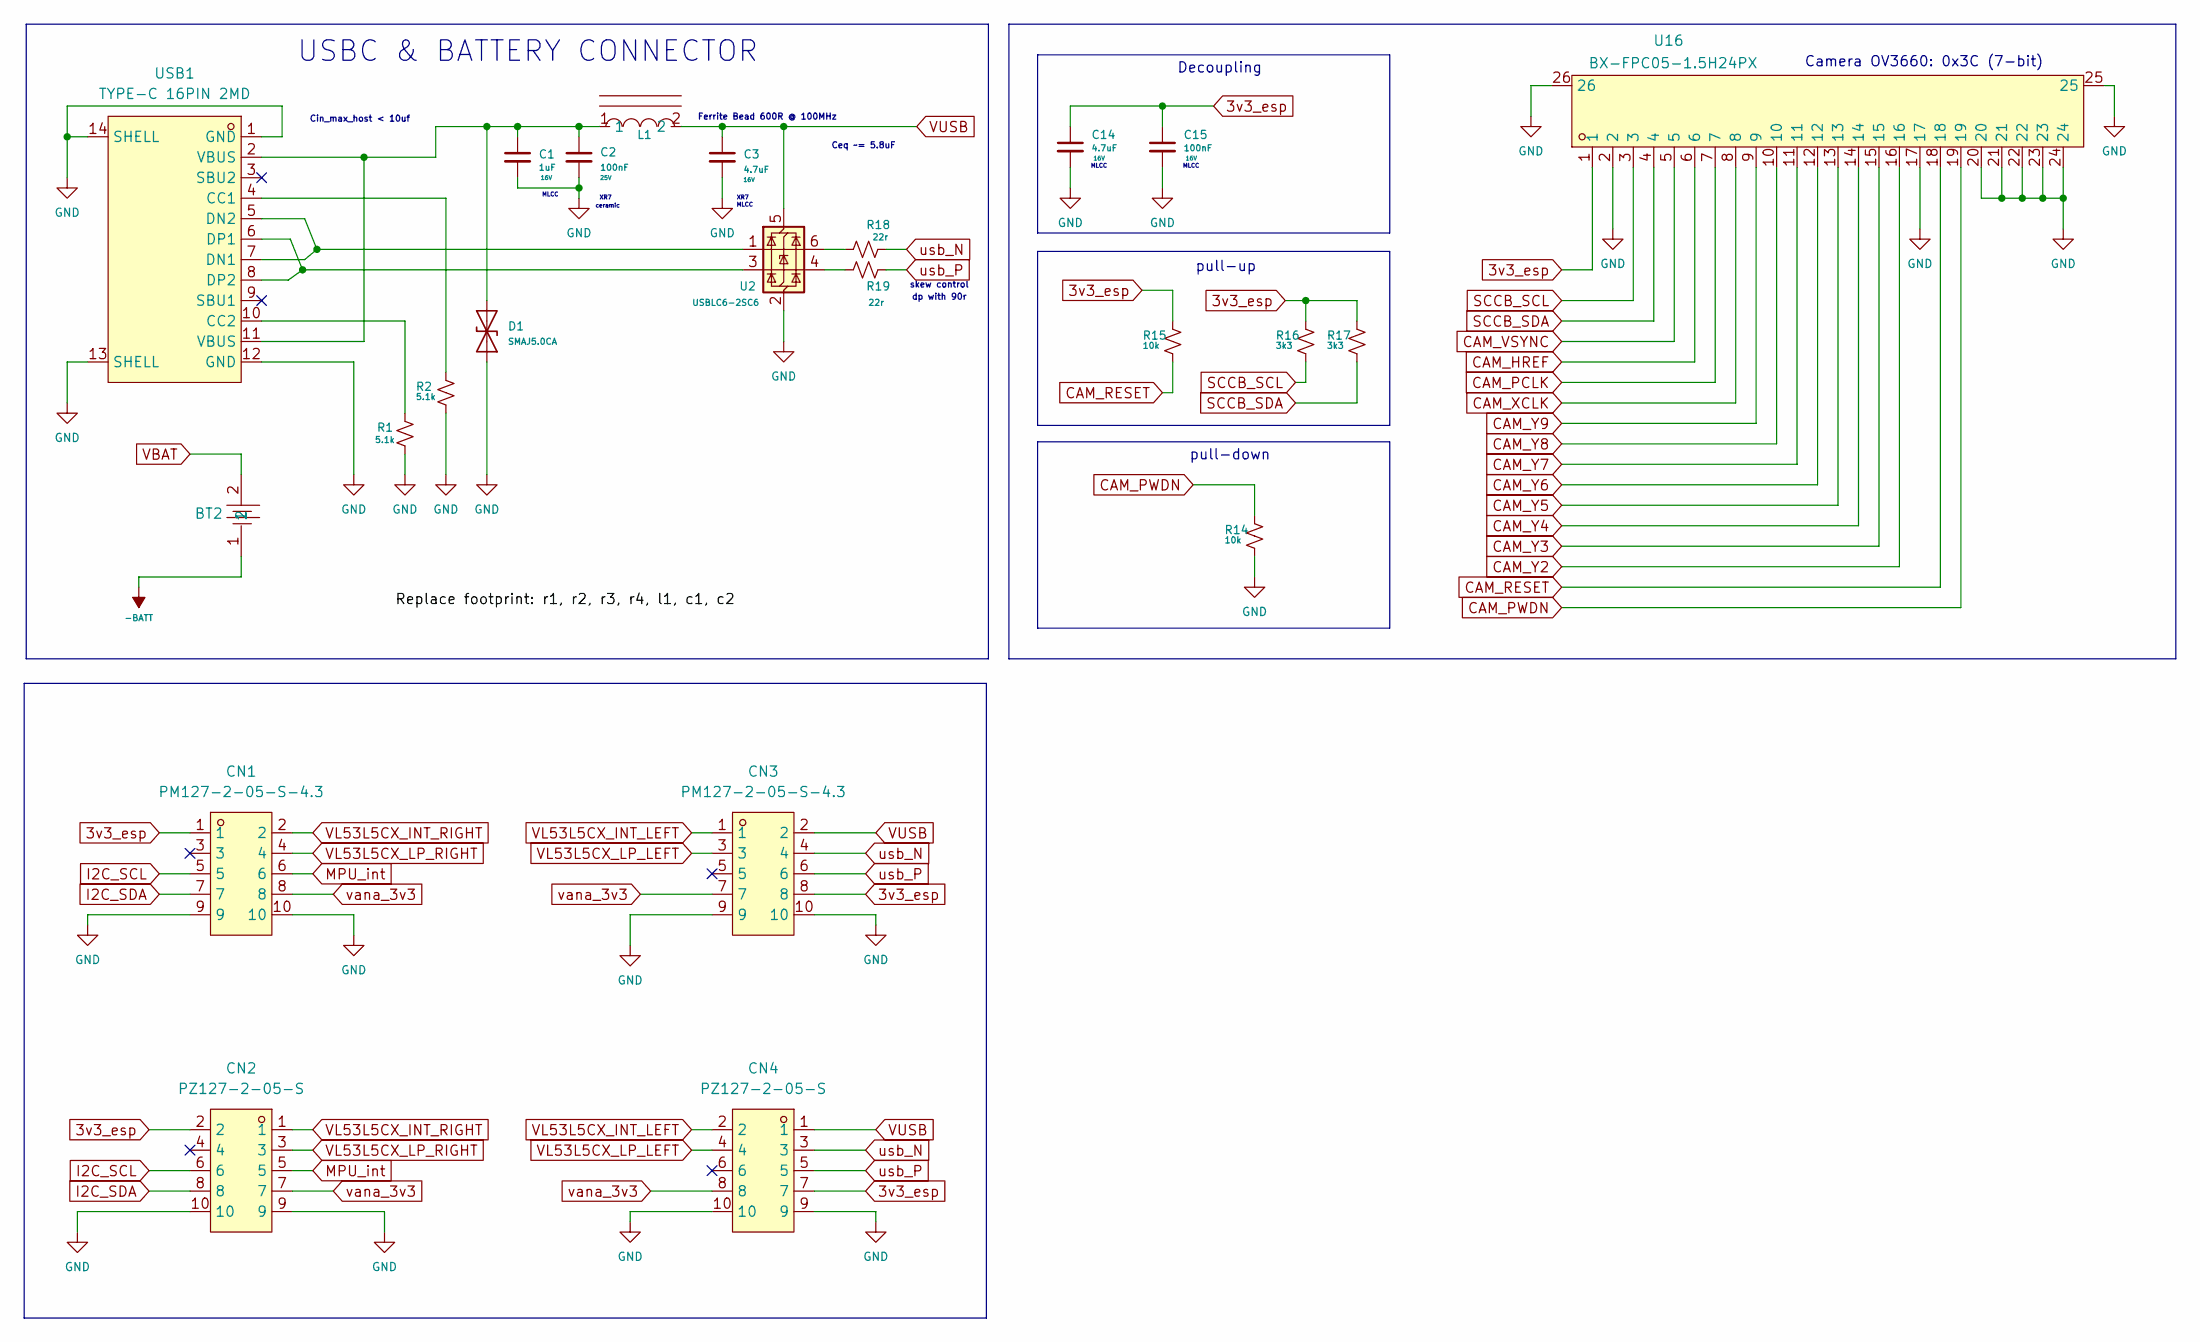
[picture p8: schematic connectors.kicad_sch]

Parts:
BT2: BH-18650-B1BA002; BATTERY-SMD_18650-1S-L77.1-W20.7-1; MPN BH-18650-B1BA002; LCSC Part C2988620
C1: 1uF; C_0402_1005Metric; Voltage 16V; Tolerance 10%
C2: 100nF; C_0402_1005Metric; Voltage 25V; Tolerance 10%
C3, C14: 4.7uF; C_0402_1005Metric; Voltage 16V; Tolerance 10%
C15: 100nF; C_0402_1005Metric; Voltage 16V; Tolerance 10%
CN1, CN3: PM127-2-05-S-4.3; HDR-SMD_10P-P1.27-V-F-R2-C5-LS4.8; MPN PM127-2-05-S-4.3; LCSC Part C3975131
CN2, CN4: PZ127-2-05-S; HDR-SMD_10P-P1.27-V-M-R2-C5-LS5.3; MPN PZ127-2-05-S; LCSC Part C3975188
D1: SMAJ5.0CA; D_SMA
L1: HCB3216KF-601T30; L1206; MPN HCB3216KF-601T30; LCSC Part C357023
R1, R2: 5.1k; R_0603_1608Metric
R14, R15: 10k; R_0603_1608Metric
R16, R17: 3k3; R_0603_1608Metric
R18, R19: 22r; R_0603_1608Metric
U2: USBLC6-2SC6; SOT-23-6
U16: BX-FPC05-1.5H24PX; FPC-SMD_24P-P0.50_BX-FPC05-1.5H24PX; MPN BX-FPC05-1.5H24PX; LCSC Part C18078354
USB1: TYPE-C 16PIN 2MD; USB-C-SMD_TYPE-C-6PIN-2MD-073; MPN TYPE-C 16PIN 2MD(073); LCSC Part C2765186

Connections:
3v3_esp: C14.1, C15.1, CN1.1, CN2.2, CN3.8, CN4.7, R15.1, R16.1, R17.1, U16.1; also elsewhere on the board
-BATT: BT2.1; also elsewhere on the board
CAM_HREF: U16.6; also elsewhere on the board
CAM_PCLK: U16.7; also elsewhere on the board
CAM_PWDN: R14.1, U16.19; also elsewhere on the board
CAM_RESET: R15.2, U16.18
CAM_VSYNC: U16.5; also elsewhere on the board
CAM_XCLK: U16.8; also elsewhere on the board
CAM_Y2: U16.16; also elsewhere on the board
CAM_Y3: U16.15; also elsewhere on the board
CAM_Y4: U16.14; also elsewhere on the board
CAM_Y5: U16.13; also elsewhere on the board
CAM_Y6: U16.12; also elsewhere on the board
CAM_Y7: U16.11; also elsewhere on the board
CAM_Y8: U16.10; also elsewhere on the board
CAM_Y9: U16.9; also elsewhere on the board
GND: C1.2, C2.2, C3.2, C14.2, C15.2, CN1.9, CN1.10, CN2.9, CN2.10, CN3.9, CN3.10, CN4.9, CN4.10, D1.1 (A1), R1.2, R2.2, R14.2, U2.2 (GND), U16.2, U16.17, U16.20, U16.21, U16.22, U16.23, U16.24, U16.25, U16.26, USB1.1 (GND), USB1.12 (GND), USB1.13 (SHELL), USB1.14 (SHELL); also elsewhere on the board
I2C_SCL: CN1.5, CN2.6; also elsewhere on the board
I2C_SDA: CN1.7, CN2.8; also elsewhere on the board
MPU_int: CN1.6, CN2.5; also elsewhere on the board
unnamed: C1.1, C2.1, D1.2 (A2), L1.1, USB1.2 (VBUS), USB1.11 (VBUS)
unnamed: R18.1, U2.6 (I/O1)
unnamed: R19.1, U2.4 (I/O2)
unnamed: R2.1, USB1.4 (CC1)
unnamed: R1.1, USB1.10 (CC2)
unnamed: U2.1 (I/O1), USB1.5 (DN2), USB1.7 (DN1)
unnamed: U2.3 (I/O2), USB1.6 (DP1), USB1.8 (DP2)
SCCB_SCL: R16.2, U16.3; also elsewhere on the board
SCCB_SDA: R17.2, U16.4; also elsewhere on the board
VBAT: BT2.2; also elsewhere on the board
VL53L5CX_INT_LEFT: CN3.1, CN4.2; also elsewhere on the board
VL53L5CX_INT_RIGHT: CN1.2, CN2.1; also elsewhere on the board
VL53L5CX_LP_LEFT: CN3.3, CN4.4; also elsewhere on the board
VL53L5CX_LP_RIGHT: CN1.4, CN2.3; also elsewhere on the board
VUSB: C3.1, CN3.2, CN4.1, L1.2, U2.5 (VBUS); also elsewhere on the board
usb_N: CN3.4, CN4.3, R18.2; also elsewhere on the board
usb_P: CN3.6, CN4.5, R19.2; also elsewhere on the board
vana_3v3: CN1.8, CN2.7, CN3.7, CN4.8; also elsewhere on the board

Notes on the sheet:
pull-up
ceramic
Cin_max_host < 10uf
Ferrite Bead 600R @ 100MHz
skew control
XR7
Camera OV3660: 0x3C (7-bit)
Ceq ~= 5.8uF
USBC & BATTERY CONNECTOR
pull-down
MLCC
dp with 90r
Decoupling

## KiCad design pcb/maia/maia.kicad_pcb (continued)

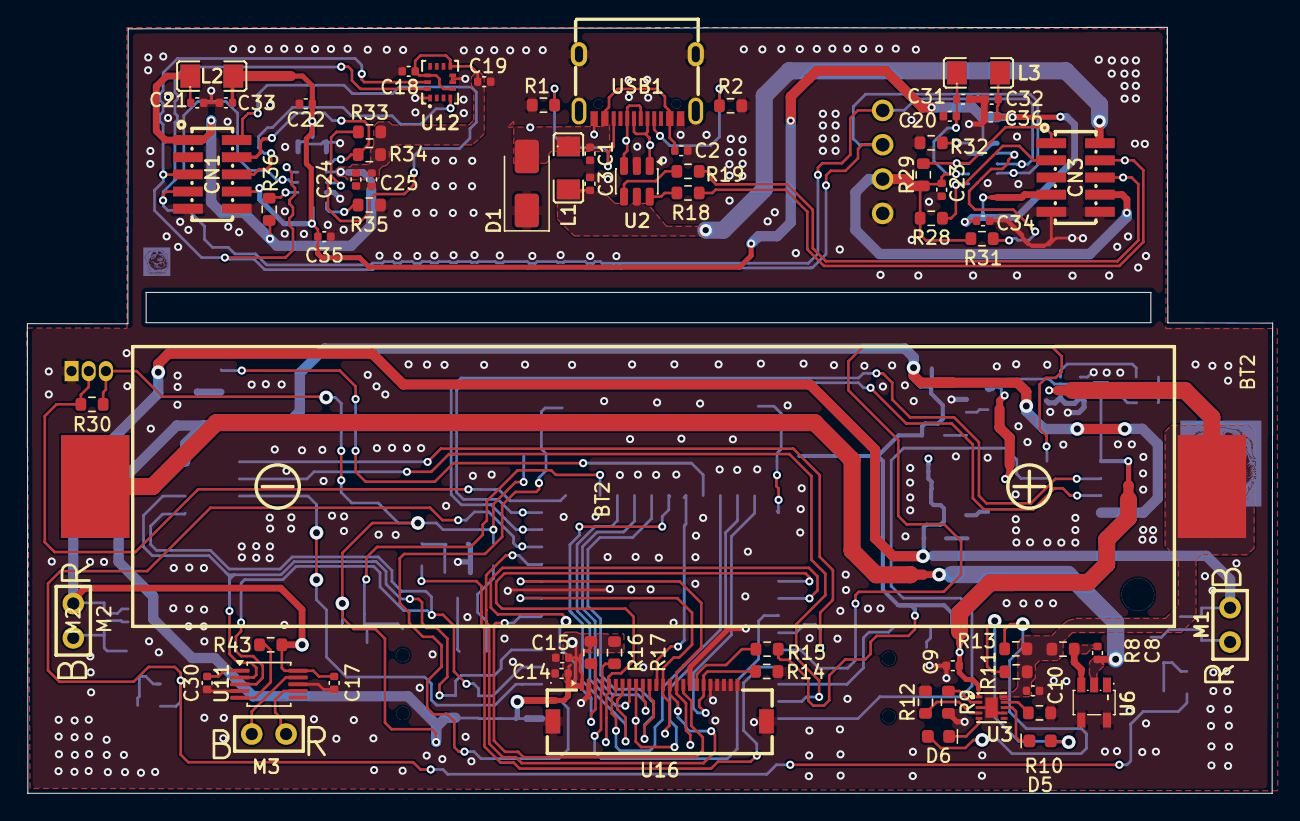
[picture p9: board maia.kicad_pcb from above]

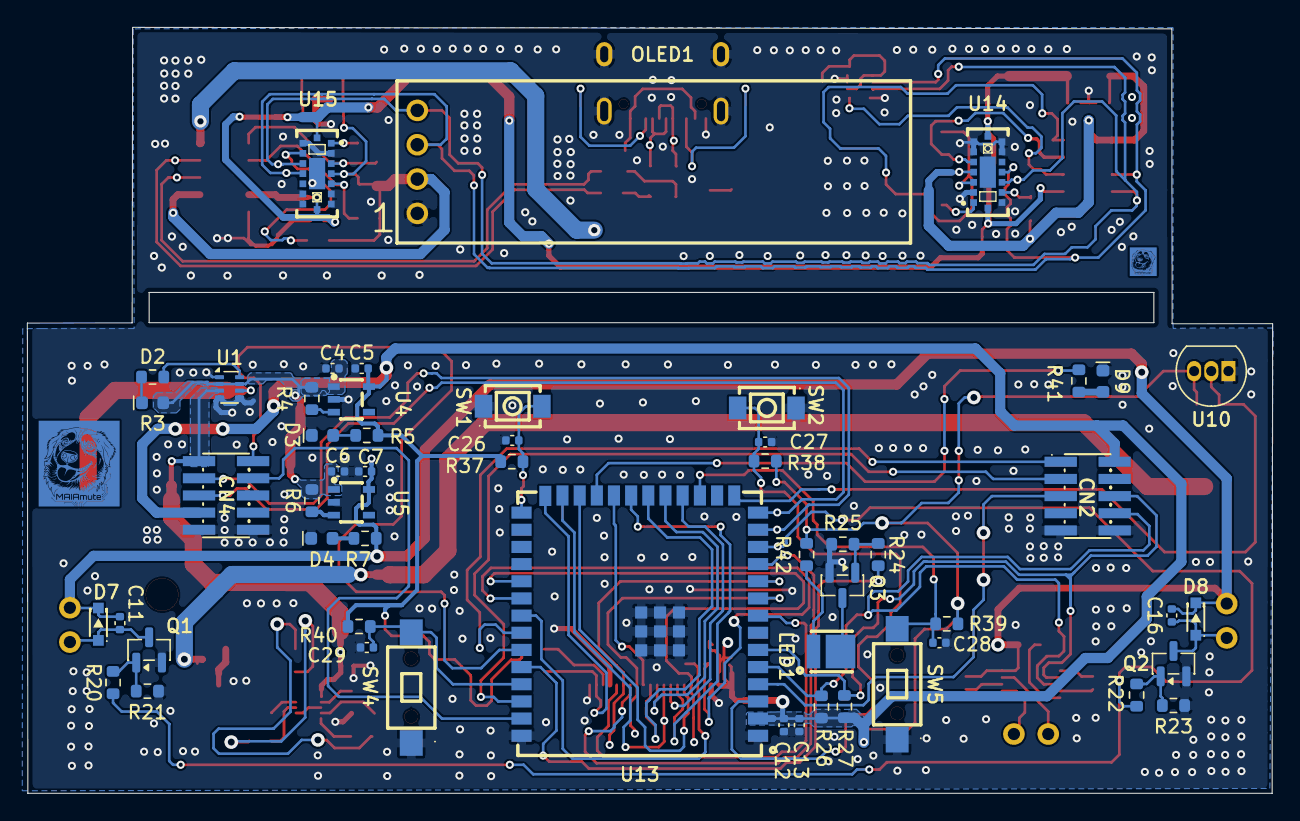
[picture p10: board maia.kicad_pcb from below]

Board: 4 copper layers, 92.1 x 56.7 mm, 122 parts (55 on the bottom side), 78 nets.

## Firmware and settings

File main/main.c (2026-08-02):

/*
 * Copyright 2026 Vinicius May
 *
 * Licensed under the Apache License, Version 2.0 (the "License");
 * you may not use this file except in compliance with the License.
 * You may obtain a copy of the License at
 *
 *     http://www.apache.org/licenses/LICENSE-2.0
 *
 * Unless required by applicable law or agreed to in writing, software
 * distributed under the License is distributed on an "AS IS" BASIS,
 * WITHOUT WARRANTIES OR CONDITIONS OF ANY KIND, either express or implied.
 * See the License for the specific language governing permissions and
 * limitations under the License.
 */

/****************************************************************************
 * main/main.c
 *
 * MAIA - Motion Assistance for Impaired Animals
 * Application entry point
 *
 ****************************************************************************/

/****************************************************************************
 * Included Files
 ****************************************************************************/

#include <esp_log.h>
#include "maia_board.h"

#ifdef CONFIG_MAIA_TEST_ENABLE
#  include "tests/tests.h"
#else
#  include "app.h"
#endif

/****************************************************************************
 * Pre-processor Definitions
 ****************************************************************************/

#define TAG "[MAIN]"

/****************************************************************************
 * Public Functions
 ****************************************************************************/

/****************************************************************************
 * Name: app_main
 *
 * Description:
 *   Application entry point.
 *
 ****************************************************************************/

void app_main(void)
{
#ifdef CONFIG_MAIA_TEST_ENABLE

  /* Test mode enabled */

  ESP_LOGI(TAG, "=== MAIA MODE: TEST MODE ===");
  maia_board_init();

#ifdef CONFIG_MAIA_TEST_BLINK
  test_blink_run();
#elif defined(CONFIG_MAIA_TEST_BUTTON)
  test_button_run();
#elif defined(CONFIG_MAIA_TEST_TEMPERATURE_SENSOR)
  test_ds18b20_run();
#elif defined(CONFIG_MAIA_TEST_HAPTIC_MOTOR)
  test_drv2605l_run();
#elif defined(CONFIG_MAIA_TEST_DISPLAY)
  test_ssd1306_run();
#elif defined(CONFIG_MAIA_TEST_IMU)
  test_mpu6050_run();
#elif defined(CONFIG_MAIA_TEST_TOF)
  test_vl53l5cx_run();
#elif defined(CONFIG_MAIA_TEST_WIFI)
  test_wifi_run();
#elif defined(CONFIG_MAIA_TEST_LIDAR_VIEWER)
  test_lidar_viewer_run();
#endif

#else

  /* Normal application mode */

  ESP_LOGI(TAG, "=== MAIA MODE: REAL APPLICATION ===");
  maia_board_init();
  app_init();

#endif
}

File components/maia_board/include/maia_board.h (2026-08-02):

    /*
    * Copyright 2026 Vinicius May
    *
    * Licensed under the Apache License, Version 2.0 (the "License");
    * you may not use this file except in compliance with the License.
    * You may obtain a copy of the License at
    *
    *     http://www.apache.org/licenses/LICENSE-2.0
    *
    * Unless required by applicable law or agreed to in writing, software
    * distributed under the License is distributed on an "AS IS" BASIS,
    * WITHOUT WARRANTIES OR CONDITIONS OF ANY KIND, either express or implied.
    * See the License for the specific language governing permissions and
    * limitations under the License.
    */

    /****************************************************************************
     * components/maia_board/include/maia_board.h
     *
     * MAIA - Motion Assistance for Impaired Animals
     *
     ****************************************************************************/

    #ifndef __COMPONENTS_MAIA_BOARD_INCLUDE_MAIA_BOARD_H
    #define __COMPONENTS_MAIA_BOARD_INCLUDE_MAIA_BOARD_H

    /****************************************************************************
     * Included Files
     ****************************************************************************/

    #include <esp_err.h>
    #include <driver/gpio.h>
    #include <driver/i2c_master.h>
    #include <driver/ledc.h>

    /****************************************************************************
     * Pre-processor Definitions
     ****************************************************************************/

    /* GPIO Pin Definitions (MAIA rev0 - ESP32-S3-WROOM-1U-N16R8)
    *
    *  ------------------------------------------------------------------
    * | Mod pin |  GPIO  | Net                | Function                 |
    *  ---------|--------|--------------------|--------------------------|
    *      1    |   -    | GND                |
    *      2    |   -    | 3v3_esp            | 3V3 supply
    *      3    |   -    | enable_esp         | EN / reset
    *      4    | GPIO04 | MPU_int            | IMU interrupt
    *      5    | GPIO05 | I2C_SDA            | I2C bus SDA
    *      6    | GPIO06 | I2C_SCL            | I2C bus SCL
    *      7    | GPIO07 | Motor_Left_PWM     | Left ERM motor PWM
    *      8    | GPIO15 | CAM_Y2             | Camera data
    *      9    | GPIO16 | CAM_Y5             | Camera data
    *     10    | GPIO17 | CAM_Y3             | Camera data
    *     11    | GPIO18 | CAM_Y4             | Camera data
    *     12    | GPIO08 | Motor_Right_PWM    | Right ERM motor PWM
    *     13    | GPIO19 | usb_N              | Native USB D-
    *     14    | GPIO20 | usb_P              | Native USB D+
    *     15    | GPIO03 | DS18B20_DATA       | OneWire data
    *     16    | GPIO46 | -                  | Not connected (DNU)
    *     17    | GPIO09 | BTN_01             | Button 1
    *     18    | GPIO10 | CAM_XCLK           | Camera clock in
    *     19    | GPIO11 | CAM_Y8             | Camera data
    *     20    | GPIO12 | CAM_Y7             | Camera data
    *     21    | GPIO13 | CAM_PCLK           | Camera pixel clock
    *     22    | GPIO14 | CAM_PWDN           | Camera power down
    *     23    | GPIO21 | CAM_Y9             | Camera data
    *     24    | GPIO47 | CAM_HREF           | Camera HREF
    *     25    | GPIO48 | USER_LED           | User / status LED
    *     26    | GPIO45 | CAM_Y6             | Camera data
    *     27    | GPIO00 | boot_esp           | Boot strapping pin
    *     28    | GPIO35 | -                  | Not connected (DNU)
    *     29    | GPIO36 | -                  | Not connected (DNU)
    *     30    | GPIO37 | -                  | Not connected (DNU)
    *     31    | GPIO38 | CAM_VSYNC          | Camera VSYNC
    *     32    | GPIO39 | SCCB_SCL           | Camera SCCB clock
    *     33    | GPIO40 | SCCB_SDA           | Camera SCCB data
    *     34    | GPIO41 | VL53L5CX_INT_RIGHT | ToF right INT
    *     35    | GPIO42 | VL53L5CX_INT_LEFT  | ToF left INT
    *     36    | GPIO44 | LED_FLASH          | Camera flash LED  (U0RXD)
    *     37    | GPIO43 | BTN_02             | Button 2          (U0TXD)
    *     38    | GPIO02 | VL53L5CX_LP_RIGHT  | ToF right LPn
    *     39    | GPIO01 | VL53L5CX_LP_LEFT   | ToF left LPn
    *     40    |   -    | GND                |
    *     41    |   -    | GND                |
    *  ------------------------------------------------------------------
    *
    * NOTE: GPIO43/GPIO44 are the ROM/UART0 console pins (U0TXD/U0RXD).
    *       They are only free for general purpose use while the IDF
    *       console is routed to the USB Serial/JTAG controller
    *       (CONFIG_ESP_CONSOLE_USB_SERIAL_JTAG). The first stage ROM
    *       bootloader still drives U0TXD briefly on every reset.
    */

    /* ToF Sensor Pins (VL53L5CX) - TOF1 = LEFT, TOF2 = RIGHT */
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

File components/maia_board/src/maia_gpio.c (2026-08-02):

/*
 * Copyright 2026 Vinicius May
 *
 * Licensed under the Apache License, Version 2.0 (the "License");
 * you may not use this file except in compliance with the License.
 * You may obtain a copy of the License at
 *
 *     http://www.apache.org/licenses/LICENSE-2.0
 *
 * Unless required by applicable law or agreed to in writing, software
 * distributed under the License is distributed on an "AS IS" BASIS,
 * WITHOUT WARRANTIES OR CONDITIONS OF ANY KIND, either express or implied.
 * See the License for the specific language governing permissions and
 * limitations under the License.
 */

/****************************************************************************
 * components/maia_board/src/maia_gpio.c
 *
 * MAIA - Motion Assistance for Impaired Animals
 * GPIO initialization for interrupts, button, and ToF control pins
 *
 ****************************************************************************/

/****************************************************************************
 * Included Files
 ****************************************************************************/

#include "maia_board.h"
#include <driver/gpio.h>
#include <esp_log.h>

/****************************************************************************
 * Pre-processor Definitions
 ****************************************************************************/

#define TAG "[MAIA_GPIO]"

/****************************************************************************
 * Public Functions
 ****************************************************************************/

/****************************************************************************
 * Name: maia_gpio_init
 *
 * Description:
 *   Initialize GPIO pins:
 *   - IMU (accel) INT pin  (input, internal pull-up)
 *   - ToF LPn pins (output, active low enable)
 *   - ToF INT pins (input, internal pull-up)
 *   - Button  pin  (input, external pull-up)
 *   - Status LED   (output)
 *
 * Input Parameters:
 *   None
 *
 * Returned Value:
 *   ESP_OK on success; ESP_FAIL on failure.
 *
 ****************************************************************************/

esp_err_t maia_gpio_init(void)
{
  esp_err_t ret;
  gpio_config_t io_conf;

  ESP_LOGI(TAG, "Initializing GPIO pins");

  /*
   * LIDAR: LOW_POWER_ENABLE_PIN
   * * * * * * * * * * * * * * * */

#ifdef CONFIG_MAIA_VL53L5CX_ENABLE
   /*
    Bit 0  = GPIO00
    Bit 1  = GPIO01
    Bit 2  = GPIO02
    ...
    Bit 43 = GPIO43
   
    0000 0000 0000 0000 0000 0000 0000 0010
                                         ^
                                     GPIO1 ---> MAIA_GPIO_TOF1_LPN

    0000 0000 0000 0000 0000 0000 0000 0100
                                        ^
                                     GPIO2 ---> MAIA_GPIO_TOF2_LPN

    We have to set both GPIO as 1
  */

  io_conf.pin_bit_mask = (1ULL << MAIA_GPIO_TOF1_LPN) |
                         (1ULL << MAIA_GPIO_TOF2_LPN);

  io_conf.intr_type = GPIO_INTR_DISABLE;           /* disabling interrupt    */
  io_conf.mode = GPIO_MODE_INPUT_OUTPUT;           /* output + readback      */
  io_conf.pull_down_en = GPIO_PULLDOWN_DISABLE;    /* we have external 47k   */
  io_conf.pull_up_en = GPIO_PULLUP_DISABLE;        /* ensure no conlicts     */

  ret = gpio_config(&io_conf);
  if (ret != ESP_OK)
    {
      ESP_LOGE(TAG, "Failed to configure ToF LPn pins");
      return ret;
    }

  /* LPn is active high enable: HIGH = sensor on, LOW = standby.
   * Both sensors power up at the same default address (0x52), so they
   * must stay in standby until vl53l5cx_init() enables them one at a
   * time to reassign the addresses.
   */

  gpio_set_level(MAIA_GPIO_TOF1_LPN, 0);      /* Lidar 1 (left)  in standby */
  gpio_set_level(MAIA_GPIO_TOF2_LPN, 0);      /* Lidar 2 (right) in standby */

  /*
   * LIDAR: INTERRUPT_PIN
   * * * * * * * * * * * * * * * */
  
   /* 
     Input with internal pull-up
     INT is active low, open-drain output from sensor
   */

  io_conf.pin_bit_mask = (1ULL << MAIA_GPIO_TOF1_INT) |
                         (1ULL << MAIA_GPIO_TOF2_INT);

  io_conf.intr_type = GPIO_INTR_NEGEDGE;           /* trigger on fall        */
  io_conf.mode = GPIO_MODE_INPUT;                  /* set as input           */
  io_conf.pull_down_en = GPIO_PULLDOWN_DISABLE;    /* disable pulldown       */
  io_conf.pull_up_en = GPIO_PULLUP_ENABLE;         /* enable internal pullup */

  ret = gpio_config(&io_conf);
  if (ret != ESP_OK)
    {
      ESP_LOGE(TAG, "Failed to configure ToF INT pins");
      return ret;
    }
#endif

  /*
   * Accelerometer: Interrupt_PIN
   * * * * * * * * * * * * * * * */

  /* Shared by all supported IMUs (see Kconfig choice MAIA_IMU_DEVICE),
   * they all route their INT line to MAIA_GPIO_IMU_INT. The interrupt
   * itself stays disabled here; the driver enables it when ready.
   */
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

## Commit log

2026-01-10 feat(maia_board): add comprehensive Kconfig and LED support
    - Created complete Kconfig menu structure with 46 configuration symbols
    - Added General Configuration (timeouts, software version, animal/tutor info)
    - Added Radio Configuration (WiFi AP/STA modes, button triggers)
    - Added GPIO Configuration (PWM motors, button, LED status)
    - Added Bus Configuration (I2C frequency, device enables/addresses)
    - Implemented maia_config.c for startup configuration logging
    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
2026-01-11 feat(button): implement complete button driver with state machine
    - Add button driver with debouncing and event detection
    - Support 7 event types: PRESSED, RELEASED, SINGLE_CLICK, DOUBLE_CLICK,
    LONG_PRESS, EXTRA_LONG_PRESS_1, EXTRA_LONG_PRESS_2
    - Implement cascading ESP timers for efficient threshold detection
    - Add Kconfig menu for all timing parameters
    - Create test framework with LED feedback
    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
2026-01-11 feat(drivers): implement DS18B20 OneWire temperature sensor driver
    - Add complete OneWire protocol implementation in maia_onewire.c
    * Reset pulse detection with presence check
    * Bit-level read/write operations (LSB first)
    * Byte-level read/write operations
    * Dallas/Maxim CRC8 checksum calculation
    * Precise timing using esp_rom_delay_us()
    - Implement DS18B20 driver with async and blocking modes
    * Configurable resolution (9/10/11/12-bit) via Kconfig
    * Configurable temperature unit (Celsius/Fahrenheit/Kelvin)
    * Skip ROM mode for single sensor (Match ROM prepared for future)
    * Non-blocking trigger_conversion() for concurrent operations
    * Direct scratchpad access for debuggin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
    [maia_board.c, maia_board.h, maia_led.c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]
2026-01-18 driver drv2605l was implemented with test functions
2026-03-22 feat(mpu6050): add MPU-6050 IMU driver and test suite
    - New driver: components/drivers/mpu6050/ (init, raw/scaled reads,
    calibration, self-test, sleep/wake, range config, DMP skeleton)
    - New test: main/tests/test_mpu6050.c (8 Phase 1 tests, all PASS)
    - Fix: memset i2c_device_config_t before add_device — ESP-IDF v6.0
    internal fields (flags, scl_wait_us) must be zero, stack garbage
    caused ESP_ERR_INVALID_STATE on first transmit
    - BSP: added MPU6050 I2C addr and IMU INT GPIO to Kconfig/maia_board
    - DMP firmware placeholder only (not needed for motion detection)
    [maia_board.h, maia_gpio.c, main.c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]
2026-04-06 feat: add VL53L5CX driver skeleton and platform layer
2026-04-06 feat(vl53l5cx): add ToF driver v0.6.0 with platform layer, Kconfig and tests
    - Add platform.h: MAIA VL53L5CX_Platform with ESP-IDF v6.0 I2C master API
    - Add vl53l5cx_platform.c: WrByte/WrMulti/RdByte/RdMulti/WaitMs/SwapBuffer
    - Add vl53l5cx.c/h: dual sensor driver with LPn address reassignment
    - Add test_vl53l5cx.c: Phase 1 test suite (8 tests)
    - Update Kconfig: 9 new VL53L5CX params + MAIA_TEST_TOF
    - Update drivers/CMakeLists.txt: include ULD sources from managed_components
    - Update maia_board.h: TOF INT pins GPIO43/44 -> GPIO40/41 (avoid UART conflict)
    - Update .gitignore: allow managed_components/stm32-vl53l5cx/CMakeLists.txt stub
    - Update README.md: document ST ULD dependency and build i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
    [main.c, test_vl53l5cx.c, vl53l5cx.c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]
2026-06-19 It was add the pcb rev0 and the spec/doc rev5
    [block_diagram.kicad_sch, connectors.kicad_sch, export_cart_20260615_043156.csv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]
2026-07-31 fix(vl53l5cx): correct I2C addressing and sensor bring-up
    AI-assisted debugging and fix.
    The driver never completed init: every transaction to the sensor
    failed with ESP_ERR_INVALID_STATE. Root cause was an address
    convention mismatch — ST's ULD uses 8-bit wire addresses (0x52),
    but i2c_master_bus_add_device() with I2C_ADDR_BIT_LEN_7 expects
    the 7-bit value, so the driver addressed a device that wasn't
    there. Verified end-to-end on the MAIA board and on an external
    ST SATEL module: 8/8 tests pass with live ranging data.
    - Shift boot/target addresses to 7-bit in register_sensor()
    - Drop redundant << 1 in the vl53l5cx_set_i2c_address() call
    - Treat the address-reassign status as advisory: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
    [maia_gpio.c, test_vl53l5cx.c, vl53l5cx.c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]
2026-07-31 fix(vl53l5cx): wire up min-signal-per-SPAD Kconfig and show distances in meters
    - Apply the previously-unused MIN_SIGNAL_PER_SPAD Kconfig threshold
    in filter_data() to reject low-confidence zones
    - Format live distance readings as meters (mm below 10cm) in the
    ToF test's distance stream and OLED matrix view
    [test_vl53l5cx.c, vl53l5cx.c]
2026-08-02 feat(lsm6dsox): scaffold driver and prepare the board layer for it
    Groundwork before implementing the LSM6DSOX. The driver brings up the
    bus and reads accel/gyro/temp; every optional feature is a documented
    stub. Alongside it, the board layer was corrected to match the rev0
    hardware.
    maia_board.h
    - Replace the XIAO ESP32S3 Plus pinout with the MAIA rev0 map
    (ESP32-S3-WROOM-1U-N16R8), all 41 module pins with net names
    - Fix ToF interrupt pins: GPIO43/44 -> GPIO42/41, and document that
    GPIO43/44 are the ROM/UART0 console pins, only usable while the IDF
    console is routed to USB Serial/JTAG
    - Add BTN_02, USER_LED, LED_FLASH and the OV2640 camera pinout
    - Add MAIA_I2C_ADDR_IMU, a device-ag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
    [lsm6dsox.c, lsm6dsox.h, maia_board.h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]
2026-08-02 feat(wifi): add radio driver and provisioning service, hardware-verified
    AI-assisted implementation, debugging, and documentation.
    Adds WiFi connectivity end to end: a mechanism-only radio driver, a
    provisioning service on top of it (ESP-IDF's protocomm/SoftAP manager),
    Kconfig to select between Auto/Station/AP/Provisioning at boot, and a
    test harness that stands in for the app/service layer until one exists.
    Verified on real hardware: diagnostic AP (phone join/leave logged),
    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
2026-08-02 feat(lidar_web_viewer): add local 3D "Pin Art" viewer for the LiDAR
    AI-assisted implementation and debugging.
    Adds a local, dependency-free web page that renders each VL53L5CX
    ranging frame as a "Pin Art" grid — one pin per zone, pushed out
    proportionally to how close its target is — with free-orbit 3D
    rotation, a live-adjustable max-range slider, and a per-zone tooltip
    showing the exact raw mm reading. Wired up as a new
    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
2026-08-03 Lidar test feature has been fixed
    [test_vl53l5cx.c, vl53l5cx.c]
